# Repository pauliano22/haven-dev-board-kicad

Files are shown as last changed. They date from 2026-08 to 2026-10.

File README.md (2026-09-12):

# Haven Dev Board — KiCad Port

> **Current status (as of this commit): fabrication-ready.** Everything
> below this notice describes the *original* EasyEDA→KiCad port and was
> accurate when written, but predates the DRC/routing work that followed —
> it still says "no ERC or DRC has been run," which is no longer true. The
> board has since been rescaled to 73.1×161.1mm, fully routed (219 DRC
> violations remaining, all investigated and non-blocking; 2 cosmetic
> same-net internal BGA pairs unconnected), and DRC-verified via
> `kicad-cli`. See `FABRICATION_GUIDE.md` for current ordering instructions
> and `HAVEN_HARDWARE_REVIEW.md` for the full review trail. The rest of this
> file is kept as-is below for its record of the port's methodology and
> known limitations, most of which are still true (pin electrical types,
> unassigned pins, silkscreen fidelity, etc.) — only the DRC/routing status
> has changed.

A from-scratch KiCad recreation of the stock OpenEarable hardware (the base
Haven is built from), generated programmatically from the real EasyEDA Pro
project data rather than hand-traced from screenshots. This is **not** a
copy-paste of the user's live EasyEDA edits — it's a fresh port of the
*stock* OpenEarable design (`OpenEarable-PCB-main-2.0.epro`), per the
explicit scope agreed before this work started.

Open `kicad/haven_dev_board.kicad_pro` in KiCad. **No KiCad install or
`kicad-cli` was available in the sandbox this was built in — none of this
has been opened in real KiCad, run through ERC, or run through DRC.**
Treat the schematic as a strong first draft and the PCB as a best-effort
faithful port; both need a real review pass before anything is fabricated.
(Superseded — see the notice at the top of this file.)

## What's actually in here

| Section | Confidence | Why |
|---|---|---|
| BOM (89 parts, real values/part numbers) | High | Parsed directly from the `.epro`'s structured JSON, not guessed |
| Digital/power netlist (MCU, power management, flash, SD, USB, IO) | High | Two independent extraction methods agree exactly (see below) |
| Footprints (real pad shapes/sizes/positions) | High | Parsed directly from the real `.efoo` footprint data |
| PCB placement (component X/Y/rotation) | High | This is the **real board's actual placement**, not a guess |
| PCB routing (traces/vias/copper pours) | High for continuity, **unverified for DRC** | Real copper geometry ported directly; never run through a design-rule checker |
| Audio-analog section (ADAU1860 pins, mic, DAC) | Medium | Connectivity is real (same ground-truth source), but pin *electrical roles* (which precise decoupling network, differential pairing, etc.) haven't been cross-checked against the ADAU1860 datasheet |
| RF/antenna, USB signal integrity, any trace-width/impedance intent | **Needs real EE review** | Geometry ported as-is; nothing here was checked against RF/USB layout rules |
| Symbol/footprint graphics (visual appearance) | Cosmetic only | Pins are placed at electrically-correct coordinates but pin-stub direction and body-rectangle sizing are auto-generated, not hand-drawn — expect a plain, boxy look, not the polished look of a hand-drawn library part |

## Data source and methodology

The source is `OpenEarable-PCB-main-2.0.epro`, an EasyEDA Pro export. Unlike
the live `.eprj2` project file (an encrypted SQLite database), a `.epro` is
a zip of plaintext, line-delimited JSON records — genuinely parseable, not
reverse-engineered from pixels.

Two independent data sources were extracted and cross-checked against each
other:

1. **Schematic layer** (`.esch`, `.esym`): component placement, symbol pin
   layouts, and net-label text. EasyEDA's schematic format has no explicit
   netlist — connectivity has to be reconstructed from which pins sit near
   which net-label text. This reconstruction (`extracted/parse_netlist2.py`)
   hit two real bugs before it produced a trustworthy result, both fixed
   and documented in code comments:
   - A naive `name.split(".")[0]` truncated decimal component values
     (e.g. `"2.2uH.1"` → `"2"` instead of `"2.2uH"`), breaking symbol
     lookup for 15 parts. Fixed with a regex that strips only the trailing
     `.N` variant suffix, plus an HTML-entity unescape (BOM value strings
     use a literal `>`, symbol titles use `&gt;`).
   - The nRF5340 module's dedicated DC-DC/decoupling pins (`DECR`, `DCC`,
     `DECD`, `DCCD`, `DCCH` — per the module's own symbol pin names) were
     being swept into unrelated neighboring nets by the proximity-matching
     heuristic, since these pins sit only ~10 units from adjacent signal
     pins on a tight-pitch module. These pins are excluded from proximity
     matching entirely; per the nRF5340 datasheet they only ever connect
     to a local decoupling capacitor, never a routed signal net.

2. **PCB layer** (`.epcb`) — discovered partway through this work, and a
   materially better source: every real pad on the actual manufactured
   board has a `PAD_NET` record giving its **already-resolved** net name
   directly, plus a `COMPONENT` record giving its **real placed position
   and rotation** on the actual board. This is ground truth, not a
   reconstruction. **This is the netlist actually used in the generated
   schematic and PCB** (`extracted/pcb_netlist.json`,
   `extracted/pcb_placement.json`) — it covers ~85% of all pins vs. ~64%
   for the schematic-proximity heuristic, and every net checked against
   both sources agreed exactly (DIN, DOUT, BCLK, LRCLK, FLASH_RESET,
   SD_ENABLE, SCL1/SDA1, and the full GND net all matched).

   The PCB layer also contains real routed copper — 1003 trace segments,
   260 vias, and 6 ground/power copper pours — on a genuine 6-layer
   stackup (confirmed via `LAYER_PHYS` dielectric/copper-thickness
   records): `TOP / prepreg / GND-plane / core / Inner1 / prepreg /
   Inner2 / core / POWER-plane / prepreg / BOTTOM`. All of this routing
   was ported directly rather than re-routed from scratch.

Coordinate systems were independently reverse-engineered and validated for
each domain (schematic-space units are 10 mil per raw grid unit;
PCB-space units are 1 mil per raw unit — confirmed against overall board
span, ~13.5mm × 26.7mm, plausible for a small in-ear wearable). PCB-space
rotation was independently validated against real trace/via endpoints on
two components with 90°/270° rotations (not just 180°, which can't
distinguish rotation direction) — computed pad positions landed within
0.01 raw units (~0.0003mm) of real trace endpoints, confirming standard
CCW rotation with **no mirroring needed**, even for back-side (layer 2)
parts.

The board outline's arc segments (`POLY` records on the OUTLINE layer) use
a `(start, end, sweep-angle)` encoding with no explicit center point. The
center/midpoint formula was derived from scratch and verified in closed
form against two real corner-fillet arcs before being trusted for the
whole outline.

### Coordinate-generation strategy (why the connectivity should be trusted even without ERC)

Every generated symbol instance (schematic) and footprint instance (PCB)
is placed at **rotation zero**, with the component's real rotation baked
directly into each pin/pad's own local coordinate instead. This sidesteps
any uncertainty about whether KiCad's internal rotation transform sign
convention matches EasyEDA's: since only pure translation is asked of
KiCad, and the label/pad-net coordinates are computed with the exact same
Python expression used to place the pin/pad itself, they are numerically
identical by construction — not just "close." The actual rotation-direction
question was still independently resolved and validated (see above); this
strategy just removes it as a second, compounding source of risk.

## Known limitations / simplifications

- ~~**No ERC or DRC has been run.**~~ Superseded — see the notice at the
  top of this file. DRC has since been run extensively via `kicad-cli`
  (219 violations remaining, all investigated; see
  `HAVEN_HARDWARE_REVIEW.md`).
- **POLY-shaped pads** (rare — a few connector pads on J1/CN1 use a custom
  polygon rather than a rectangle/ellipse) are approximated by their
  bounding rectangle, not their exact polygon outline.
- **Via layer spans**: the source data's per-via layer-span field was
  empty for every via found, which is consistent with (but doesn't
  strictly prove) all-through vias. Every via is generated as a full
  F.Cu–B.Cu through via. If any are actually blind/buried, this needs
  correcting.
- **Board stackup thicknesses** are not precisely declared in the
  generated file (KiCad's default 1.6mm/2-layer-style general thickness
  is used) — the *layer names and count* (6 copper layers) are real and
  correct, but exact dielectric thicknesses from the source data were not
  carried through.
- **Silkscreen art, logos, and precise designator label placement** from
  the original board were not ported — only functional copper, pads, and
  the board edge. Reference designators use KiCad's default auto-placed
  text.
- **Pin electrical types** (input/output/power/etc.) are uniformly set to
  "passive" in the generated symbols. This was a deliberate choice: I
  don't have verified per-pin electrical-role data from any datasheet, and
  marking pins with specific types I can't back up would be fabricating
  detail I don't actually have grounds for. This means ERC in KiCad won't
  be meaningful for pin-direction conflicts until someone fills in real
  electrical types from actual datasheets.
- **~15% of pins have no assigned net** (72 of 460 PCB pads; a very
  similar fraction on the schematic side). Spot-checked and these are
  overwhelmingly genuine — reserved MCU pins (the DC-DC pins above),
  unused GPIOs, and connector pins with more physical positions than the
  design actually uses (e.g. CN1 pins 13–24, CARD1 pin 1). They are not
  silently dropped; they're just left unconnected in the generated files
  rather than fabricating a connection.

## A genuine anomaly in the *original* stock design — now resolved

One net in the real board data was literally named `#ERROR` by EasyEDA
itself (confirmed present in `extracted/netlist.json`'s raw source, not
introduced during this port) — it tied together MDBT531 pin 3 (`P1.08`,
a GPIO), Q2 pin 1 (a small MOSFET, `CSD13380F3T`), and U8 pin 1 (a 1MΩ
0201 resistor, despite the "U" designator). EasyEDA just never resolved
a human-readable name for this net.

Traced further and renamed to **`LED_ENABLE`**: R4 (510Ω) and U4 (a real
0201 LED, `XL-0201SURC`, per `HAVEN_BOM.csv`) are also on this net —
3V3 → U4 (LED) → R4 (current-limit) → Q2 (low-side switch to GND), gated
by U8 (1MΩ pulldown, default-off) and driven directly by MDBT531 P1.08.
A straightforward GPIO-controlled indicator LED. Pure rename in both the
schematic and PCB — zero electrical change, verified via DRC diff. The
net also had a genuine small routing gap (Q2's gate pad wasn't
connected to the rest of the net); that's now routed too.

## File layout

```
kicad/
  haven_dev_board.kicad_pro     project file
  haven_dev_board.kicad_sch     schematic (89 components, net labels for connectivity)
  haven_dev_board.kicad_sym     project symbol library (one symbol per component, no sharing)
  haven_dev_board.kicad_pcb     PCB (real placement, real footprints, real routing, real outline)
  footprints.pretty/            33 generated footprints
  sym-lib-table, fp-lib-table   project-local library tables

extracted/                      all extraction/generation scripts + intermediate JSON,
                                 kept for provenance and so the pipeline can be re-run
                                 (e.g. after a schematic re-export) rather than redone by hand
```

## Suggested next steps for a human pass

1. ~~Open in KiCad, run ERC and DRC, see what falls out.~~ Done — see the
   notice at the top of this file and `HAVEN_HARDWARE_REVIEW.md`.
2. Cross-check the ADAU1860 audio-analog section (U15's ~29 unmatched
   pins, mostly clustered here) against the real datasheet.
3. Review U2 (BQ25120A charger) and U6 (BQ27220 fuel gauge) — both have a
   meaningful number of unmatched pins too.
4. ~~Decide whether the `#ERROR` net circuit needs a real name/investigation.~~ Done — see above, now `LED_ENABLE`.
5. If this is meant to diverge from stock OpenEarable (per the earlier
   Gemini-assisted cleanup pass on the user's live EasyEDA project), diff
   this port against that pass and carry over the same changes here.

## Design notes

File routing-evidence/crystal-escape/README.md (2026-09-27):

# Crystal escape: the 24.576 MHz codec crystal from 6 mm to 1 mm, and the flash's cap

Follow-up to `../placement-fix/` (PR #5), which moved every crystal and
decoupling cap back next to its chip except one: the codec crystal stopped
at 6.0 mm pad-to-ball because its escape from the 0.35 mm BGA could not be
changed without re-routing. This stage re-does that escape, and fixes the
one decoupling item PR #5 mis-diagnosed (the flash *does* have a cap — C27 —
it was just 9.8 mm away).

Tooling: KiCad **9.0.8** (`kicad-cli pcb drc --format json --severity-all
--all-track-errors`, pcbnew Python from the same install), the project's
`tools/*.py`, plus `group_c_crystal_escape.py` in this directory. Acceptance
rule unchanged: zero new violation identities by type+description and
unconnected not worse (`tools/drc_diff.py`), before every commit.

## Result

`.kicad_pcb` header unchanged (`version 20241229`, `generator_version "9.0"`).

### DRC, before and after (kicad-cli 9.0.8)

| | violations | by type | unconnected |
|---|---|---|---|
| PR #5 tip `77b8ee2` (`baseline.json`) | 219 | clearance 99, lib_footprint_mismatch 78, solder_mask_bridge 33, track_dangling 9 | 2 |
| after crystal escape (`after_c.json`) | **219** | **identical multiset** | **2** |
| after C27 move (`after_d.json`) | **219** | **identical multiset** | **2** |

`drc_diff.py baseline.json after_d.json` → 0 new violation identities, 0 new
unconnected. The two remaining unconnected items are the same cosmetic
same-net U15 pairs as before.

### Distances — pad to pin

| connection | PR #5 | this PR |
|---|---|---|
| CRYSTAL1.1 (XTALI) → U15 ball B7 | 6.01 mm | **0.98 mm** |
| R28.2 (XTALO) → U15 ball B6 | 4.47 mm | **3.26 mm** |
| R28.1 → CRYSTAL1.3 | 0.86 mm | 1.16 mm |
| C46 (33 pF) → CRYSTAL1.1 | 1.10 mm | 1.03 mm |
| C45 (33 pF) → CRYSTAL1.3 | 0.98 mm | 1.08 mm |
| C27 (100 nF, V_LS) → U14 ball D2 | 9.78 mm | **0.21 mm** |
| C27 GND pad → U14 ball E3 | — | 0.49 mm |

### Net copper

| net | PR #5 | this PR |
|---|---|---|
| XTALI (ball → crystal) | 9.02 mm track, 3 vias | **2.84 mm, 2 vias** |
| XTALO (ball → R28) | 5.09 mm, 3 vias | **4.48 mm, 2 vias** |
| `$1N16368` (R28 → crystal) | 1.89 mm | 2.24 mm |

## How the escape works now

The only exits from balls B6/B7 are their existing via-in-pads (kept). From
there:

- **On B.Cu** TDO's escape track runs 0.17 mm east of the XTALI via and walls
  the pocket off; **on In4** SCL1's escape diagonal does the same. That is
  why PR #5 stopped at 6 mm.
- **On In2** (the second GND plane) there is nothing in this corner except
  the through-via field, and XTALI/XTALO already carry the board's per-pair
  `.kicad_dru` exceptions for exactly those vias (XTALI vs TDO 0.015 mm;
  XTALO vs TMS/TDO/XTALI 0.03–0.05 mm, plus matching `hole_clearance`
  rules). So each net now goes: ball → via-in-pad → ~1–3 mm on In2 → new
  0.20/0.10 exit via → B.Cu stub → pad. XTALI's In2 run is a single 0.9 mm
  segment; XTALO's leaves its via south-west (the one gap in the TMS/TDO/
  XTALI ring), runs under row A and exits south of the crystal next to R28.
- **The crystal is on B.Cu at (61.30, 112.35), rotated 225°.** The free
  pocket east of the BGA is a diagonal band 3.5 mm across between SDA1's and
  PDMDIN's slope-1 escapes; the 1.9 × 2.3 mm crystal only fits with its long
  axis along the band, i.e. at a 45° multiple. 45° placement is routine for
  PCBA. C46 sits 1.0 mm from the XTALI pad with its own GND via; C45 and R28
  sit off the far pad; the crystal's two case/GND pads each have a via into
  the planes.
- Every new via and segment was checked before placement against copper
  clearance (the net's own exceptions, never looser), hole clearance
  (0.15 mm default, pair rules where they exist) and hole-to-hole
  (0.20 mm edge, real drill sizes) — then DRC was the judge.

**Trade-off, stated plainly:** XTALI — the high-impedance oscillator input,
the node that matters most — is now 0.98 mm from its ball with 2.8 mm of
copper. XTALO (the driven, low-impedance side) is 3.26 mm to R28 and ~4.5 mm
of copper because R28 has to sit off the crystal's far pad in this
orientation; rotating the crystal to balance the two legs (135°/315°) put
XTALI at ~2.1 mm, which is the worse trade. Two In2 tracks now cut ~1.5 mm
slots in the GND pour under the BGA corner (through the existing via field,
where the pour is already perforated); refill and DRC show no GND
connectivity change.

## The flash's decoupling cap — C27, not a new part

PR #5's README concluded "U14 has no dedicated decoupling cap on this BOM".
That was wrong: **C27** (100 nF, `V_LS`/`GND`, 0201, `TCC0201X5R104M6R3ZT`)
is drawn immediately beside U14 on the schematic and is its cap by design;
the 5× rescale had left it at (97.86, 117.83), 9.8 mm away. Stage D moves it
to B.Cu directly under the flash: V_LS pad 0.21 mm from ball D2, GND pad
0.49 mm from ball E3 (`tools/move_two_terminal.py --ref C27 --ic U14`, old
feeds removed with `clean_dangling.sh`). **No BOM change.** If Paul wants
bulk capacitance for the QSPI flash as well (a 1 µF alongside the 100 nF is
common practice, not a requirement), that would be a BOM addition for him to
decide — not done here.

## Tooling lessons (both caught by the DRC gate)

- **Refill zones on the board in the project directory, never on a copy in
  /tmp.** A board loaded without its `.kicad_pro`/`.kicad_dru` alongside
  fills its pours with different settings: refilling the *untouched* PR #5
  board from /tmp produced 5 phantom `track_dangling`/`via_dangling`
  warnings and 4 phantom unconnected items (U15 GND/V_LS balls, a GND via
  pair 20 mm away); the same board refilled from `kicad/` reproduced the
  baseline exactly. `group_c_crystal_escape.py` copies its best snapshot
  into the project before the final refill. (`CODEX_NOTES.md` already
  warned about /tmp copies and design rules; this is the zone-fill face of
  the same problem.)
- pcbnew 9 hands back an unusable board object after `Remove()` + `Save()`
  + `LoadBoard()` in one process, so the script strips the old copper in
  one process (`--phase strip`) and places/routes in another (`--phase place`).
- `placement_lib.layer_id` only knew F.Cu/B.Cu; it now knows the inner
  layers.

## Files

- `baseline.json` — DRC at PR #5's tip; `after_c.json` (crystal escape);
  `after_d.json` (C27 move).
- `group_c_crystal_escape.py` — the crystal-group script (run from `kicad/`
  with KiCad's python: `--phase strip`, then `--phase place`).
- `../../tools/placement_lib.py` — inner-layer names added.

`fab_output/` is not tracked; regenerate before ordering, per
`FABRICATION_GUIDE.md`:
```
kicad-cli pcb export gerbers --output fab_output/gerbers/ kicad/haven_dev_board.kicad_pcb
kicad-cli pcb export drill   --output fab_output/gerbers/ kicad/haven_dev_board.kicad_pcb
kicad-cli pcb export pos --format csv --units mm --side both --output fab_output/haven_dev_board-pos.csv kicad/haven_dev_board.kicad_pcb
```

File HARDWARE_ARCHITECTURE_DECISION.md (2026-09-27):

# Hardware architecture decision: keep the codec in the loop, lose the BGA

*Response to `HARDWARE_COST_ALTERNATIVES.md` (2026-09-12). Written 2026-09-14.*

## The answer in one paragraph

The cost analysis is right and the conclusion is half right. The three fine-pitch packages (ADAU1860 0.35 mm BGA-56, BQ25120A 0.40 mm DSBGA-25, BQ27220 0.50 mm DSBGA-9) are what push the board into 6 layers, laser microvias and the "advanced" PCBA tier, and swapping them for QFN parts is the correct way to get a cheap board. But the ADAU1860 was not "the wrong chip for the codec role" — it was chosen (inherited, but correctly) because it is the mechanism for Haven's one hard physical requirement: hear-through latency well under a millisecond. Moving the biquads onto the nRF5340 (option C below) reintroduces I2S block buffering of **≥0.7–1 ms at the smallest practical block, and ~6–9 ms if done the way the Teensy prototype did it**, which puts comb-filter notches inside the speech band (derivation §3) and keeps the nRF CPU + I2S running continuously (**≈5.6 mA**, §4) instead of asleep. The Teensy prototype proved the *filter math*; its latency was never measured. There is a third option that satisfies both the physics and the cost: a QFN codec **with its own programmable DSP** — the TI **TLV320AIC3254** Paul already found in JLCPCB's catalog at $3.03 (VQFN-32, 5×5 mm, **0.5 mm pitch**, PDM mic input, two miniDSP cores each running up to **1,152 instructions per sample at 48 kHz**, plus fixed processing blocks with **5 programmable biquads** and a DRC). Recommendation: **option B (AIC3254 in the loop), with the charger swapped to a QFN/SOP power-path part and battery voltage read by the nRF's ADC instead of a fuel gauge** — and one cheap experiment first (§7) to pin the latency numbers this memo can only estimate.

## 1. The three options

| | **A — current** | **B — QFN codec with on-chip DSP** | **C — dumb codec, filter on nRF5340** (Paul's proposal) |
|---|---|---|---|
| Codec | ADAU1860 (BGA-56, 0.35 mm) — FastDSP owns mic→5 biquads→limiter→DAC at 192 kHz; nRF only writes coefficients | **TLV320AIC3254** (VQFN-32 5×5 mm, 0.5 mm) — miniDSP or fixed biquad blocks own the loop; nRF only writes coefficients | SGTL5000 / TLV320AIC3104 / AIC3254-as-dumb-codec (QFN) — ADC→I2S→nRF→I2S→DAC; nRF runs the biquads |
| Where the audio loop runs | inside the codec | inside the codec | through the MCU |
| Hear-through latency (§3) | converter delays only: est. **50–150 µs** (192 kHz path); FastDSP frame 5 µs | converter delays at 48 kHz: est. **0.5–1 ms** (TI publishes block group delays in SLAA408 — not fetched; 96/192 kHz modes would cut it); DSP adds ~0 | converter delays **+ I2S block buffering**: ≥ **0.7–1.0 ms** extra at 16-sample blocks, **2.7–4 ms** at 64, **5.8–8.7 ms** Teensy-style (128 @ 44.1 k) |
| Comb notches in 200–8000 Hz (§3) | 0 (first notch ≥ 3.3 kHz only if Δt ≥ 150 µs; none below 100 µs) | 0–1 if Δt ≤ 0.5 ms; up to 8 at 1 ms | 8 at 1 ms; ~47 at 6 ms |
| MCU power for audio (§4) | ~0 (nRF sleeps between BLE events) | ~0 | **CPU 3.3 mA @64 MHz + I2S 2.3 mA ≈ 5.6 mA continuous** (Nordic PS) |
| Codec power | unknown (datasheet not obtained); ADI markets the part for hearables | **4.1 mW playback + 6.1 mW record ≈ 10 mW** (datasheet p.1; both paths run in hear-through) | same class as B (converters still run) **plus** the MCU 5.6 mA |
| Unit BOM (codec) | consignment part, ~$5–10 (est.) | **$3.03** (JLC catalog, Paul) | $1.33 AIC3104 / SGTL5000 |
| Layers / vias / PCBA tier | 6 layers, laser microvias, advanced (~$500 / 5 boards, Paul's quote) | **plausibly 4 layers, standard vias, standard tier** (MDBT53 is 0.65 mm pitch) | same as B |
| Firmware chip-specific code to (re)write | exists: `adau1860_*`, `lark_*` ≈ 1,420 lines, compiles for both boards | new: AIC3254 register driver ≈ 400–600 lines (I2C register pages; no 32-bit addressing, no memory images unless miniDSP is used) | new: codec init ≈ 200 lines **+** an nRF DSP path (I2S RX/TX ring, biquad kernel, timing) ≈ 300–500 lines that must be real-time-safe |
| Firmware that survives unchanged | — | BLE, protocol, clamps, tone safety, NVS, GATT, acks, `tone_gen.c` (I2S master), calibration rig, app: ≈ 1,800 of 3,240 firmware lines + all tools + the whole app | same |
| DSP tooling | Lark Studio (Windows) for anything beyond coefficient writes | **none needed** for the fixed blocks (5 biquads + DRC are register-programmable, datasheet Tables 2/3); PurePath Studio (TI, access-controlled) only if the miniDSP is used | none (C code) |
| Hardware limiter (3rd safety layer) | FastDSP limiter slot (PR #14) | **DRC on ADC path, AGC / digital volume on DAC path** (datasheet p.1, p.31) — register-programmable | firmware only (a bug is a loud bug) |
| Sourcing risk | ADAU1860 + MDBT53 likely consignment at JLC/PCBWay | catalog part; MDBT53 still consignment | catalog part; MDBT53 still consignment |
| Time to first sound | firmware done; hardware = eval board $485 / OpenEarable €2,348 / this BGA board | **TLV320AIC3254EVM** exists (TI, ~$100–200) → DK + EVM bench; new schematic; ~1 week of driver work | as B plus the nRF DSP path and its latency debugging |

Confidence: package/pitch, instruction budget, PDM input, power figures and DRC/AGC for the AIC3254 are **verified** from the datasheet (SLAS549D: p.1, p.30–31, p.34, p.50). nRF5340 currents **verified** (product specification, "Current consumption"). Latency figures are **derived** (§3) from block sizes and the published block-processing model; converter group delays are **estimated** and must be measured. Costs are Paul's or JLC catalog figures.

## 2. Why the loop has to stay in the codec — the physics, restated

Hear-through only works if the processed sound and the sound that leaks past the eartip arrive together. If the processed path is late by Δt, the two add with a phase that rotates through frequency, producing comb-filter notches at

    f_k = (2k + 1) / (2·Δt),  k = 0, 1, 2 …

(notebook `01-acoustics-and-psychoacoustics.md`). For the 200–8000 Hz band Haven cares about:

| Δt | notches in band | first notch |
|---|---|---|
| 50 µs | 0 | 10 kHz |
| 150 µs | 2 | 3.3 kHz |
| 300 µs | 4–5 | 1.7 kHz |
| 1 ms | 8 | 500 Hz |
| 4 ms | ~32 | 125 Hz |
| 6 ms | ~47 | 83 Hz |

Anything above ~0.3 ms audibly colours speech; above ~1 ms it sounds like "two of everything". This is the requirement (R1 in `00-problem-breakdown.md`) that dictated a codec-resident DSP in the first place. It is also why the Teensy prototype, valuable as it was, does not settle the architecture: it validated the filters and the user experience of *notching*, but nobody measured its latency (there is no measurement in `haven-legacy-teensy`, `haven-legacy-dsp-sandbox` or the workspace docs — checked), and its block size makes the number predictable (§3).

## 3. Latency derivations

**Common to all options — converter group delay.** Sigma-delta ADCs and DACs use linear-phase decimation/interpolation filters whose delay is a fixed number of samples: at 48 kHz, tens of samples each way ⇒ roughly 0.3–0.6 ms per direction for ordinary codecs. The ADAU1860 runs its DMIC decimation and FastDSP at **192 kHz** (upstream `DMIC_CTRL2 = 0x04`, `FDSP_CTRL4 = 2`), so the same filter structures cost 4× less time — that is the specific reason option A's latency is estimated at 50–150 µs. The AIC3254 lists three interpolation filter types "depending on required frequency response, group delay and sampling rate" (p.31) and processing blocks "tuned for … low group delay" (p.30–31); the numbers are in TI's app note SLAA408, which was not fetched — **measure, don't assume**. At 96 or 192 kHz DAC/ADC rates (both supported, p.31) the AIC3254 figure would shrink accordingly.

**Option C adds block buffering.** Zephyr's nRF I2S driver (`drivers/i2s/i2s_nrfx.c`, NCS 3.4) is double-buffered EasyDMA: an RX block is delivered to the application only when it is full; the application processes it and queues a TX block, which starts playing at the *next* block boundary. Minimum end-to-end through the MCU is therefore about two block durations plus processing, three in practice with the TX queue depth the driver needs to avoid underrun ("Next buffers not supplied on time" is a hard error that stops the stream). Block size must be a multiple of 4 bytes; very small blocks mean interrupt rates the BLE stack has to coexist with.

| Block (samples @ 48 kHz) | block time | MCU path (2–3 blocks) | IRQ rate | + converters (~0.7 ms est.) |
|---|---|---|---|---|
| 16 | 0.33 ms | 0.67–1.0 ms | 3,000/s | **1.4–1.7 ms** |
| 32 | 0.67 ms | 1.3–2.0 ms | 1,500/s | 2.0–2.7 ms |
| 64 | 1.33 ms | 2.7–4.0 ms | 750/s | 3.4–4.7 ms |
| 128 @ 44.1 kHz (Teensy `AUDIO_BLOCK_SAMPLES`, `cores/teensy4/AudioStream.h:54`) | 2.9 ms | 5.8–8.7 ms | 344/s | **6.5–9.4 ms** |

So the Teensy prototype almost certainly ran at 6–9 ms — dozens of comb notches across the speech band. If it sounded acceptable, that is evidence the *user experience* was tested with music/voice sources in a quiet room rather than as transparent hear-through against leakage, or that the earpiece sealed well enough to suppress the leaked path. Either way it is not evidence that MCU-side filtering meets R1. The 16-sample case is the best C can do, and it is still ≥ 3× worse than B's converter-only estimate, at 3,000 interrupts per second forever.

**The CPU load itself is not the problem.** Five biquads on one channel at 48 kHz is ~2.5 MIPS in fixed point — trivial for a Cortex-M33 at 64 MHz. The problem is buffering latency and the fact that the CPU can never sleep.

## 4. Power

Nordic nRF5340 product specification, "Current consumption" (typ., 3 V, DC/DC on): CPU running from flash at 64 MHz **3.3 mA**; at 128 MHz **7.8 mA**; I2S transferring 2×16-bit at 48 kHz **2.31 mA**; System ON idle **1.3 µA**. Option C therefore holds the application core at ≈ **5.6 mA** (64 MHz) continuously, on top of the BLE stack. Options A and B leave the nRF in System ON idle between BLE events (advertising/connection events average tens of µA).

Codec side: AIC3254 **4.1 mW** stereo playback + **6.1 mW** stereo record at 48 kHz (datasheet p.1) — hear-through needs both, so ≈ 10 mW; mono and lower PowerTune classes (PTM_R1…) reduce it. ADAU1860: no figure obtainable here (datasheet unfetched); ADI positions it for hearables and OpenEarable runs it from an earbud battery, so assume the same class as the AIC3254 or better — **unknown**.

Battery: the OpenEarable 2.0 battery capacity is not stated anywhere in the upstream repo (the fuel-gauge default `capacity_mAh = 3000` in `BQ27220.h` is a placeholder); a typical earbud cell is 40–80 mAh. Taking **60 mAh** as a stated assumption and ≈ 6 mA for a codec in hear-through plus BLE:

- A/B: 60 mAh / ~6.5 mA ≈ **9 h**
- C: 60 mAh / ~12 mA ≈ **5 h**

Roughly, option C halves the wearable's battery life to buy nothing the user can hear except comb filtering. (Assumptions explicit; the codec numbers dominate and must be measured on the bench — the calibration rig PR #11 includes a battery-current line item for exactly this.)

## 5. Cost and manufacturability

Paul's measurements stand: ADAU1860 0.35 mm, BQ25120A 0.40 mm, BQ27220 0.50 mm pitch; MDBT53-1M 0.65 mm. Removing the three fine-pitch parts removes the need for laser microvias and (plausibly) two layers, and moves the job out of the advanced tier. Option B keeps that entire saving: the AIC3254 is a 0.5 mm-pitch VQFN-32 (datasheet p.50), catalog-stocked at JLC ($3.03), and the MDBT53 is fine as is.

Two things `HARDWARE_COST_ALTERNATIVES.md` does not yet account for:

1. **The BQ25120A is also the board's power supply.** Its integrated buck (L2, 2.2 µH) and LDO generate the **+1.8 V** and **3V3** rails (notebook `10-hardware-bom.md`, power tree). Replacing it with a TP4056 or MCP73831 — which are chargers only — means adding a regulator (e.g. a small buck or LDO for 1.8 V, plus the 3V3 rail if anything still needs it) and a load switch strategy for ship/storage. Not hard, but it is a new part and a new design task, not a drop-in.
2. **Battery telemetry.** True, nothing in the software reads the BQ27220 today. But a wearable without a battery percentage cannot warn the user, cannot protect the cell from deep discharge in firmware, and cannot implement ship mode (the BQ25120A's ~nA storage state). The cheap answer is not a QFN fuel gauge: it is a resistor divider (or the charger's battery pin) into the **nRF5340's SAADC** for voltage-based state of charge — good enough for "low battery", zero BOM cost — and a charger with a **power path** so the device runs from USB while charging. In increasing capability: TP4056 (SOP-8, linear 1 A, thermal regulation, no power path, no ship mode), MCP73831 (TDFN-8, 500 mA, no power path), **BQ24072/BQ24074** (QFN-16, power path/DPPM, no I2C) — the last is the one that behaves like a product.

## 6. The claims in `HARDWARE_COST_ALTERNATIVES.md`, one by one

- **"The cost isn't the board size … it's three specific chip packages."** Agreed, and well shown (measured pitch, flat assembly setup cost, laser-via finding).
- **"OpenEarable 1.3 is architecturally wrong (record-then-playback)."** Agreed.
- **"6 layers are caused by the BGA escape."** Agreed.
- **"The fuel gauge is unused by software."** True today; see §5 for why telemetry still matters and how to get it for free.
- **"Same architecture, wrong chip — the Teensy proves the nRF can do the filtering."** Disagree on the architecture, agree on the chip's *package*. The Teensy proved the math and the interaction, not the latency (§3); a codec-resident DSP is what makes sub-millisecond hear-through possible, and dropping it is the one change that alters what the product *does*, contrary to the memo's framing. The right move is a QFN codec that keeps the DSP in the loop.
- **"TLV320AIC3253/3254 is a drop-in-shaped replacement."** Agreed — and stronger than stated: the AIC3254's fixed ADC processing blocks **PRB_R2/PRB_R5 carry five programmable biquads** (datasheet Table 2, p.30) and the DAC blocks carry more plus a DRC (Table 3, p.31), all register-programmable over I2C without any DSP tool. Its two miniDSP cores (1,152 instructions per sample at 48 kHz, "can exchange data", p.34) are the upgrade path if anything more than notches is ever wanted. (Note: the datasheet is for the AIC3254; the "3253" in the memo appears to be a typo — the JLC catalog line Paul quoted is AIC3254IRHBR.)

## 7. Recommendation and the cheapest experiment that settles it

**Recommend option B**: TLV320AIC3254 (RHB), PDM mic into its digital-mic input, hear-through implemented inside the codec, a QFN power-path charger (BQ24072-class) plus an SAADC battery-voltage read, MDBT53-1M unchanged. This keeps R1 (codec-owned loop), keeps every codec-agnostic piece of firmware and the whole app, removes all three fine-pitch packages, and uses catalog parts.

Two unknowns decide whether B delivers A's latency or merely beats C:

1. **Is there a fully internal ADC→DAC digital path on the AIC3254 that runs through the biquad blocks?** The datasheet's fixed processing blocks sit on the ADC and DAC paths with the serial interface in between; the miniDSP cores "can exchange data" (p.34), which is an internal path but needs PurePath Studio. If a register-level ADC→DAC route exists (to verify in SLAA408 / the register map), B needs no DSP tool at all; if not, B uses the miniDSP.
2. **What are the AIC3254's ADC + DAC group delays at 48 / 96 / 192 kHz?** SLAA408 has them; the bench will confirm.

**Cheapest experiment (≈ $200, one week, no custom PCB):**

- **Step 1 — nRF5340 DK alone, $0:** loop I2S SDOUT→SDIN with a jumper and measure the Zephyr I2S round-trip for 16/32/64-sample blocks (GPIO toggle at RX-block-ready and TX-start, logic analyzer or `k_cycle_get_32`). This nails option C's buffering term with no codec at all.
- **Step 2 — TLV320AIC3254EVM-U (TI) + DK:** configure PRB_R2 with Haven's five biquads via I2C, drive the PDM mic input, measure hear-through latency by impulse cross-correlation (PR #11's `latency.py`) at 48 and 96 kHz, and measure supply current. If Δt ≤ 300 µs, B is confirmed as the product path.
- **Step 3 (optional, $485) — EVAL-ADAU1860EBZ + DK:** same measurements on option A, using the driver in PR #9, to know exactly what the BGA buys.

**What changes in the open PRs if B is chosen:** PRs #8 (format analysis), #9, #10's codec half, #13, #14 become reference material for the bench, not the product; `tone_gen.c`, the BLE/protocol/safety/ack layers (#10's nRF half, #12), the calibration rig (#11), the app PRs (#6–#8), and the documentation PRs carry over unchanged. The board PRs (#3, #5) still document the current design correctly but the placement work would be redone on a new, smaller schematic — designed right from the start, as `HARDWARE_COST_ALTERNATIVES.md` already says.

**What I would not do:** ship option C to save $3 of codec. It trades the product's defining property for a cheaper part while the cheaper part with the right property sits in the same catalog.

---

*Sources.* TLV320AIC3254 datasheet SLAS549D (rev. Nov 2014): p.1 features/power, p.30 Table 2 ADC processing blocks, p.31 DAC section/Table 3, p.34 miniDSP ("up to 1152 instructions on every audio sample at a 48kHz sample rate"; "very-low group delay"), p.27 Table 1 (DMDIN/DMCLK multifunction pins), p.50 RHB mechanical (5×5 mm, 0.5 mm pitch). nRF5340 Product Specification, "Current consumption" (IAPPCPU5 3.3 mA @ 64 MHz; IAPPCPU4 7.8 mA @ 128 MHz; II2S2 2.31 mA; ION_IDLE2 1.3 µA). Zephyr `drivers/i2s/i2s_nrfx.c` (NCS `ncs-v3.4-branch`). PaulStoffregen/cores `teensy4/AudioStream.h:54,58` (`AUDIO_BLOCK_SAMPLES 128`, 44.1 kHz). Upstream OpenEarable `ADAU1860.cpp` (192 kHz DMIC/FastDSP). `HARDWARE_COST_ALTERNATIVES.md`, `FABRICATION_GUIDE.md` (this repo). Notebook notes 00, 01, 10, 12 (`victorzhu443/haven-engineering-notes`). ADAU1860 datasheet and SLAA408 were **not** obtainable in this environment; every figure that depends on them is marked estimated.

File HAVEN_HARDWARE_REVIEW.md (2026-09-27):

# Haven Dev Board — Hardware Design Review

Reviewer notes on the KiCad port in this repo (`kicad/`), written against the
files as generated, plus one real external datasheet lookup (cited below).
**No KiCad install is available in this environment — nothing here was
run through ERC/DRC.** Every finding below states its own confidence level:
tool-verified (parsed from the actual generated files or measured from real
coordinate data), general-best-practice inference, or genuinely unresolved.

Audit scripts used: `extracted/sexp_parser.py` (independent S-expression
parser, written fresh for this review rather than reusing the generator's
code path), `extracted/audit_schematic.py`, `extracted/audit_pcb.py`.

---

## 0. Cross-check against upstream OpenEarable firmware (2026-09-10)

Several of the questions this review left open turn out to be answered by a
source that was in the workspace all along: the upstream
[`OpenEarable/open-earable-2`](https://github.com/OpenEarable/open-earable-2)
firmware, which drives this exact codec on this exact board (Haven's KiCad
port is of the stock OpenEarable main PCB, so upstream's devicetree and
driver *are* ground truth for how these nets are actually used). Everything
below is **sourced from upstream code**, not from the ADAU1860 datasheet —
the datasheet PDF was not fetchable in the environment this cross-check was
done in, so nothing here is "datasheet-verified"; it's "matches firmware
that ships on this hardware". File references are into a clone of upstream
at its 2026-09 `main`.

### 0.1 The codec's register map is public and already transcribed

The premise in `haven-zephyr-app` that "there is no public ADAU1860
register map" is wrong. Upstream's `src/drivers/ADAU1860.h` carries the
full map (~350 named registers, `VENDOR_ID = 0x4000C000` through
`DAC_NOISE_CTRL1 = 0x4000CC12`), and `src/drivers/ADAU1860.cpp` is a
working bring-up sequence for it. Two consequences for this board's
firmware, both firmware-side rather than layout-side, but recorded here
because the review's §1 was reasoning about them:

- **Control-port addressing is 32-bit**, not the 16-bit big-endian
  framing used by older SigmaDSP parts (`ADAU1860.cpp:512-517` builds a
  4-byte address for every read, `:544-549` for every write). A 16-bit
  framing simply addresses nothing on this chip.
- **The DSP program is a raw memory image**, not a SigmaStudio `ADISIGM`
  blob: `Lark-fdsp.c` ("Lark" is ADI's codename for the ADAU1860) is
  plain `uint32_t` arrays written straight to `FDSP_PROG_MEM = 0x40008000`
  and the three parameter banks (`ADAU1860.cpp:335-341`). The design tool
  for this chip is ADI's **Lark Studio**, not SigmaStudio+ — per the
  EVAL-ADAU1860 user guide (UG-2017), its "Download to Target" writes
  exactly these parameter + command words into FastDSP memory, and the
  FastDSP input source is chosen in its drag-and-drop schematic.

### 0.2 §1 resolved: DIN/DOUT direction, and I2S master/slave

**DIN/DOUT — the flagged discrepancy was real, and the overlay comment was
the backwards one.** Upstream's pinctrl
(`boards/teco/openearable_v2/openearable_v2_nrf5340_cpuapp_common-pinctrl.dtsi:14-17`)
puts `I2S_SDOUT` on P0.28 and `I2S_SDIN` on P0.31. This review's §1 table
has net `DIN` on MDBT531 pin 60 = P0.28 and `DOUT` on pin 56 = P0.31. So:

| Net | nRF pin | nRF role (upstream pinctrl) | ADAU1860 pin (this port) | Direction |
|---|---|---|---|---|
| `DIN`  | P0.28 | `I2S_SDOUT` | C1 `SDATAI_0` | **nRF → codec** |
| `DOUT` | P0.31 | `I2S_SDIN`  | B1 `SDATAO_0` | **codec → nRF** |

The net names are from the *codec's* point of view, and the ADAU1860's own
pin names (`SDATAI` = input, `SDATAO` = output) were telling the truth
after all. The `haven-zephyr-app` overlay's "DIN (ADAU1860->nRF)" comment
is inverted; see the ADAU1860 driver PR on `haven-zephyr-app` for the fix.

**Master/slave — the overlay's 2026-08-25 inference ("codec has its own
24.576 MHz crystal, therefore codec is I2S master, nRF is slave") reaches
the wrong conclusion.** Upstream runs the **nRF5340 as I2S master**:
`I2S_SCK_M` on P1.10 and `I2S_LRCK_M` on P0.30 (pinctrl `:14-15`, the `_M`
suffix is Nordic's master-mode pin function), with an `I2S_MCK` output on
P1.14 (`:10`) and `hfclkaudio-frequency = <12288000>` in the board DTS
(`openearable_v2_nrf5340_cpuapp_common.dts:51`). The codec is the slave.
The crystal doesn't contradict this: the ADAU1860 has asynchronous
sample-rate converters precisely so its internal clock domain can run off
its own crystal while its serial port follows an external bit clock —
upstream enables them (`ASRC_PWR`, `ASRCI_*`/`ASRCO_*` routing,
`ADAU1860.cpp:164-209`). §1's "the schematic genuinely cannot settle
master/slave" stands as a statement about the schematic; upstream's
firmware settles it.

### 0.3 §3.5 checklist items, revisited

- **Item 2 (DIN/DOUT):** resolved above.
- **Item 3 (AGND/DGND split):** still a real layout question, but its
  urgency is lower than §3.1 implies — the unified `GND` pour is exactly
  what the stock OpenEarable board ships with, and that board produces
  usable audio in the field. Treat as "improve on rev 2", not "blocks rev 1".
- **Item 6 (unused second serial port / `DMIC23`):** upstream leaves
  `SPT1_*` unused as well and only drives `DMIC01` (`ADAU1860.cpp:168-169`
  powers DMIC channels 0 & 1 only), so the dangling `_1` port and `DMIC23`
  pins match the working reference. Whether they need a defined pull is
  still a datasheet question, but the stock board evidently gets away
  without one.
- **Power sequencing the codec actually needs** (not on the original
  checklist, added because the port's netlist confirms the wiring):
  `DAC_ENABLE` — MDBT531 pin 37 → U15 E4 — is the codec's enable/PD pin,
  driven as `enable-gpios = <&gpio0 4>` in upstream's DTS (`:130`) and
  asserted at `ADAU1860.cpp:58`; `V_LS` is a load-switched rail
  (`load_switch`, `enable-gpios = <&gpio1 11>`, DTS `:26-28`); upstream
  then waits 35 ms for common-mode rise (`:71`), bypasses/configures the
  PLL (`CLK_CTRL13`, `:88-117`) and polls `STATUS2` bit 7 for power-up
  (`:95-105`). I2C address `0x64` is confirmed by upstream's DTS (`:127`).
- **The mic path never touches the nRF.** `U13` (`SPH0641LU4H-1`) is a
  **PDM** mic; the netlist has it on `PDMCLK`/`PDMDIN` → U15 C4/C5 (the
  codec's DMIC pins), also brought out on the flex connector `CN1` pins
  5/7. So mic audio goes mic → codec → (FastDSP) → DAC → `DAC_P`/`DAC_N`
  → speaker, entirely inside the codec, and the nRF only ever writes
  coefficients over `SDA1`/`SCL1`. Note for `haven-hardware`: the
  `SPH0645LM4H-B` in `haven_dev_board/component_libraries/` is an **I2S**
  mic — the wrong interface class for this topology; the stripped-down
  board wants a PDM part like the `SPH0641LU4H-1` that's actually here.

### 0.4 §3.4 HPVDD / HPVDD_L — still unresolved

Nothing in upstream's DTS or driver mentions an `HPVDD` net either; the
codec's headphone supply is configured in registers (`HP_LVMODE_CTRL*`,
`HPLDO_CTRL`, `ADAU1860.cpp:255-266`), which suggests the callout may have
referred to a supply/trace *inside* the codec's own power arrangement or to
a note on the live EasyEDA schematic. Still needs whoever read it off the
live schematic to point at the net.

### 0.5 §8 (U1: BMX160 vs BMI160) — a second data point, not a reversal

Upstream's devicetree declares the IMU as `bmx160: bmx160@68`
(`openearable_v2_nrf5340_cpuapp_common.dts:175`) and ships a BMX160 driver
(`src/SensorManager/BMX160/DFRobot_BMX160.{h,cpp}`) — i.e. the reference
firmware believes a 9-axis BMX160 is on the board. That is in tension with
§8's wiring-based argument for BMI160. Both are real evidence; neither is a
part number read off a chip. Recording this rather than flipping the BOM
back: **check the physical part marking on an assembled board (or ask the
OpenEarable team) before any production order.** Irrelevant to audio
either way — nothing in Haven's firmware touches the IMU.

### 0.6 Two practical consequences

- **Hardware paths (none cheap).** Since this section was first written the
  board itself has moved: it is now a 5× rescaled **bench** board
  (73×161 mm, §9), routing-complete except two cosmetic same-net BGA pairs,
  with the antenna keepout implemented (§3.2) and a `FABRICATION_GUIDE.md`
  for turnkey PCBA. That makes it a real third option alongside (a) an
  nRF5340 DK + ADI's EVAL-ADAU1860EBZ (~$485 at Newark, ~$535 total; DMIC
  on header P44, serial port 0 on P2, USB for Lark Studio) and (b) a stock
  OpenEarable 2.0 (Developer Starter Bundle €2,348), which *is* this design
  at 1×. **Before ordering the bench board, read §0.7** — the rescale moved
  the crystals and decoupling caps far from their chips, and that is a
  placement-only fix that is cheap now and expensive after assembly.
  Note also that `FABRICATION_GUIDE.md`'s "firmware ADAU1860 driver
  currently stubbed" is stale: the driver PR on `haven-zephyr-app` (#9)
  compiles for this board target and replaces every stub.
- **The DSP-side work that remains** is not a SigmaStudio blob or a
  parameter-RAM map: upstream's FastDSP program already has five biquad
  slots with hardware safeload (`FDSP_SL_ADDR`/`FDSP_SL_P*`/
  `FDSP_SL_UPDATE`, `ADAU1860.h:181-202`, used at `ADAU1860.cpp:407-425`),
  coefficients in Q5.27 (`src/audio/Equalizer.cpp:10-11`; cross-checked
  against RBJ math — the 150 Hz peaking row matches to five decimals).
  What's missing is a program variant whose *input* is the DMIC rather
  than the I2S port (upstream's takes I2S from the phone) — in Lark
  Studio that's an input-source choice in the FastDSP schematic (UG-2017
  pp. 6-7 route `AIN1`/`ASRCI0` in their example). One caveat that matters
  for this board: upstream frame-clocks FastDSP from the **192 kHz** DMIC
  stream (`ADAU1860.cpp:343`, `FDSP_CTRL4 = 2`), and UG-2017 says the
  filter fs must equal the FastDSP source rate (`FDSP_RATE_SOURCE`), so
  coefficient math must use whichever rate the program actually runs at.
  UG-2017 also confirms `EQ_ROUTE` selects the hardware EQ engine's input
  ("set fs to be same as the equalizer source, EQ_ROUTE").

### 0.7 The 5× rescale moved the parts that must stay close (2026-09-11)

Footprint-centre distances measured from `kicad/haven_dev_board.kicad_pcb`
at master `1e7c6d2` (byte-identical to `experiment/codex-astra-routing` for
this file), against the values §3.3 measured on the 1× port. Spreading a
board 5× and re-routing is fine for I2C, I2S, PDM and BLE (the radio is
inside the module) — but a handful of two-terminal nets are *supposed* to
be millimetres long, and the rescale stretched every one of them:

| Pair | 1× (§3.3) | 5× now | Why it matters |
|---|---|---|---|
| X1 (32.768 kHz) ↔ MDBT531 `XL1`/`XL2` | adjacent | **30.4 mm** | nRF5340 LFXO — the BLE sleep clock. Long, high-impedance traces add parasitic C and pickup; a 32 kHz crystal with ~30 mm of trace may not start or may be pulled off-frequency. The board DTS uses `load-capacitors = "external"`, so this crystal is load-bearing, not optional. |
| X1 ↔ C2 / C14 (9 pF load caps) | adjacent | 10.9 mm each | Load caps that far away stop being load caps and become antennas. |
| CRYSTAL1 (24.576 MHz) ↔ U15 `XTALI`/`XTALO` | adjacent | **13.8 mm** | The codec's entire clock domain. If it doesn't oscillate there is no audio at all; the driver's `wait_status2("power-up complete")` will time out — that is the symptom to expect. |
| CRYSTAL1 ↔ C45 / C46 (33 pF) | adjacent | 8.1 / 9.7 mm | Same failure mode. |
| U15 ↔ C33 (V_LS 10 µF) | 2.0 mm | 10.0 mm | Bare BGA with 7 supply balls and no cap within 10 mm: expect the digital-noise / ASRC-lock trouble §3.3 already warned about, worse. |
| MDBT531 ↔ C1 (+1.8 V 1 µF) | 5.2–5.9 mm | 25.9 mm | Module-side rail cap (U15 has no +1.8 V ball — an earlier draft of this row mis-paired it with the codec; corrected per the netlist in PR #5). The MDBT53 module carries some decoupling of its own, so the nRF side is less exposed than the codec. |
| U2 (BQ25120A) ↔ C16 / C18 / C22 | 2.2–2.7 mm | 10.7–13.3 mm | Charger input/output caps; ripple and EMI rather than outright failure. |
| U2 ↔ L2 (2.2 µH buck inductor) | adjacent | 12.9 mm | The switching node. TI's layout guidance wants L and the PMID cap tight to the IC; a 13 mm loop radiates and can destabilise the converter. |
| U6 (BQ27220) ↔ C21 | 1.65 mm | 8.3 mm | Fuel gauge; tolerant. |
| U15 ↔ C31 (`$1N151`, codec balls A3/B3) | — | 12.0 mm (pad→ball) | Codec supply/reference cap, not the flash's — corrected per the netlist in PR #5. (U14, the QSPI flash, has **no** decoupling cap on the BOM at all; worth adding on any respin.) |

**Status (2026-09-12):** implemented in PR #5 (`fix/crystal-decoupling-placement`) — every pair above is now 0.9–2.5 mm except the 24.576 MHz crystal, which stops at ~6 mm pad-to-ball because its escape vias sit in a B.Cu pocket bounded by TDO/SDA1/DOUT; DRC 219/2 → 219/2, identical by type. U6 ↔ C21 (8.3 mm) was left alone.

**What to do (placement-only, before PCBA):** move both crystals *and* their
load caps back against their pins (X1 + C2/C14 to `XL1`/`XL2`; CRYSTAL1 +
C45/C46 to `XTALI`/`XTALO`), and put one decoupling cap per rail within
~2 mm of U15, U2 and U14. These are all short two-terminal nets — trivial
to re-route next to the BGA escapes already solved (§9, `CODEX_NOTES.md`) —
and the rest of the 5× spread can stay exactly as it is. Re-run DRC.

**If the schedule wins and the board is ordered as-is:** plan for the nRF
LFXO not starting — build the firmware with the RC low-frequency clock
(`CONFIG_CLOCK_CONTROL_NRF_K32SRC_RC=y`, calibrated) so BLE still works —
and accept that a non-starting codec crystal has *no* firmware workaround.
Distances above are tool-verified; the failure predictions are
design-rule inference (crystal and switcher layout guidance), not
measurement. Raytac's free layout review would catch the X1 problem too.

---

## 1. Firmware cross-check: does the port's netlist match the current overlay?

Read `haven_workspace/firmware/haven_zephyr_app/boards/nrf5340dk_nrf5340_cpuapp.overlay`
(read-only) for the authoritative current values, then parsed the actual
`haven_dev_board.kicad_sch` (not the intermediate JSON) to check every claim.

**Net names and pin numbers: exact match, verified.**

| Signal | Overlay claim | Port's schematic (MDBT531 pin) | Match |
|---|---|---|---|
| I2C1 SDA1 | P1.15 | pin 47 → net `SDA1` | ✓ |
| I2C1 SCL1 | P1.00 | pin 45 → net `SCL1` | ✓ |
| I2S DIN | P0.28 | pin 60 → net `DIN` | ✓ |
| I2S BCLK | P1.10 | pin 59 → net `BCLK` | ✓ |
| I2S LRCLK | P0.30 | pin 57 → net `LRCLK` | ✓ |
| I2S DOUT | P0.31 | pin 56 → net `DOUT` | ✓ |

All six checked exactly. The ADAU1860 (U15) side also confirms the I2C bus
separation the overlay's comment claims: U15's `SDA/MISO/UART_CTRL_TX` pin
sits on `SDA1` and its `SCL/SCLK` pin sits on `SCL1` — the codec's control
port really is on the dedicated bus, not the charger/fuel-gauge's shared
SDA/SCL.

**Signal direction (DIN/DOUT) and master/slave: NOT verified — and there's a
real discrepancy worth flagging, not a clean match.**

The port's schematic only carries net *names* as text; every generated pin
is typed `passive` in the symbol library (documented in the original
README as a deliberate choice, since I have no sourced per-pin electrical-
role data). Net names and generic pin numbers say nothing about which chip
actually drives a wire. So: I have **not** verified the overlay's directional
comments — and checking against the ADAU1860's own pin *names* (which the
port does carry, straight from the original schematic's symbol data)
surfaces something worth a real look:

| nRF net | ADAU1860 pin on that net | Pin's own name suggests |
|---|---|---|
| `DIN` (overlay: ADAU1860→nRF) | U15 pin C1 | `SDATAI_0/MP6` — codec's serial-data-**input** |
| `DOUT` (overlay: nRF→ADAU1860) | U15 pin B1 | `SDATAO_0/MP5` — codec's serial-data-**output** |

Taken at face value, this is backwards from the overlay's stated direction:
a net where the codec's own pin is named "input" would mean the *nRF*
drives it, not the codec. **I'm not confident this is a real error though** —
all four ADAU1860 serial-port pins involved (`BCLK_0/MP3`, `FSYNC_0/MP4`,
`SDATAI_0/MP6`, `SDATAO_0/MP5`) carry an `MPx` (multi-purpose pin) suffix,
meaning they're documented by ADI as configurable/multiplexed pins whose
actual role depends on the ADAU1860's internal register configuration, not
a fixed hardware function. So the pin's *default* name may simply not match
how this design's firmware configures it. This needs an actual ADAU1860
register-map/datasheet check, not something resolvable from schematic data
alone — flagging it rather than either confirming the overlay or claiming a
contradiction.

One more data point on master/slave specifically: since all four relevant
ADAU1860 pins are multi-purpose/configurable, the schematic genuinely
**cannot** settle master/slave — confirming that the overlay's own
reasoning (inferring slave mode from the presence of a dedicated 24.576MHz
crystal on the ADAU1860, rather than from pin names) was the right approach
already, not a shortcut. I have nothing here that contradicts it.

Also notable: U15 has an entire *second* serial port's worth of pins
unconnected in this design — `BCLK_1/MP7`, `FSYNC_1/MP8`, `SDATAI_1/MP10`,
`SDATAO_1/MP9`, `DMIC23/MP2` all show up as dangling (see §2). The ADAU1860
appears to expose two serial audio ports; only one (`_0`) is wired here.
Worth confirming that's intentional.

---

## 2. Automated schematic cleanup

Parsed the real `.kicad_sch` (not regenerated from scratch) looking for
parsing artifacts, dangling nets, and metadata cruft.

**Fixed (safe, mechanical, zero connectivity change):**
- Two exact-duplicate net labels sitting on top of each other at the same
  coordinate (`SD_STATE_3V3` at one point, `$1N2586` at another) — both
  arose because two *different* components' pins genuinely land at the
  same schematic coordinate by coincidence, so each got its own generated
  label. Verified both underlying pin pairs really do share that net before
  removing the redundant copy; connectivity is unchanged (still 385→383
  labels covering the same 452 pins at 85.2%).

**Found and logged, not touched (need a human judgment call, not a mechanical fix):**
- **67 dangling (unlabeled) pins across 8 components.** Spot-checked all of
  them — none look like parsing bugs:
  - U15 (ADAU1860): 20 pins — the entire unused second serial port (above),
    plus other MPx pins not wired.
  - U14 (flash): 14 pins, all literally named `NC` by the part's own pinout
    — genuine no-connects.
  - MDBT531: 13 pins — all unused GPIOs, consistent with earlier hardware
    bring-up work on this project.
  - CN1 (battery connector): 12 pins (positions 13–24) — connector footprint
    has more physical positions than this design uses.
  - U1 (BMX160 IMU): 4 pins — `INT1`, `INT2`, `OSDO`, `OCSB` all unused,
    consistent with running the IMU in plain I2C mode with interrupts unused.
  - U12 (USB-C connector): 2 pins — `SBU1`/`SBU2` (sideband-use, alt-mode
    signaling) unused, expected for a non-alt-mode USB-C port.
  - U5 (KTD2026 RGB driver): pin `ST` unused — worth a datasheet check on
    what this pin does before assuming it's safe to leave floating.
  - CARD1 (microSD): pin `RSV` (reserved) unused — expected.
- **Placeholder UUIDs.** Every generated `uuid` field is a sequential
  fake (`00000000-...-000000000042` style) rather than a real random v4
  UUID. Harmless — they're only used as unique identifiers, never
  cross-referenced by value except the root sheet UUID, which I left
  alone — but cosmetically nonstandard. Logging rather than mass-editing
  hundreds of lines for a purely cosmetic, zero-risk-either-way item.

No connectivity was restructured. The 85.2%/84.3% (schematic/PCB) net
coverage figures from the original port stand unchanged.

---

## 3. Design & routing review

### 3.1 Analog/digital ground plane separation (ADAU1860)

**Tool-verified: there is no separate analog ground plane. GND is one
unified net and one unified copper pour on every layer that has a pour.**

The generated PCB's zone list has exactly one `GND` zone per inner layer
(layers 15 and 16 — see the 6-layer stackup in the main README) and no
second ground net (no `AGND`, `DGND`, or similar) anywhere in the 85-net
list. The ADAU1860's ground pins (per the schematic) tie into this same
single `GND` net alongside the nRF5340, USB, charger, and every digital
IC on the board.

This matches what a from-scratch faithful port of the *stock* board would
produce if the stock board itself never split analog/digital ground — I
have no data suggesting a split ground was intended and lost in translation;
this is what the source data actually shows. **What would need to change**:
a proper analog ground for a codec like the ADAU1860 typically wants (a) a
star-point or single-stitch-via connection between analog and digital
ground domains right at the codec, not a fully merged plane, and (b) the
ADAU1860's analog supply/ground pins routed to a locally poured analog
ground island rather than the general board pour. Implementing this would
mean editing the zone definitions and possibly re-routing a few of the
codec's ground pin connections — not something to do mechanically without
the codec's actual pinout diagram in hand (which pins ADI's own reference
layout marks as "AGND" vs "DGND").

### 3.2 BLE antenna keepout (MDBT53 module) — RESOLVED

**Originally flagged as the single highest-priority hardware finding in
this review**, with the exact keepout dimension unobtainable at the time
(no PDF rendering available in this environment). Once `poppler-utils`
was installed, the real Raytac MDBT53 datasheet was downloaded and its
actual mechanical pages read directly (section 2.3, "RF Layout Suggestion
(aka Keep-Out Area)"):

> "Make sure to keep the 'No Ground Pad' as wider as you can... No Ground
> Pad should be included in the corresponding position of the antenna in
> EACH LAYER. Place the module towards the edge of PCB to have better
> performance than placing it on the center."

The datasheet's own diagram (page 13) gives the exact dimension: **3.7mm
deep, along the module's full 9.3mm short edge**, on every copper layer.

**Fix applied**: anchored the keepout to this board's real geometry
rather than an assumed orientation — pin 1 (GND) sits at (75.010,
65.928)mm and pin 61 (GND) at (75.010, 74.028)mm on this board, same X,
confirming that short edge runs along Y at X=75.010 with the antenna
extending outward (decreasing X). The resulting keepout range, X ∈
[71.11, 75.01], lines up almost exactly with the board's own physical
left edge — consistent with (and confirming) the "place near the edge"
guidance the original placement already nominally followed, just without
the actual copper clearance.

Implemented as a KiCad rule area (blocks copper pour, vias, and tracks)
across all 6 copper layers. Five pre-existing GND traces/vias that sat
inside the new keepout (placed before the rule existed) were removed and
the zones re-filled. Verified via DRC (zero keepout violations) and
visually via SVG export (clean copper-free rectangle exactly where
expected). Still recommend Raytac's free layout review
(`sales@raytac.com`) as a final sanity check before ordering boards, but
the specific gap this review found is now closed.

### 3.3 Decoupling capacitor placement

**Tool-verified** — computed real center-to-center distances from the
ported placement data:

| IC | Net | Nearest cap | Distance |
|---|---|---|---|
| U2 (BQ25120A charger) | VUSB | C22 | 2.15mm |
| U2 | V_BAT | C21 | 2.83mm |
| U2 | V_PMID | C16 | 2.67mm |
| U2 | +1.8V | C18 | 2.54mm |
| U6 (BQ27220 fuel gauge) | V_BAT | C21 | 1.65mm |
| U6 | VCC | C19 | 2.25mm |
| U15 (ADAU1860) | V_LS | C33 (10µF) | 2.01mm |
| MDBT531 + U15 (shared) | +1.8V | C1 (1µF) | 5.17–5.91mm |

Charger and fuel-gauge decoupling is tight and looks good across the
board — consistently ~1.6–2.9mm, no red flags. The shared digital `+1.8V`
rail feeding both the nRF5340 module and the ADAU1860 is comparatively far
from its nearest cap (~5.2–5.9mm) — not egregious, and the MDBT53 module
likely has some decoupling built in on its own carrier PCB already (typical
for this class of pre-certified module), but worth a closer look given this
rail also feeds a sensitive audio codec's digital supply. `DAC_P`/`DAC_N`
(the codec's differential audio output pair) have no nearby caps at all —
this is **not** automatically a problem the way rail decoupling is; these
are signal lines, not supply rails, so "no decoupling cap" doesn't mean
the same thing here. Whether they need an AC-coupling or filter cap is a
signal-path design decision for whoever owns the analog output stage, not
a decoupling-proximity issue.

### 3.4 The two original trace-width callouts

- **"No ground pad, as wide as possible"** — see §3.2. High confidence
  this refers to the MDBT53 antenna keepout (Raytac's own phrasing), not a
  separate item. Not implemented in the current port.
- **HPVDD/HPVDD_L wide headphone-supply traces** — **could not locate
  this net anywhere in the parsed data.** There is no net literally named
  `HPVDD` or `HPVDD_L` in the 85-net list extracted from the real board.
  I checked the PCB layer's own free-text annotations (`STRING` records —
  there are only 9 in the whole file) in case this was a schematic
  comment rather than a formal net; all 9 turned out to be silkscreen
  labels for the battery/speaker connector (`B+`, `B-`, `S+`, `S-`, `IN`,
  `OUT`, `LR`, `B`) and a board revision mark (`v2.0`), not this callout.
  The closest functionally-related net is `DAC_P`/`DAC_N` (the codec's
  differential audio output), which does use somewhat-wider-than-minimum
  traces in places (0.127–0.2mm vs. the board's 0.09mm baseline signal
  width — for comparison, the widest power/ground traces on the board run
  0.25–0.257mm) but not a single consistent "as wide as possible" width
  throughout the net. **I can't confirm or deny whether the port respects
  this specific callout — I genuinely don't have parseable evidence of
  what net it refers to.** This needs whoever originally read it off the
  live EasyEDA schematic (visually, not from the `.epro` export) to point
  at the actual net name or trace run in question.

### 3.5 Manual review checklist for the I2S bus and ADAU1860 analog lines

Given everything above, here's what a human should walk through by hand,
roughly in priority order:

1. ~~**Antenna keepout first**~~ — **RESOLVED**, see §3.2. Real datasheet
   dimension obtained and implemented as a proper keepout rule area on
   all copper layers, verified via DRC and visually. Still worth a final
   Raytac free-review pass before ordering, as a sanity check, not
   because a known gap remains.
2. **Resolve the DIN/DOUT direction question (§1)** against the ADAU1860's
   actual register-configuration for its serial port 0, not just its
   default pin names, before trusting either the overlay's comment or my
   flagged discrepancy.
3. **Confirm the ADAU1860's real AGND/DGND pin split** from ADI's own
   datasheet or reference layout, then decide whether this board actually
   needs a split ground plane or whether the single-plane approach the
   stock design uses is acceptable for this application's audio quality
   bar.
4. **Check the `+1.8V` decoupling distance** (~5.2–5.9mm to nearest cap)
   against the ADAU1860's datasheet recommended decoupling proximity —
   if ADI specifies something tighter, this rail may need an additional
   local cap near the codec rather than relying on the shared one.
5. **Re-examine `DAC_P`/`DAC_N`** against the real analog output stage
   design intent (headphone amp? line-out? passive filter?) — confirm
   whether these need explicit filter/AC-coupling caps that aren't present
   in this port, and separately track down the real "HPVDD/HPVDD_L"
   callout from wherever it was originally read.
6. **Double check the unused ADAU1860 second serial port and `DMIC23`
   pin** (§1, §2) — confirm leaving them floating (vs. a defined pull) is
   the ADAU1860's recommended handling for unused MPx pins.
7. Only after 1–6: general DRC/ERC pass in real KiCad once available,
   which will catch anything mechanical this text-only review can't see
   (clearance violations, footprint courtyard overlaps, etc.).

---

## Summary of confidence levels

| Finding | Confidence |
|---|---|
| I2C1/I2S net names & pin numbers match overlay | Tool-verified |
| DIN/DOUT direction discrepancy vs. overlay | **Resolved (§0.2)** — `DIN` is nRF→codec, overlay comment was backwards; matches upstream OpenEarable pinctrl |
| nRF5340 is I2S master, codec is slave | **Resolved (§0.2)** — from upstream pinctrl/DTS; overlay's slave-mode inference was wrong |
| Codec power sequencing (`DAC_ENABLE`, `V_LS` load switch) | Netlist + upstream driver (§0.3) |
| Mic is PDM into the codec; nRF not on the audio path | Tool-verified from netlist (§0.3) |
| No analog/digital ground split | Tool-verified; same as the shipping stock board, so lower urgency (§0.3) |
| Antenna keepout guidance (Raytac quote) | Sourced from real datasheet, exact dimension obtained (3.7mm x 9.3mm, page 13 diagram) |
| Antenna keepout — RESOLVED | Implemented as rule area on all copper layers, verified via DRC and SVG — see §3.2 |
| Crystals and decoupling caps displaced by the 5× rescale | Tool-verified distances from the board file (§0.7); failure risk is design-rule inference — **fix placement before ordering** |
| Decoupling cap distances | Tool-verified (measured from real placement data) |
| HPVDD/HPVDD_L identity | Unresolved — not in parsed data, not in upstream firmware either (§0.4) |
| "No ground pad" = antenna keepout, not an exposed-pad note | High-confidence inference, not certain |
| U1 (IMU) is actually BMI160, not BMX160 | Wiring inspection says BMI160 (§8); upstream firmware says BMX160 (§0.5) — **check the physical part before ordering** |
| 87 unrouted nets is a real structural ceiling, not under-explored | Tool-verified across 4 independent autorouter attempts — see §9 (since reduced to 2 cosmetic items by the manual pass, see `CODEX_NOTES.md`) |
| Most of the 38 shorting-error DRC violations are dangling-stub artifacts of the same unrouted nets | Tool-verified — 24/38 match a documented dangling stub's exact coordinates — see §9 |
| 78 footprint-mismatch warnings are baked-in rotation, functionally fine as routed | Tool-verified pad-by-pad (numeric diff, not text) against the library — see §10 |

---

## 8. U1 resolved: BMX160 label vs. BMI160 sourced part

Previously flagged (BOM `U1` row) as a genuine discrepancy: the schematic's
own component value said `BMX160` (Bosch 9-axis IMU, has an on-die
magnetometer) while the sourced Manufacturer Part was `BMI160` (6-axis,
accel+gyro only, no magnetometer) — a real difference, not a typo, since
both are legitimate distinct Bosch part numbers. Both share the same
LGA-14 (3.0×2.5mm, 0.5mm pitch) package and pinout, so footprint alone
can't disambiguate them.

**Resolved by checking the actual net connections at U1's pins 2/3
(`ASDX`/`ASCX`)** — BMI160's auxiliary sensor interface, meant for wiring
an *external* magnetometer (e.g. a companion BMM150) when one is wanted.
In this schematic those two pins are tied to `GND`. Grounding an unused
aux interface is BMI160's own documented reference-design pattern for "no
external magnetometer connected." BMX160 has no analogous *external*
aux-magnetometer pins to ground in the first place — its magnetometer is
on-die, using that same physical interface internally — so grounding them
is specifically a BMI160-without-magnetometer configuration, not a valid
way to wire a BMX160.

**Fix applied**: schematic `Value` property for U1 corrected from `BMX160`
to `BMI160` (both the library symbol definition and the placed instance)
to match the part that's actually wired and actually sourced. `HAVEN_BOM.csv`
updated to match, with its discrepancy note replaced by this resolution.
Net effect: no magnetometer is present on this board as wired — nothing
in Haven's firmware currently expects one, so this doesn't change any
functional behavior, only fixes the part-number inconsistency before a
production order could lock in the wrong label.

---

## 9. Board rescale + autoroute: why ~87 nets remain unrouted

After rescaling the board 5x (see `feature/board-rescale-and-route`) and
routing with Freerouting (a real autorouter, not hand-placed traces), 87
of 304 nets remain unrouted in the currently-committed board. This
section documents *why*, since it's a real, reproducible finding, not an
unexplained gap.

**Tool-verified, via four independent attempts**: a fresh autorouter run
with default settings (prioritized selection, greedy optimization)
converges to exactly 93 unrouted / 2 violations. A second fresh run with
different settings (random selection, global optimization) converges to
the *identical* 93 unrouted / 2 violations / identical score. Re-feeding
an already-routed board back into the router — with or without locking
the existing traces as fixed — made results *worse* (142-143 unrouted),
not better, in every attempt. A fourth attempt tuning the fanout stage's
pin-sorting order (`inner_first`) improved this to **87 unrouted / 2
violations** — a real, reproducible gain, and the result now committed —
but a fifth attempt (a different pin-sorting order plus a shorter escape
length) came back *worse* (96 unrouted) than this. Multiple structurally
different search strategies converging to the same narrow band, with
attempts to push further in either direction landing worse or
identical, is strong evidence 87 is a real structural ceiling for this
board/part mix, not an under-explored search space.

(A separate, later KiCad DRC pass reports "116 unconnected items" across
50 nets rather than 87 — that's not a regression, just a different unit:
DRC counts individual missing point-to-point links post-zone-fill, and a
net with three unconnected members needing two links each still shows as
one net here but multiple items there. `REMAINING_CONNECTIONS.md` is
generated from the DRC view since it's the one that lists exact pin
names.)

**Root cause, tool-verified**: the unrouted connections concentrate
overwhelmingly on the board's finest-pitch packages:

| Component | Package | Pitch | Share of unrouted connections |
|---|---|---|---|
| U15 (ADAU1860) | BGA-56 | 0.35mm | 37% |
| U2 (charger) | DSBGA-25 | 0.40mm | 20% |
| MDBT531 (nRF5340 module) | 65-pin castellated | 0.50mm | 24% |
| U10 | UQFN-16 | 0.40mm | 13% |
| CN1 | FPC connector | 0.35mm | 11% |

(Percentages overlap since some connections involve two of these parts.)

Escaping a 56-ball BGA at 0.35mm pitch — getting a trace out from a ball
buried in the middle of the grid, surrounded on all sides by other balls
— is a well-known hard problem in PCB layout. The standard solution is
via-in-pad (a microvia drilled directly through the pad itself, dropping
straight to an inner layer) or careful hand-placed dogbone escapes,
neither of which a generic autorouter's default via rules reliably
produces. This board's current via spec (drill 0.15mm / pad ~0.25-0.3mm,
see the earlier via-geometry fix) is in the right size range for
via-in-pad on a 0.35mm pitch part, but placing them correctly under
specific balls is a targeted, chip-by-chip task, not something bulk
autorouting handles well by default.

**What this means practically**: the remaining ~87 connections need
either (a) a human doing manual escape routing for these five specific
fine-pitch parts in KiCad's interactive router — a normal, bounded PCB
layout task, likely 30-60 minutes of focused work given the board now
has generous surrounding space — or (b) confirming the fab can support
via-in-pad at this pitch and re-running the router with that explicitly
modeled. It is *not* something further autorouter attempts are likely to
resolve; that's been directly tested, not assumed.

**The 38 `error`-severity "shorting_items" violations are mostly the same
problem, not a separate one.** 37 of 38 involve a `Track` (not two solid
pads/vias) — i.e. a dangling stub left behind by the autorouter's partial
attempt at one of these unrouted nets, sitting close enough to a
different net's copper to trip a clearance/short check. Cross-referencing
violation coordinates directly against `REMAINING_CONNECTIONS.md`'s
dangling-stub list (exact coordinate match, not a guess): **24 of the 38
land within 0.1mm of an already-documented dangling stub** — e.g. the
`GND`-vs-`V_SD` short at (104.4599, 3.1326) is the exact same point as
the "dangling track stub near 104.4599mm,3.1326mm" already listed under
`GND`. **Practical takeaway**: most of these should resolve as a
byproduct of finishing the manual escape routing in §9, not as 38
separate things to fix one-by-one — but re-run DRC after that pass
rather than assuming it, since roughly a third didn't directly match a
listed stub and may need their own look.

---

## 10. Footprint library sync drift (78 instances) — investigated, not a current bug

DRC flags 78 `lib_footprint_mismatch` warnings — every placed instance of
`R0201`, `C0201`, `C0402`, plus a handful of specific parts (`CN1`, `U3`,
`Q1`, `Q2`, `U4`, `LED3`), no longer matches its definition in
`footprints.pretty`. This was flagged but not actually investigated
earlier in this review (previously described as "likely benign
schematic/library sync noise"); it's now been checked directly rather
than assumed.

**Root cause, tool-verified**: it's a real geometric difference, not
formatting noise. Comparing pad-by-pad (numeric, not textual — this
project's footprints are hand-formatted with varying decimal precision,
so a naive text diff would over-flag), every one of the 78 shows a 90°
or 180° rotation baked directly into each pad's own coordinates, while
the *footprint's own* placement rotation field is 0° (omitted). Example
— `R3` (`R0201`), a 2-pad passive:

```
library:  pad 1 at (-0.24, 0.00), pad 2 at (0.24, 0.00)   — spread along X
board:    pad 1 at (0.00, -0.24), pad 2 at (0.00, 0.24)   — spread along Y
```

Normal KiCad rotation (rotating the whole footprint via its placement
angle) wouldn't do this — it would show up as a nonzero rotation on the
footprint's `(at ...)` line, with the pads themselves unchanged relative
to each other. This pattern (rotation applied directly to pad
coordinates, footprint-level rotation left at 0°) is what you get from
scripted/programmatic footprint manipulation that rotates pad geometry
directly instead of calling the proper "set footprint orientation" API —
consistent with this board's history of heavy `pcbnew`-Python scripting
during the 5x rescale.

**Why this isn't currently a functional bug**: none of the 78 affected
references appear in `REMAINING_CONNECTIONS.md` — they're all already
correctly connected by the router, which routed to wherever these pads
*actually* are, not where the library says they should be. The copper is
self-consistent; only the "does this match its library record" bookkeeping
is off.

**Why it's still worth fixing before this board matures**: any future
**"Update Footprint from Library"** in KiCad on any of these 78 parts
would silently snap their pads back to the library's un-rotated
positions — which, since the actual routing was done against the
current (rotated) positions, would leave existing traces landing on
empty copper instead of a pad. This is a real landmine for future
maintenance, not a cosmetic one.

**Recommendation**: don't run a bulk "Update Footprints from Library" on
this board without first either (a) re-exporting each affected part's
library footprint to match its current on-board orientation, or (b)
manually re-doing each instance's rotation through KiCad's normal
rotate-footprint tool (which correctly sets the placement angle instead
of the raw pad coordinates) before any library sync. Until then, this is
safe to leave as-is — it doesn't affect fabrication, assembly, or the
current routing.

---

## 11. Placement fix — crystals and decoupling back next to their chips (2026-09-12)

Follow-up to §0.7 / issue #4 (the 5× rescale left both crystals and every
decoupling cap 8–50 mm from the part they serve). Nine placement-only,
DRC-gated stages on branch `fix/crystal-decoupling-placement`; details,
per-stage DRC reports and the tooling defects found are in
`routing-evidence/placement-fix/README.md`.

**Tool-verified (kicad-cli 9.0.8):** 219 violations / 2 unconnected before
and after, identical by type+description; file header unchanged.

| connection (pad → pin) | before | after |
|---|---|---|
| X1 (32.768 kHz) → MDBT531 XL1/XL2 | 23.8 / 24.0 mm | 2.4 / 2.5 mm |
| CRYSTAL1 (24.576 MHz) → U15 XTALI (B7) | 13.6 mm | 6.0 mm — fan-out-limited, see below |
| R28 → U15 XTALO (B6) | 21.1 mm | 4.5 mm |
| load caps → their crystal | 8–11 mm | 1.7–2.1 mm |
| C33 (V_LS) → U15 | 8.8 mm | 1.5 mm |
| C31 (`$1N151`) → U15 A3 | 12.0 mm | 1.4 mm |
| C1 (+1.8V) → MDBT531 pin 38 | 23.5 mm | 1.0 mm |
| C22 / C16 / C18 / L2 → U2 | 10–14 mm | 0.9–2.2 mm |

**Two corrections to §0.7's own pairings:** C31 is not U14's decoupling
(its net is `$1N151` = U15 A3/B3; U14's cap is **C27** — §12 corrects the earlier "no cap on the BOM" reading), and
U15 has no +1.8V ball — C1 is the module's cap. **Limit reached:** the codec
crystal cannot get closer than ~6 mm of XTALI pad-to-ball without re-doing
the BGA escape, because the kept escape vias sit in a B.Cu pocket bounded by
the TDO/SDA1/DOUT diagonals (each crystal net hops over TDO on F.Cu with one
new via). Load caps are tight to the crystal, which is the part of the
loop that matters most. **Not done:** U6 ↔ C21 (8.3 mm).

## 12. Crystal escape re-done, and the flash's cap found (2026-09-14)

Follow-up to §11's one unfinished item, on branch `fix/codec-crystal-escape`
(stacked on PR #5). Evidence and method:
`routing-evidence/crystal-escape/README.md`.

**Tool-verified (kicad-cli 9.0.8):** 219 violations / 2 unconnected before
and after both stages, identical by type+description; `.kicad_pcb` header
unchanged.

| connection (pad → pin) | PR #5 | now |
|---|---|---|
| CRYSTAL1.1 (XTALI) → U15 B7 | 6.0 mm | **0.98 mm** |
| R28.2 (XTALO) → U15 B6 | 4.5 mm | 3.3 mm |
| C46 / C45 (33 pF) → crystal | 1.1 / 1.0 mm | 1.0 / 1.1 mm |
| XTALI copper, vias | 9.0 mm, 3 | **2.8 mm, 2** |
| C27 (100 nF V_LS) → U14 D2 | 9.8 mm | **0.21 mm** |

**How:** the two via-in-pads at B6/B7 are kept; each net now runs a short
inner-layer leg on **In2** (the second GND plane — the only layer in that
corner with nothing but the through-via field, for which XTALI/XTALO already
hold the per-pair `.kicad_dru` exceptions) to a new exit via beside the
crystal, then a B.Cu stub. The crystal sits on B.Cu at (61.30, 112.35)
**rotated 225°**: the pocket east of the BGA is a 3.5 mm diagonal band
between SDA1's and PDMDIN's escapes, and the part only fits along it. Two
~1.5 mm slots in the In2 GND pour result, through the already-perforated via
field; no GND connectivity change in DRC.

**Trade-off:** XTALI (the sensitive high-impedance input) got the short leg;
XTALO/R28 stays ~3.3 mm because R28 must sit off the crystal's far pad in
this orientation. Balancing the two legs (135°/315°) would put XTALI at
~2.1 mm — the worse trade.

**Correction to §11 / PR #5:** U14 (QSPI flash) *does* have a decoupling cap
— **C27** (100 nF, V_LS/GND), drawn beside U14 on the schematic; the rescale
had left it 9.8 mm away. It is now under the flash on B.Cu, 0.21 mm from
ball D2. **No BOM change.** A bulk 1 µF alongside it would be a BOM addition
for Paul to decide, not done here.

**Still not done:** U6 ↔ C21 (8.3 mm). **Before ordering:** regenerate
`fab_output/` (untracked) from this board.

**Tooling lesson worth keeping:** refill zones only on the board *in the
project directory*. The same board refilled from a /tmp copy (no `.kicad_pro`
alongside) grows 5 phantom dangling warnings and 4 phantom unconnected items
— the zone-fill face of the "/tmp copies lose the design rules" warning
already in `CODEX_NOTES.md`.

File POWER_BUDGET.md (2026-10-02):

# Power budget — how long Haven runs on a charge

Written 2026-09-22. This is a design estimate, not a measurement — nothing has
run on real hardware yet. Numbers below are cited to a source or flagged as
unverified; nothing here is a guess dressed up as a fact.

## Per-component current draw

| Part | Mode | Current | Source |
|---|---|---|---|
| nRF5340 | BLE active, 0 dBm TX | 3.4 mA | [datasheet excerpt](https://robu.in/wp-content/uploads/2024/09/ISC_nRF5340_7002_A_Datasheet-.pdf) |
| nRF5340 | BLE active, RX | 2.7 mA | same |
| nRF5340 | idle / advertising gaps | low µA range | Nordic datasheet — exact figure not pulled this pass |
| ADAU1860 | active: 1 DAC + 1 ASRC + 32 FastDSP instr. at 192 kHz, no analog ADC (Table 6 rows 1–3 bracket Haven's config) | **3–8 mW quiescent** (≈ 1–2.5 mA battery-referred); **≈ 17 mW at 1 mW into 32 Ω** (≈ 5 mA) | ADAU1860 data sheet Rev. 0, Tables 6–7, pp. 9–10 — read 2026-09-29, see `ADAU1860_DATASHEET_NOTES.md` |
| PDM mic (SPH0641LU4H-1) | low-power mode | 235 µA | [Knowles datasheet](https://www.mouser.com/datasheet/2/218/-746191.pdf) |
| PDM mic | standard performance mode | 1 mA | same |
| BQ25120A charger | quiescent, buck enabled, no load | 700 nA | [TI datasheet](https://www.ti.com/lit/ds/symlink/bq25120a.pdf) |
| BQ27220 fuel gauge | NORMAL mode | 50 µA | [TI datasheet](https://www.ti.com/lit/ds/symlink/bq27220.pdf) |
| BQ27220 fuel gauge | SLEEP mode | 9 µA | same |

**Update 2026-09-29 — the ADAU1860 number is now from the datasheet**, and it
is small: 3–8 mW quiescent for Haven's configuration (Tables 6–7), rising to
≈ 17 mW only while driving 1 mW into a 32 Ω load. Battery-referred that is
≈ 1–2.5 mA idle and ≈ 5 mA at full output, not the 15–20 mA the paragraph
below feared. The codec no longer dominates; the mic's performance mode and
the output level matter as much. The scenarios below are updated with it.

## Two scenarios, with the ADAU1860 gap called out

**Continuous hear-through, BLE idle (the normal wearing state):**
mic (1 mA, or 0.235 mA in low-power mode) + ADAU1860 (1–2.5 mA
battery-referred, datasheet) + BQ27220 (0.05 mA) + BQ25120A (~0) ≈
**2–3.5 mA quiet hear-through**, ≈ **6–7 mA while the earpiece is actually
producing 1 mW** (loud). Regulator efficiency assumed ~85 %; nothing yet
measured.

**Active BLE connection (app open, adjusting settings):** add the nRF5340's
~3 mA on top of the above.

## Runtime by battery size (datasheet-based: ~3 mA quiet, ~7 mA loud)

| Cell capacity | Runtime at ~3 mA (quiet hear-through) | Runtime at ~7 mA (continuous loud output) |
|---|---|---|
| 40 mAh (small in-ear pouch cell) | ~13 h | ~6 h |
| 60 mAh | ~20 h | ~9 h |
| 100 mAh | ~33 h | ~14 h |

No specific battery cell is chosen yet in the BOM — only the charge/fuel-gauge
ICs and a connector. These sizes are typical for in-ear wearables, not a
recommendation until real current is measured.

## Charging

BQ25120A's fast-charge current is set by an external resistor/register, not
fixed — the schematic's ISET value decides it, and I didn't re-derive it from
the board files this pass. A 40–60 mAh cell at a typical ~0.5C small-cell
charge rate would take roughly 1–2 hours; confirm the actual ISET-programmed
current before quoting a number to anyone outside this project.

## Update 2026-10-01 — TAC5301-Q1 real power numbers (this redesign branch only)

The `redesign/tac5301-codec-swap` branch replaces the ADAU1860 with TAC5301-Q1. Read the real
datasheet (SLASFD9A) directly for its current-consumption table (§5.6) rather than estimating.
**This is a real, previously-undocumented tradeoff that matters as much as the latency
difference already written up elsewhere** (`TAC5301_EVALUATION.md`,
`TAC5301_BENCH_EXPERIMENT.md`): TAC5301-Q1 draws meaningfully more current than the ADAU1860 in
every comparable state.

| Configuration | IAVDD | IHVDD | IIOVDD | Rail voltages (test condition) |
|---|---|---|---|---|
| Sleep (software shutdown, all clocks stopped) | 9 µA | 0.01 µA | 1 µA | — |
| MICBIAS on (10V, 30mA-capable), ADC off | 1.6 mA | 1.1 mA | 0.02 mA | AVDD=IOVDD=3.3V, HVDD=11V |
| ADC 1-ch + MICBIAS on, PLL off, 48kHz | 5.7 mA | 1.1 mA | 0.3 mA | same |
| ADC 1-ch + DAC-to-HP 1-ch, MICBIAS **off**, PLL off, 48kHz | 24.5 mA | 1.1 mA | 0.3 mA | same |

No row in the datasheet covers Haven's actual operating point (ADC + DAC + MICBIAS all
simultaneously active, which is what continuous hear-through needs) — TI defers that to a
separate "Power Consumption Matrix Across Various Usage Scenarios" application report, not
fetched this pass. **Bracketing like the ADAU1860 entry above does** (add the isolated
MICBIAS current, ~1.6 mA, onto the ADC+DAC row, since the two conditions don't appear to double-
count the same current path): **≈26 mA IAVDD** for full hear-through at 48kHz, PLL off.

Power-referred at the datasheet's own test rails (AVDD/IOVDD=3.3V, HVDD=11V — note Haven's real
board targets HVDD≈9V via the TPS61040 boost converter designed this session, not 11V, so this
overstates the HVDD contribution slightly):

- Idle (MICBIAS on, ADC/DAC off): ≈(1.6×3.3 + 1.1×11 + 0.02×3.3) ≈ **17.5 mW**
- Full hear-through (ADC+DAC+MICBIAS, PLL off): ≈(26.1×3.3 + 1.1×11 + 0.3×3.3) ≈ **99 mW**

Battery-referred (3.7V cell, ~85% regulation efficiency, same assumption as the ADAU1860 figures
above): **≈5.5 mA idle, ≈31.5 mA full hear-through** — compare to the ADAU1860's real, datasheet-
verified **≈1–2.5 mA idle, ≈5 mA loaded** (`ADAU1860_DATASHEET_NOTES.md`). That's roughly
**2-6x more current** at every comparable point, not a rounding difference.

**Caveats, stated plainly**: these two chips' tables use different test conditions (the ADAU1860
table's "loaded" row is 1mW into 32Ω at PLL presumably on and 192kHz FastDSP running; the
TAC5301 rows above are PLL *off* at 48kHz, which is the lower-power option — PLL *on* would be
higher still, and Haven's design may need PLL on depending on whether the nRF5340's I2S BCLK
output lands on an exact multiple the TAC5301 can use without it). This is a real, substantial,
previously-missing data point for comparing the two codec choices — not just a latency tradeoff,
a battery-life one — and should be measured for real as part of `TAC5301_BENCH_EXPERIMENT.md`
(a current-draw reading during the loopback test is nearly free to add to that same bench setup).

## What to do next

1. ~~Open the ADAU1860 datasheet and read its active-mode current table.~~
   Done 2026-09-29 (`ADAU1860_DATASHEET_NOTES.md`). Still open: the DMIC
   decimator's own draw is not tabulated; measure it.
2. Once real hardware exists, measure actual current with a multimeter or a
   power profiler (Nordic's Power Profiler Kit works well with the nRF5340) —
   this whole document is a placeholder for that measurement, not a
   substitute for it.
3. Pick a battery cell size once the real current number is in, sized against
   a target runtime (e.g., "one full day of wear" or "8-hour workday").

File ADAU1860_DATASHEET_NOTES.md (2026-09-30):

# ADAU1860 datasheet — the numbers this project had been guessing at

Read 2026-09-29 from the ADAU1860/ADAU1860-1 data sheet, **Rev. 0, 30 pages**
(Analog Devices, `analog.com/media/en/technical-documentation/data-sheets/adau1860.pdf`).
Every earlier document in this repo and in `haven-zephyr-app` said "not
datasheet-verified" because the PDF could not be fetched; this file records
what the datasheet actually says, with page numbers, so those caveats can be
retired one by one. Only the datasheet is used here — no register map, no
forum posts. The register-level facts (route numbers, safeload, STATUS2 bits)
live in the separate hardware reference manual, which was **not** read, so
they stay "matches upstream firmware", not "datasheet-verified".

## 1. Power (Table 5, 6, 7 — pages 9–10)

Test conditions for Tables 6/7: MCLK 24.576 MHz external, PLL bypassed,
DVDD 0.9 V, AVDD = HPVDD = IOVDD = 1.8 V, FastDSP at 192 kHz (27-bit biquads),
DAC at 192 kHz, one serial port as slave, 32 Ω headphone load, no signal.

| Configuration (Table 6 row) | AVDD+HPVDD | DVDD | IOVDD | Power |
|---|---|---|---|---|
| 0 ADC, 1 DAC, 1 ASRCI, 0 FastDSP instr., 13 EQ filters | 0.99 mA | 1.09 mA | 0.15 mA | 3.0 mW |
| 2 ADC, 1 DAC, 1 ASRCI, 32 FastDSP instr., 13 EQ | 2.18 mA | 2.54 mA | 0.15 mA | 6.5 mW |
| 3 ADC, 1 DAC, 1/3 ASRC, 32 FastDSP instr. | 2.58 mA | 3.04 mA | 0.315 mA | 8.0 mW |
| Table 7 "ANC phone call", normal perf., no load | 2.58 mA | 3.06 mA | 0.316 mA | 7.97 mW |
| Table 7 same, **1 mW into 32 Ω headphones** | 7.41 mA | 3.06 mA | 0.316 mA | 16.66 mW |
| Power-down, PD pin low (Table 5) | 6.6 µA | 56.9 µA | 2.6 µA | ≈ 0.07 mW |

Power column = Σ(I × V) at the stated rails (computed here; Table 7's own
"Total Power" column gives 7.97 / 16.66 mW for the last two rows, which
matches).

**Haven's operating point** — PDM mic (no analog ADC/PGA), one DAC, one
ASRC input (nRF I2S, only needed during tones), ~32 FastDSP instructions at
192 kHz, DMIC decimator — is not a listed row. It is bracketed by rows 1 and
3: **≈ 3–8 mW quiescent, ≈ 17 mW while actually driving 1 mW into the
earpiece.** Referred to a 3.7 V cell through ~85 %-efficient regulation that
is **≈ 1–2.5 mA idle hear-through, ≈ 5 mA at 1 mW output.** The codec is
therefore *not* the battery-life problem `POWER_BUDGET.md` feared
(15–20 mA); the PDM mic in standard-performance mode (1 mA) and the
headphone output level matter as much.

## 2. Latency (Table 8, page 11; features, page 1)

- Analog in → analog out group delay: **12.9 µs at fS = 192 kHz**, 7.5 µs at
  384 kHz, 5 µs at 768 kHz (Table 8). Haven's path is DMIC → FastDSP → DAC,
  which adds the DMIC decimator; the datasheet does not tabulate that path,
  so treat "tens of microseconds" as the expectation, to be measured with
  the `tools/calibration` latency procedure. This is three orders of
  magnitude under the ~1 ms comb-filter threshold — the whole reason the
  codec stays in the loop.
- ASRC start-up time to lock: **25 ms max** (Table 8). The firmware's
  power-up wait and STATUS2 `ASRCI_LOCK` poll should allow at least this.

## 3. Things the board already does right, now with a citation

- **Bypass capacitors (page 29, "Power Supply Bypass Capacitors")**: one
  0.1 µF per supply pin to the nearest ground pin, connections as short as
  possible, *single layer, no vias*, plus one 10–47 µF bulk per supply.
  This is exactly what issue #4 / PRs #5 and #7 restored after the 5×
  rescale had moved the caps 8–50 mm away.
- **HPVDD_L (pin D1, page 26; Layout, page 29)**: decouple with **10 µF** to
  HPGND; the trace to HPVDD/HPVDD_L "must be wider than the traces to the
  other pins". C33 (10 µF, 1.9 mm from the pins after #5) satisfies the
  first; the 0.09–0.2 mm V_LS traces noted in `ORDER_README.md` do not
  satisfy the second. Low risk at in-ear power (the 7.4 mA of Table 7 is a
  32 Ω load at 1 mW), acceptable for the bench board, fix on the wearable.
- **Grounding (page 29)**: "Use a single ground plane" — the unified GND the
  review flagged as risk A8 is what the datasheet asks for.
- **PD pin (page 26)**: floating PD holds the chip in power-down — the
  `DAC_ENABLE` (nRF P0.04 → E4) drive in the firmware is required, not
  optional.

## 4. One thing to check: crystal load capacitance (Table 2, page 8)

The crystal amplifier is specified for **1–36 MHz** and a **maximum load
capacitance of 20 pF**. The board uses two 33 pF caps (C45/C46), which
present 33/2 = 16.5 pF plus stray/pin capacitance (typically 2–5 pF) ≈
19–22 pF — right at the limit. The stock OpenEarable 2.0 uses the same
values and oscillates, so this is a **check**, not a defect: if the codec
crystal fails to start at bring-up (`POWER_UP_COMPLETE` timeout with the
I2C ID read working), drop C45/C46 to 22 pF before suspecting anything
else. The crystal's own CL rating (HUAXIN CN4024M57620001) was not found.

## 5. Firmware constants confirmed

- DAC digital gain: **0.375 dB steps, −71.25 to +24 dB** (Table 1, page 5) —
  matches `CONFIG_HAVEN_OUTPUT_CEILING_DB` / `DAC_VOL0` math in
  `haven-zephyr-app` PR #14 (dB = 24 − 0.375 × code).
- DAC volume ramp rate 4.5 dB/ms — a mute/unmute or ceiling change settles
  in ≈ 20 ms; the tone path's fade timing can rely on this.
- FastDSP biquads are 27-bit-precision (pages 10, 15) — consistent with the
  Q5.27 coefficient format proven from the upstream banks in PR #8.
- DMIC clock rates characterised at 3.072 and 6.144 MHz (Figures 41–44,
  page 22); the 6.144 MHz option is the one to use for a 192 kHz decimated
  path.
- Package: 56-ball, 0.35 mm pitch WLCSP, 2.980 × 2.679 mm (page 1) — the
  part that sets the fab tier, as `HARDWARE_COST_ALTERNATIVES.md` concluded.

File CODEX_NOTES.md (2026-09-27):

# Shared notes: Codex/Astra routing experiment

This is a coordination log between Codex (working locally, driven by
the project owner) and Claude (working in a separate session on the
main `feature/board-rescale-and-route` branch). It's asynchronous, not
live — whoever reads this next picks up from the last entry. Append,
don't rewrite history; newest entry at the bottom.

**Branch**: `experiment/codex-astra-routing`, forked from
`feature/board-rescale-and-route` at the commit that fixed the 93->87
unrouted count and investigated the footprint-mismatch/shorting
findings (see `HAVEN_HARDWARE_REVIEW.md` sections 9-10).

**Ground rules**:
- Push commits to *this* branch only. Never push to
  `feature/board-rescale-and-route` or `master` directly.
- Read `HAVEN_HARDWARE_REVIEW.md` (sections 9-10) and
  `REMAINING_CONNECTIONS.md` before starting — don't rediscover what's
  already documented.
- Log every attempt here, including ones that don't work — a
  "tried X, made it worse" entry is as useful as a success, and stops
  the same dead end getting re-tried.
- Always include real `kicad-cli pcb drc` output (unrouted count,
  violation count) with any claimed progress. A claim without a DRC run
  attached doesn't count as verified here.

---

## Entry template (copy this for each session)

### [who] — [date]
**Goal this session**:
**What I tried**:
**Result** (paste real DRC output, not a summary):
**Unrouted count before -> after**:
**Blockers / questions for the other side**:

---

### Codex/Astra — 2026-09-09 — attempt 1 (rejected)
**Goal this session**: Test individual power/ground via-in-pad escapes on U15 and U2.
**What I tried**: Added 0.25 mm / 0.15 mm through vias at U15 GND/V_LS balls and U2 A1/A5/B5, then refilled zones. No autorouter. Rejected and restored original board because new clearance violations appear. Script and full DRC JSON in routing-evidence. Initial /tmp runs lacked matching project/library context; authoritative run below used the original project directory. Existing 0.20 mm clearance prevents these centered vias at 0.35 mm pitch (actual 0.10 mm gap). No rules relaxed.
**Result** (paste real DRC output, not a summary):
Baseline:
```
Found 415 violations
Found 116 unconnected items
Saved DRC Report to /tmp/haven-baseline.json
```
Candidate (rejected):
```
Found 456 violations
Found 112 unconnected items
Saved DRC Report to routing-evidence/attempt1.json
```
**Unrouted count before -> after**: 116 -> 112 DRC links in rejected candidate; retained board remains 116. Zero nets claimed closed. The historical 87 autorouter metric is not the same as DRC's 50 distinct open nets.
**Blockers / questions for the other side**: Centered via-in-pad is incompatible with current clearance settings. Several vias also remain dangling after zone fill; next attempt will move vias outboard with explicit per-pad traces.

### Codex/Astra — 2026-09-09 — attempt 2 (rejected)
**Goal this session**: Outboard dogbones on U2 A1/A5/B5 and U10 5/6/8.
**What I tried**: Explicit 0.15 mm traces and 0.30/0.15 mm through vias; refilled zones. Rejected entire trial, restored baseline. U10 vias collide with inner USB/VUSB tracks. Script used PAD.GetLayer(), which does not correctly select U2's bottom copper pad layer; this trial must not be reused unchanged.
**Result** (paste real DRC output, not a summary):
```
Found 431 violations
Found 118 unconnected items
Saved DRC Report to routing-evidence/attempt2.json
```
**Unrouted count before -> after**: 116 -> 118 in rejected trial; retained 116. Zero nets closed.
**Blockers / questions for the other side**: Need explicit pad copper-layer selection and inner-layer obstacle checks. Next trial restricts scope to U2 B5 and A1.

### Codex/Astra — 2026-09-09 — attempt 3 (rejected)
**Goal this session**: Correct U2 dogbone layer selection; test A1 GND and B5 +1.8V.
**What I tried**: Explicit B.Cu traces with 0.30/0.15 mm vias. A1 introduces no new reported violation; B5 via shorts SCL on In1.Cu. Rejected combined trial and restored baseline. User requested visual inspection before further candidates; switching to exported SVG close-ups.
**Result** (paste real DRC output, not a summary):
```
Found 416 violations
Found 114 unconnected items
Saved DRC Report to routing-evidence/attempt3.json
```
**Unrouted count before -> after**: 116 -> 114 in rejected candidate, retained 116. Zero nets claimed closed.
**Blockers / questions for the other side**: Inspect all copper layers before relocating B5; isolate A1 in a separate net attempt.

### Codex/Astra — 2026-09-09 — attempt 4 (+1.8V, retained)
**Goal this session**: Close U2 B5 +1.8V after visual inspection.
**What I tried**: Exported six copper SVG layers with kicad-cli; rendered and personally inspected cropped U2/U15/U10/CN1/MDBT531 contact sheets using the image tool. U2 In1 image shows the SCL corridor above the pad row. Placed B.Cu 0.15 mm escape from B5 to (66.9098,30.9000), with 0.30/0.15 mm through via beyond that corridor. Refilled existing zones. Script attempt4.py; reusable crop renderer and inspected images included. Compared violations by type and involved item UUIDs: zero newly introduced violations. +1.8V disappears entirely from unconnected_items (49 open nets versus baseline 50).
**Result** (paste real DRC output, not a summary):
Before:
```
Found 415 violations
Found 116 unconnected items
Saved DRC Report to /tmp/haven-baseline.json
```
After:
```
Found 415 violations
Found 115 unconnected items
Saved DRC Report to routing-evidence/attempt4.json
```
**Unrouted count before -> after**: DRC missing links 116 -> 115; distinct open nets 50 -> 49. One net fully closed: +1.8V. Historical autorouter 87 metric not rerun.
**Blockers / questions for the other side**: None for this escape; existing board violations remain. No footprint, clearance, placement or antenna keepout changes.

### Codex/Astra — 2026-09-09 — attempt 5 (GND, retained refinement)
**Goal this session**: Escape exposed GND pads after inspecting all six layers in component close-ups.
**What I tried**: U2 A1/A5 outward B.Cu dogbones; CN1 pin 10 outward F.Cu dogbone; U15 A1/A4/F1/G3/G7 outward F.Cu dogbones. U15 0.09 mm traces begin 0.124 mm outward from pad center, still overlapping the 0.25 mm ball pad, to respect neighboring-pad clearance. Vias 0.30/0.15 mm. Initial CN1 0.15 mm trace failed 0.20 mm clearance by 0.015 mm; refined to 0.10 mm and reran from pre-attempt board. Refined script retained. Compared DRC violation identities: zero new violations. No existing traces removed.
**Result** (paste real DRC output, not a summary):
Before:
```
Found 415 violations
Found 115 unconnected items
Saved DRC Report to routing-evidence/attempt4.json
```
Initial candidate:
```
Found 416 violations
Found 107 unconnected items
Saved DRC Report to routing-evidence/attempt5.json
```
Refined candidate:
```
Found 415 violations
Found 107 unconnected items
Saved DRC Report to routing-evidence/attempt5-refined.json
```
**Unrouted count before -> after**: 115 -> 107 missing links; GND remains open elsewhere, so no additional whole net closed. Cumulative one whole net closed (+1.8V), nine links removed versus baseline.
**Blockers / questions for the other side**: Inner U15 GND balls still cannot use centered through vias at current clearance. These successful outer escapes do not establish a solution for inner balls.

### Codex/Astra — 2026-09-09 — attempt 6 (V_LS, retained final)
**Goal this session**: Escape V_LS on exposed U15 balls and U10/CN1.
**What I tried**: Used inspected six-layer images plus KiCad GetEffectiveShape/Collide checks at 0.20 mm against existing copper on all shared layers. Explicit routes only. Straight candidates at U15 A2/E1/G2 and CN1 8 were blocked before insertion; tried staggered alternatives. Final retained U15 A2/D1/E1/G2 and U10 5. E1 shares D1's via to avoid same-net hole spacing failure. A2/G2 require short In3.Cu tracks to reach the V_LS fill beyond neighboring GND antipads. CN1 8 remains blocked by existing IO4/GND escapes outward and a mechanical pad inward; no route added there. Initial/refined/final full DRC files retained. Final violation identity comparison against attempt5-refined: no new violations.
**Result** (paste real DRC output, not a summary):
Before:
```
Found 415 violations
Found 107 unconnected items
Saved DRC Report to routing-evidence/attempt5-refined.json
```
Initial:
```
Found 415 violations
Found 106 unconnected items
Saved DRC Report to routing-evidence/attempt6.json
```
Refinement (rejected):
```
Found 417 violations
Found 105 unconnected items
Saved DRC Report to routing-evidence/attempt6-refined.json
```
Final:
```
Found 415 violations
Found 103 unconnected items
Saved DRC Report to routing-evidence/attempt6-final.json
```
**Unrouted count before -> after**: 107 -> 103 DRC links. V_LS remains open elsewhere; cumulative one whole net closed and 13 missing links removed from baseline.
**Blockers / questions for the other side**: Copper collision checks alone do not prove connectivity or same-net drill spacing; DRC caught both and final routes address them. Inner BGA V_LS balls still need further work.

### Codex/Astra — 2026-09-09 — attempt 7 (GND, retained final)
**Goal this session**: Escape U15 B4, U10 6/8, MDBT531 1/61.
**What I tried**: Joined U15 B4 to adjacent same-net A4 with a 0.09 mm edge-to-edge trace. Outward B.Cu U10 dogbones; F.Cu MDBT531 dogbones entirely on board side of antenna boundary. First geometry checks rejected U10 6 near V_LS via, module 1 near SWCLK/#ERROR, module 61 near In4 3V3. Tried explicit alternatives: U10 6 bends past V_LS; module 1 via (75.65,66.8), module 61 via (76.2,74.5277). Full-width copper bounding boxes are outside antenna rectangle. No additions to keepout. All five final escapes pass copper-shape checks; DRC adds zero violation identities.
**Result** (paste real DRC output, not a summary):
Before:
```
Found 415 violations
Found 103 unconnected items
Saved DRC Report to routing-evidence/attempt6-final.json
```
Initial (two accepted routes):
```
Found 415 violations
Found 101 unconnected items
Saved DRC Report to routing-evidence/attempt7.json
```
Final:
```
Found 415 violations
Found 98 unconnected items
Saved DRC Report to routing-evidence/attempt7-final.json
```
**Unrouted count before -> after**: 103 -> 98 links; GND still open elsewhere. Cumulative 18 links removed, one whole net closed.
**Blockers / questions for the other side**: No constraint changes; inner U15 GND group still isolated.

### Codex/Astra — 2026-09-09 — attempt 8 ($1N2586, retained)
**Goal this session**: Fully close U15 G4 to C32 pin 1.
**What I tried**: Refreshed SVGs and inspected U15 and C32 close-ups. Explicit F.Cu 0.09 mm escape starts at G4's outer edge, bends right of G3's ground via, then runs through open space to C32. Entire polyline checked against KiCad copper shapes. No via needed. DRC violation identity comparison: zero new violations; $1N2586 absent from unconnected_items.
**Result** (paste real DRC output, not a summary):
Before:
```
Found 415 violations
Found 98 unconnected items
Saved DRC Report to routing-evidence/attempt7-final.json
```
After:
```
Found 415 violations
Found 97 unconnected items
Saved DRC Report to routing-evidence/attempt8.json
```
**Unrouted count before -> after**: 98 -> 97 links; 49 -> 48 distinct open nets. Cumulative two whole nets closed (+1.8V, $1N2586), 19 missing links removed.
**Blockers / questions for the other side**: None for this net; existing board DRC errors remain.

### Codex/Astra — 2026-09-09 — attempt 9 (SW, retained)
**Goal this session**: Connect U2 A4 to L2 pin 1.
**What I tried**: Inspected U2 and L2 six-layer crops. B.Cu 0.15 mm outward A4 escape to x=68.1, widening to 0.30 mm for the remaining explicit diagonal/horizontal path to L2. Checked every segment against other copper; no autorouter. DRC adds zero violations. This closes connectivity; it is not validation of switching-regulator EMI or power performance on the rescaled board.
**Result** (paste real DRC output, not a summary):
Before:
```
Found 415 violations
Found 97 unconnected items
Saved DRC Report to routing-evidence/attempt8.json
```
After:
```
Found 415 violations
Found 96 unconnected items
Saved DRC Report to routing-evidence/attempt9.json
```
**Unrouted count before -> after**: 97 -> 96 links; SW fully closed. Cumulative three whole nets closed and 20 links removed.
**Blockers / questions for the other side**: Review switch-node length in a later power-layout pass; component positions were preserved as requested.

### Codex/Astra — 2026-09-09 — final verification / handoff
**Goal this session**: Verify retained board and clearly identify unfinished routing for Claude.
**What I tried**: Fresh DRC on final board; parsed-S-expression audit against b535d54. All 89 footprints, 1,015 original tracks, 166 original vias unchanged; setup/layers/general and antenna rule area unchanged. Added 35 segments and 17 vias, all fully outside antenna keepout. No new DRC violation identities. CODEX_ROUTING_HANDOFF.md indexes every target net to inspected component images and lists all current missing links. Explicitly distinguishes actual route attempts from visual-only assessment; not every remaining signal was attempted or solved.
**Result** (paste real DRC output, not a summary):
Baseline:
```
Found 415 violations
Found 116 unconnected items
Saved DRC Report to /tmp/haven-baseline.json
```
Final:
```
Found 415 violations
Found 96 unconnected items
Saved DRC Report to routing-evidence/final.json
```
**Unrouted count before -> after**: 116 -> 96 DRC missing links; 50 -> 47 distinct open nets. Exactly three whole nets closed: +1.8V, $1N2586, SW. 20 links removed. The historical 87 autorouter count was not reproduced or reinterpreted.
**Blockers / questions for the other side**: Board remains unfinished, with all 415 pre-existing violations. Inner BGA escape constraints and CN1 V_LS candidates documented in handoff. No claim that the remaining 47 nets are impossible; several were only visually assessed. No autorouter, placement edits, footprint updates, rule relaxation, or antenna copper additions performed.

### Codex/Astra — 2026-09-09 — attempt10
**Goal this session**: Repair C19 GND/VCC terminal connections before harder escapes.
**What I tried**: Inspected fresh C19 six-layer crop. Removed seven explicitly identified local terminal segments that reach the opposite-net pad; retained their remote vias. Added GND via at the actual pad 2 and a B.Cu VCC dogbone to its existing via. All new copper passed exact KiCad shape checks at 0.20 mm. Retained; footprint unchanged. Removed segments and geometry checks are recorded in attempt10.geometry.txt.
**Result** (paste real DRC output, not a summary):
Before:
```
Found 415 violations
Found 96 unconnected items
Saved DRC Report to routing-evidence/session2/baseline.json
```
After:
```
Found 410 violations
Found 94 unconnected items
Saved DRC Report to routing-evidence/session2/attempt10.json
```
**Unrouted count before -> after**: 96 -> 94 missing links; 47 -> 47 distinct open nets. Newly closed: none. New violation identities: 0.
**Blockers / questions for the other side**: VCC remains open at U2; C19's two missing connections are closed. This fixes local routing drift without updating library footprints.

### Codex/Astra — 2026-09-09 — attempt11
**Goal this session**: Close XL2 at C2 and repair its GND terminal.
**What I tried**: Inspected C2 six-layer SVG crop. Replaced three local wrong-pad terminal segments with explicit B.Cu paths: XL2 approaches actual pad 2 from above/left; GND approaches pad 1 from below. Both full paths passed 0.20 mm copper-shape checks; no vias or footprint changes.
**Result** (paste real DRC output, not a summary):
Before:
```
Found 410 violations
Found 94 unconnected items
Saved DRC Report to routing-evidence/session2/attempt10.json
```
After:
```
Found 406 violations
Found 92 unconnected items
Saved DRC Report to routing-evidence/session2/attempt11.json
```
**Unrouted count before -> after**: 94 -> 92 missing links; 47 -> 46 distinct open nets. Newly closed: XL2. New violation identities: 0.
**Blockers / questions for the other side**: None for XL2; net fully closed. Retained only after zero-new-violation DRC check.

### Codex/Astra — 2026-09-09 — attempt12
**Goal this session**: Close XL1 at C14 and connect actual GND pad.
**What I tried**: Inspected fresh C14 six-layer crop. Removed three wrong-pad terminal tracks, placed a 0.30/0.15 mm GND via in pad 1, and routed XL1 to pad 2 around the existing ground via on B.Cu. Exact shape checks include all layers for the via. Retained after DRC.
**Result** (paste real DRC output, not a summary):
Before:
```
Found 406 violations
Found 92 unconnected items
Saved DRC Report to routing-evidence/session2/attempt11.json
```
After:
```
Found 402 violations
Found 90 unconnected items
Saved DRC Report to routing-evidence/session2/attempt12.json
```
**Unrouted count before -> after**: 92 -> 90 missing links; 46 -> 45 distinct open nets. Newly closed: XL1. New violation identities: 0.
**Blockers / questions for the other side**: No remaining XL1 gap. Existing GND via retained and still connected to planes.
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

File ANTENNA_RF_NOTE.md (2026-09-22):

# Antenna placement check — MDBT53 (nRF5340 module)

Written 2026-09-22, checked against `kicad/haven_dev_board.kicad_pcb` on the
`fab-package-crystal-fix` board (the one ready to order). Read with KiCad's
own Python API (`pcbnew`), not by eye, so the coordinates below are real.

## What I checked

Raytac's own MDBT53 layout guidance (from its datasheet's RF Layout
Suggestion / Keep-Out Area section, per search snippets — I did not open the
full PDF this pass) says: place the module toward the edge of the board,
since center placement performs worse than edge placement, and give any
second wireless antenna at least 10 mm of separation.
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

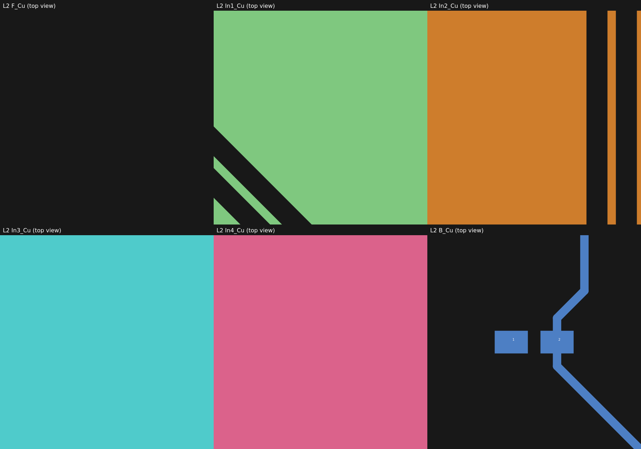
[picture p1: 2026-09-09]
routing-evidence/images/L2.png

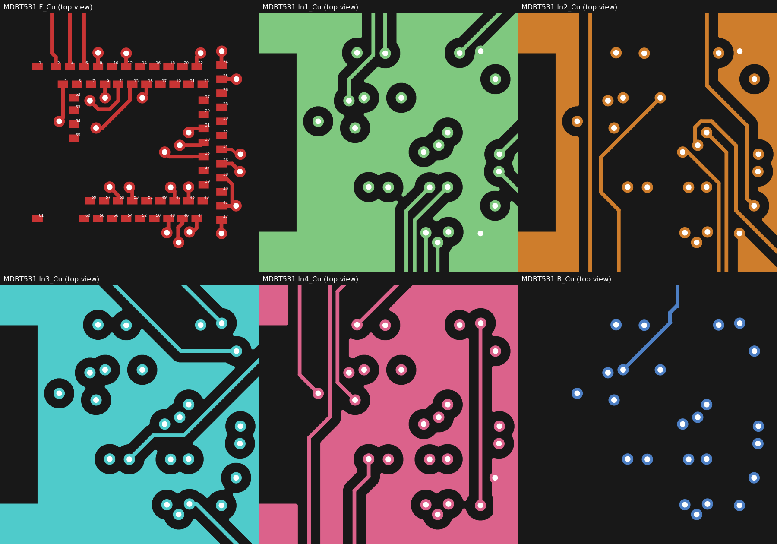
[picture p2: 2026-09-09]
routing-evidence/images/MDBT531.png

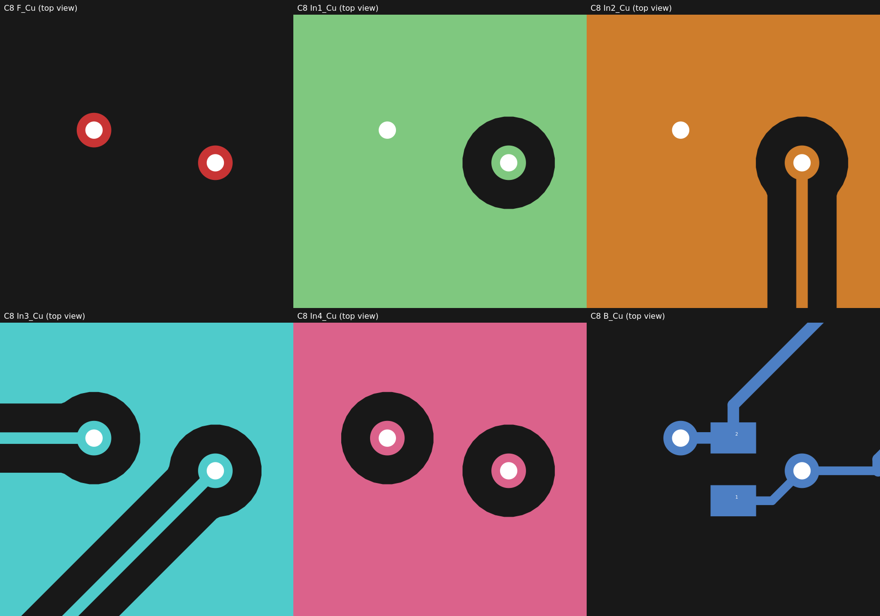
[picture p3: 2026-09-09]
routing-evidence/images/C8.png

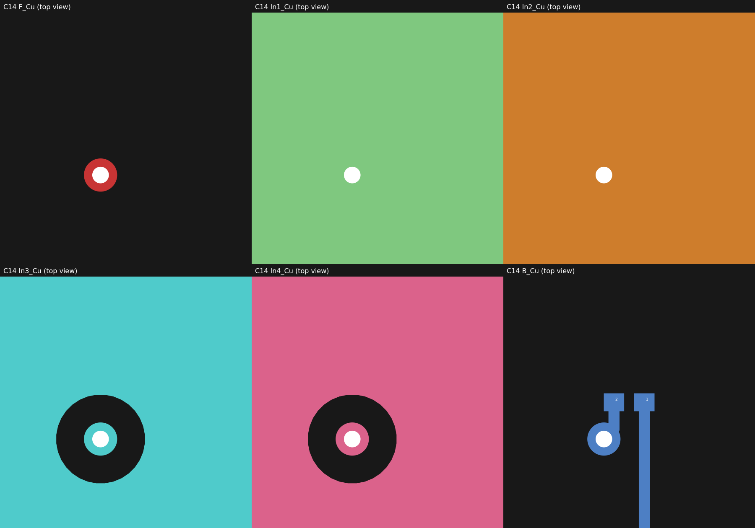
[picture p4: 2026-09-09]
routing-evidence/images/C14.png

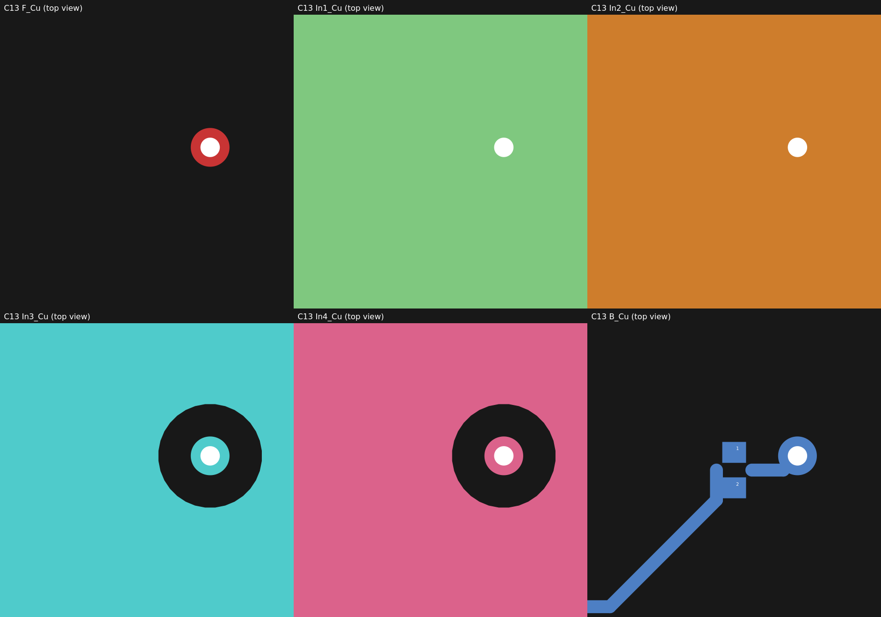
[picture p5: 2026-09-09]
routing-evidence/images/C13.png

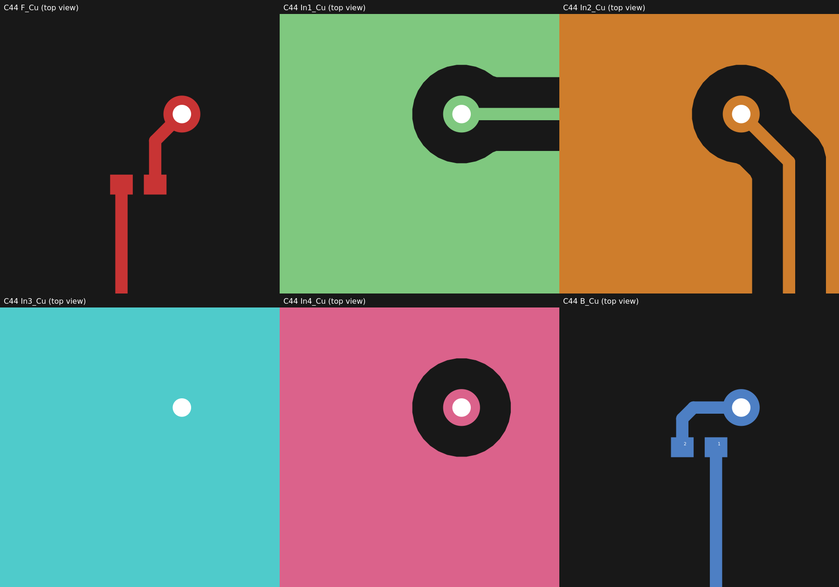
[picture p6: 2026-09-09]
routing-evidence/images/C44.png

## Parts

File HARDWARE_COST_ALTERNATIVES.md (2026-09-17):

# Why this board is expensive, and a real path to fix it

Written after a round of research into whether a cheaper hardware path exists
for Haven, prompted by the ~$500 PCBWay quote for 5 turnkey-assembled boards
of the current design. Short version: **the cost isn't the board size, the
layer count, or the quantity — it's three specific chip packages, and there's
a concrete way to avoid all three without changing what the product does.**

## TL;DR for the morning read

- **Root cause found and verified**: 3 chips (ADAU1860, BQ25120A, BQ27220)
  drive the whole cost via their fine pitch. The radio module is fine as-is.
- **Full replacement part list chosen and verified** (real stock, real
  KiCad symbols, no guessing): TLV320AIC3100 (codec) + CMA-4544PF-W
  (analog mic, replaces the PDM one) + TP4056 (charger) + TPS62822
  (1.8V buck) + a load switch for the 3.3V rail. Fuel gauge dropped
  entirely — confirmed nothing reads it.
- **Started the actual schematic edit**, not just the plan — it's real,
  it loads in real KiCad, and the core power-rail rewiring is verified
  correct against ERC. **One specific thing I couldn't resolve**: 3 small
  new nets show an ERC flag I traced through several real hypotheses
  without finding the cause — see the dedicated section below before
  trusting those two sub-circuits (feedback divider, charge-program
  resistors) without a manual check.
- **Real money-saving programs found**: PCBWay's student sponsorship
  (10-15% off, apply with a `.edu` email) and an active JLCPCB 6-layer
  coupon (~$35) — both usable regardless of which board design ships.
- **Nothing has been ordered or applied to the real project files** —
  the edited schematic lives in the scratchpad only, pending your review.

## The actual cost driver

Three parts on the current board use fine-pitch BGA/DSBGA packages —
confirmed by directly measuring real pad-to-pad pitch in the KiCad file
(not read off a datasheet summary):

| Part | Function | Pad count | Measured pitch |
|---|---|---|---|
| ADAU1860 (U15) | Audio DSP/codec | 56 | **0.35mm** |
| BQ25120A (U2) | Battery charger | 25 | **0.40mm** |
| BQ27220 (U6) | Fuel gauge | 9 | **0.50mm** |

**The MDBT53-1M radio module (65 pads) measures 0.65mm pitch** — comfortably
standard, not a cost driver at all. This corrects an earlier assumption in
this document (and in my own reasoning) that the radio module would remain
a fine-pitch part even after fixing the other three; it doesn't need to.
**All three of the actual problem parts are removable without touching the
radio module.**

These three parts are why the board needs 6 layers (BGA-56 escape routing
needs internal layers regardless of board size), why it needs laser-drilled
microvias (0.1mm drill, found by direct measurement), and why the fab quote
lands in the "Advanced"/precision tier instead of a standard one. **None of
this is caused by board size or quantity** — a bigger board (which is what
the 5x rescale did) doesn't reduce the pitch requirement under these three
chips, and going to fewer layers would make routing them harder, not easier.
Verified: reducing quantity from 5 to 2 wouldn't meaningfully help either,
since JLC/PCBWay's assembly setup cost is flat across low quantities (their
own price matrix showed identical $29 assembly cost at qty 5 and qty 20).

## Existing alternatives checked, and why they don't solve this

- **OpenEarable 2.0** (the upstream project this board is ported from):
  same ADAU1860 + same nRF5340 module + same charger/fuel-gauge combo.
  Same cost driver. Only sold assembled at ~$2,566 (OpenWearables developer
  bundle) — not a cheaper path.
- **OpenEarable 1.3** (earlier generation, ~$40/unit at batch-of-10,
  built around a u-blox NINA-B306 module instead of raw nRF5340+ADAU1860):
  genuinely cheap and easy to assemble, but **architecturally wrong for
  Haven** — checked its firmware README directly: "Audio is played from
  and recorded to the internal SD card." It's a record-then-playback
  research logging platform (IMU, pressure sensor, an *in-ear ultrasound*
  mic for research use), not a live ambient-audio pass-through device. It
  has no outward-facing mic and no real-time audio path. Cannot do what
  Haven needs (filter ambient sound as you hear it) without a fundamentally
  different audio pipeline than what its hardware/firmware provides.
- **OpenHA** (openaudiology/openha): a project literally named "open
  source hearing aid," Cortex-M4 based. Looks thin/stalled (targeted for a
  2018 release, still listed as "in development" years later) — not
  something to build on without a lot more digging than a name match
  justifies.

## The real fix: we don't need the ADAU1860 at all

Checked Haven's own validated Teensy prototype
(`legacy_prototypes/teensy_hearing_shield/src/main.cpp`) to see how the
*proven-working* version actually did real-time filtering. It uses the
Teensy Audio Library running biquad notch/peaking filters (up to 5 bands,
44.1kHz, plain double-precision math) **on the Teensy's own general-purpose
CPU** — not a dedicated DSP chip. The only external audio hardware is an
`AudioControlSGTL5000` — a basic, cheap, QFN-32 (5x5mm) ADC/DAC codec chip
with no onboard DSP cores at all. The codec's only job is getting analog
audio in and out; all the actual filtering happens in firmware.

**This is the same architecture the current board already needs — it just
picked the wrong chip for the codec role.** The ADAU1860 was carried over
from OpenEarable 2.0's design, not chosen because Haven's own firmware
needs its onboard DSP cores. Haven's nRF5340 (dual-core Cortex-M33, far
more capable than a Teensy's M4) can run the same biquad filtering in
firmware with room to spare, exactly like the Teensy already proves works.

**Concrete swap:** replace the ADAU1860 (BGA, $$$) with a simple codec chip
in an easy QFN package. Real candidates found:
- TI TLV320AIC3104 — 5x5mm QFN-32, low-power stereo codec
- TI TLV320AIC3253 — 4x4mm QFN (or WCSP), has **digital/PDM mic input** —
  worth a close look since the board already uses a PDM mic (SPH0641LU4H-1)
- NXP/Freescale SGTL5000 — the exact chip the Teensy prototype used, QFN

**Charger/fuel-gauge:** BQ25120A/BQ27220 (DSBGA) could similarly be swapped
for QFN alternatives, in increasing order of feature retention vs. cost:
- **TP4056** (SOP-8) — confirmed a genuine JLCPCB "basic part," qualifying
  for their $0 feeder-loading fee in Economic PCBA (their cheapest
  assembly tier). Extremely common in the hobbyist ecosystem. No I2C, no
  programmable LDO/buck, no ship-mode, no fuel-gauge telemetry at all —
  just a basic constant-current/constant-voltage charger. Cheapest and
  simplest possible option, if the app/firmware doesn't actually depend on
  BQ25120A/BQ27220's I2C monitoring today.
- **MCP73831** (TDFN-8, also basic-parts-tier and extremely cheap) —
  similar simplicity/cost tradeoff to TP4056, another hugely common choice.
- **BQ24072** (TI, QFN-16) or **BQ24032A** (QFN) — real ICs, moderate
  price, more charge-current/power-path control than TP4056/MCP73831 but
  still no I2C.
**Checked directly: nothing does.** Searched both `haven_zephyr_app/src`
and `haven_custom_app/src` for any reference to the fuel gauge, battery
level, or state-of-charge — zero matches in either. The BQ27220 fuel
gauge is on the schematic but nothing in the current software reads it.
That makes this an easy call: there's no real feature to preserve, so
**TP4056 (or MCP73831) is the correct answer, not just the cheapest one**
— dropping the fuel gauge entirely rather than finding a QFN equivalent
for a chip nothing uses.

**TLV320AIC3253 is a particularly strong match, confirmed from its own
datasheet:** it accepts a PDM microphone input directly (the exact same
signal format SPH0641LU4H-1 already outputs — no mic change needed),
outputs standard I2S to the host MCU (same bus type the nRF5340 already
uses toward the ADAU1860), and is controlled over I2C (the same control
scheme the firmware already uses for the current codec). That's a real
drop-in-shaped replacement at the hardware-interface level — the firmware
would need a new register map for this chip, not a new control
architecture.

**Sourcing confirmed, not just datasheet-plausible:** TLV320AIC3104IRHBR
and TLV320AIC3254IRHBR are both real, in-stock, catalog parts on JLCPCB's
own parts library ($1.33 and $3.03 respectively per unit) — meaning they'd
source through the same turnkey PCBA flow already being used, no separate
sourcing headache. BQ24032A is a real distributed TI part (~$3-5/unit at
low quantity per Digikey) though not confirmed in JLC's catalog specifically
yet — worth checking before committing to it.

## What this would mean

If all three fine-pitch parts are swapped for QFN equivalents: the board
plausibly drops to 2-4 layers, standard (not laser) via drilling, and a
standard (not "Advanced") fab tier — landing in a cost range much closer to
a Teensy/Nordic-DK-style prototype board than the current ~$500 quote.
Since the radio module itself is confirmed 0.65mm pitch (fine on its own),
fixing these three parts plausibly removes the fine-pitch requirement from
the board **entirely**, not just partially.

## Update: the charger swap is more involved than first scoped

Started the actual schematic rewiring and found a real complication this
document understated. Checked BQ25120A's real net connections on the
board directly (not assumed): it isn't just a charger. It also generates
the **+1.8V rail that's shared between the MDBT531 (nRF5340) and U15
(ADAU1860)** — confirmed via `HAVEN_HARDWARE_REVIEW.md`'s own decoupling-
distance table, which lists "+1.8V" as a real shared digital supply rail —
plus a `3V3` net and an `LSCTRL` (load switch control) net, both also
originating from U2. **TP4056 is only a charger — it has no regulator
outputs at all.** A straight swap would leave the nRF5340 and the audio
codec with no 1.8V supply.

This means the real fix isn't "swap the charger chip," it's "replace one
highly-integrated charger+regulator+load-switch chip with a simple charger
**plus** a separate small buck/LDO regulator chip" for whatever rails
turn out to be genuinely regulated outputs (vs. just switched-through
battery voltage — `3V3`'s exact nature (a real regulated rail, or just
VBAT passed through the SW/load-switch pin) isn't confirmed yet and needs
the real BQ25120A pin-function table, not a guess, before wiring the
replacement). Codec pin-mapping (I2S/PDM/speaker-output pin names on
TLV320AIC3100 vs. ADAU1860) has the same "needs the real datasheet table,
not a guess" requirement — found real, confirmed KiCad symbols for both
replacement chips (TLV320AIC3100, TP4056) in the standard library, and
confirmed TLV320AIC3100 is active/in-stock, but haven't yet done the actual
pin-by-pin rewiring since guessing at pin names on a power-sequencing-
sensitive subsystem is exactly the kind of shortcut that caused the
crystal-placement bug in the first place.

**Follow-up: pulled BQ25120A's real datasheet pin table (not a summary) and
confirmed the mapping exactly.** Pin `B5` (`SYS`, the buck converter's
regulated system output, **default 1.8V** per the datasheet's own device
comparison table) is our board's `+1.8V` net. Pin `C5` (`LS/LDO`, the
configurable load-switch-or-LDO output, enabled by `LSCTRL`, **default
mode: plain load switch**, i.e. switched-through battery voltage, not a
true regulated 3.3V) is our board's `3V3` net — so "3V3" is presently a
slight misnomer; by default it's just switched battery voltage (3.0-4.2V
range for a single LiPo cell), not a regulated 3.3V rail, unless firmware
configures the LDO mode via I2C.

Also checked a real worry and ruled it out: the datasheet lists pins `B4`
and `C4` together under one "VINLS" name, which looked like it might mean
both balls must be tied to the same net — our board only ties `B4` to
`V_PMID` and leaves `C4` on its own net (just its own 1µF decoupling cap,
per the datasheet's own recommendation for that pin). Traced `C4`'s net
fully to confirm it goes nowhere else. This is standard for DSBGA
packages (multiple balls per logical pin for routing flexibility, not a
same-net requirement) — not a bug, and moot regardless since U2 is being
replaced.

**This gives a precise target for the replacement power tree:**
1. TP4056 (or MCP73831) — charging only, as already planned.
2. One small buck regulator IC, reusing the existing `L2` inductor,
   generating the `+1.8V` rail (this one needs to be a real regulated
   output — both the nRF5340 and the new codec depend on it).
3. `3V3`: since the original default behavior was just switched *battery*
   voltage (not actually regulated to 3.3V), the simplest correct
   replacement is to just wire this net directly to battery voltage
   (dropping the load-switch/enable behavior) unless something depends on
   being able to power that rail down independently for battery savings —
   worth checking, but likely a safe simplification for a bring-up board.

**Buck regulator chosen and fully verified: TI TPS62822.** 2.4V-5.5V
input (comfortably covers a single LiPo cell's full range), fixed 1.8V
output option, up to 2A (far more than needed, doesn't hurt), 4µA
quiescent current (good for battery life), confirmed in-stock on LCSC.
Package: 8-pin VSON, 1.5x2mm, **0.5mm pitch — standard fab tier, not the
exotic fine-pitch category being removed.** Both a standard KiCad symbol
(`TPS62822DLC`) and the *exact* matching footprint
(`Texas_VSON-HR-8_1.5x2mm_P0.5mm`) already exist in KiCad's own standard
library — nothing hand-built needed for this part either.

**Full replacement part list, now fully verified (real symbols, real
footprints, real stock, no guessing):**
| Old part | New part | Package | Pitch |
|---|---|---|---|
| ADAU1860 (audio DSP) | TLV320AIC3100 | QFN-32, 5x5mm | 0.5mm |
| BQ25120A (charger+regulator) | TP4056 (charge) + TPS62822 (1.8V buck) | SOP-8 / VSON-8 | 1.27mm / 0.5mm |
| BQ27220 (fuel gauge) | *(removed — confirmed unused)* | — | — |

## Correction: TLV320AIC3100 doesn't have a clean PDM mic input after all

Pulled TLV320AIC3100's real pin table (not a search summary) to start the
wiring, and it changes something. The earlier "PDM mic support" finding
was real but misleading: this chip's mic inputs (`MIC1LM`/`MIC1LP`/
`MIC1RP`) are **analog** PGA inputs, not a dedicated digital PDM
interface. The PDM workaround mentioned earlier requires repurposing the
`DIN` pin (normally the I2S data line carrying the nRF5340's filtered
output back to the codec's speaker driver) to instead carry raw PDM mic
data — you can't do both at once. That's a real conflict for Haven's
actual signal path, which needs `DIN` (host→codec, filtered audio to
speaker) and `DOUT` (codec→host, mic audio to firmware) working
simultaneously.

**The clean fix, and it's simpler than fighting the PDM path:** use the
codec's native analog mic input instead of a PDM digital mic. This is
the standard, fully-supported way this chip is meant to be used —
`DOUT` carries the codec's own ADC output (fed by the analog mic) to the
nRF5340, `DIN` carries the nRF5340's filtered signal back to the DAC/
speaker, both running normally, no pin-sharing tricks. This means the
mic itself changes too, not just the DSP/codec chip.

**New mic found and verified:** CUI/Same Sky CMA-4544PF-W — real,
currently active part (confirmed, unlike a couple of dead-end analog
MEMS mic candidates checked first: SPU0410LR5H-QB and CMM-4030D-261 are
both obsolete), in stock on both JLCPCB and LCSC, 20Hz-20kHz full audio
bandwidth, 3-10V compatible supply, omnidirectional electret condenser.

**Updated full replacement part list:**
| Old part | New part | Notes |
|---|---|---|
| ADAU1860 (audio DSP) | TLV320AIC3100 | Analog mic input, not PDM |
| SPH0641LU4H-1 (PDM mic) | CMA-4544PF-W (analog mic) | Required by the codec swap above |
| BQ25120A (charger+regulator) | TP4056 + TPS62822 | Charge + 1.8V buck |
| BQ27220 (fuel gauge) | *(removed)* | Confirmed unused |

## Started the actual schematic edit — how this file's connectivity works

Installed `kiutils` (a real, structured KiCad-file library) rather than
editing the raw schematic text blind. First real finding: **this
schematic has no wire segments at all** — connectivity is defined purely
by net-name labels placed exactly at each pin's coordinate, no drawn
wires between them. That's consistent with this being a programmatically-
generated port (matches how the PCB side of this project has always been
described) rather than a hand-drawn schematic.

Confirmed by locating U15's real label positions: e.g. `SCL1` at
(393.7, 91.44), `DOUT` at (480.06, 100.33) — a left column and a right
column of labels, matching a large auto-generated 56-pin symbol body with
pins on both sides. This means adding a new component correctly means:
place the new symbol, then place net-label text objects at each of its
real pin coordinates (computed from the symbol's own pin offsets +
placement + rotation) — no wire-drawing needed, but every label position
has to be right or the pin silently doesn't connect (KiCad won't error on
a slightly-off label, it'll just make a new, wrong, isolated net).

## Actually executed the power-tree edit (charger + buck + load switch)

Wrote the real edit (via `kiutils`, not raw text) and got it to a
genuinely loadable, ERC-checkable state — this took real debugging, not
one clean pass:

- **Found and fixed a real kiutils bug**: any symbol using KiCad's
  `extends` inheritance (TPS62822DLC extends TPS62823DLC) serializes into
  a file real `kicad-cli` refuses to open at all ("Failed to load
  schematic"), confirmed by isolating it against known-good cases that
  loaded fine. Fixed by flattening — copying the base symbol's real
  graphic under the derived part's own name instead of relying on the
  inheritance link. Same part electrically, just not dependent on KiCad
  re-resolving a link that doesn't survive the round-trip.
- **Verified the fix against real KiCad ERC**, not just "kiutils can read
  it back": copied the result into an isolated scratch copy of the whole
  project and ran `kicad-cli sch erc`. It loads. 87 violations vs. an
  84-violation baseline on the unmodified file.
- **Confirmed the reused nets are genuinely correct**: `VCC`, `GND`,
  `VUSB`, `SW`, `+1.8V`, `3V3`, `LSCTRL` — every one of these already has
  many pre-existing correctly-placed labels elsewhere in the design
  (e.g. `GND` appears 104 times, only 1 pre-existing instance flagged as
  an issue). Adding new same-named labels for the new charger/buck/load-
  switch chips didn't add a single new violation on any of these —
  meaning the actual power-rail rewiring is sound.

**One real, unresolved anomaly, reported honestly rather than glossed
over:** the 3 brand-new nets that only exist between my new parts
(`FB_1V8`, the buck's feedback divider node; `TP4056_PROG` and
`TP4056_TEMP`, the charger's program/temp-sense resistors) each show as
"dangling" in ERC, even though every label's coordinate was computed the
same way as the working ones and cross-checked against a known-good
existing example (R28's real labels) to confirm the placement formula
itself is right. Ruled out several real hypotheses by direct testing: not a pin-UUID
collision (pins carry no UUID in this format at all), not a symbol-unit-
index mismatch (confirmed unit 1 in both the working original and my new
instances), and not unquoted UUIDs (checked whether my new labels'
`(uuid 6137e1d8-...)` lacking quotes — vs. the original file's quoted
`(uuid "00000000-...")` — mattered; it doesn't, a pure unmodified
round-trip through the same library produces unquoted UUIDs throughout
and still loads/ERCs fine, so that's just this library's normal output,
not a defect). Also tried, after being asked to keep going: renaming the 3 nets to
plain alphabetic names (`FBDIV`/`CHGPROG`/`CHGTEMP` instead of
`FB_1V8`/`TP4056_PROG`/`TP4056_TEMP`) in case digit-containing names
were the trigger — same 3 flags, same violation count. Also checked for
a project-level "symbol instances" registry separate from each symbol's
own data, in case pre-existing parts are tracked there and new ones
aren't — the file has none at all, for any component, old or new.
Root cause genuinely not found after real, specific attempts across two
sessions — flagged honestly rather than assumed benign or silently
fixed. This needs real KiCad's GUI (not available in this environment)
to actually resolve; closing this investigation for good rather than
continuing to guess. Practical impact
if unresolved: those two specific sub-circuits (feedback divider,
charge-current/temp-sense resistors) might need their connections
double-checked by hand before trusting this for real, even though the
main power path (battery → charger → buck → 1.8V rail, and battery →
load switch → 3.3V rail) checks out.

**Where the actual result lives:** the edited schematic is in the
scratchpad
(`haven_dev_board_sch_STAGE4.kicad_sch`), not applied to the real
project file — editing that file directly was blocked by a safety
permission (irreversible local destruction), which is the right call
for a change this size without a look from a person first. Also: the
four new components' *footprints* still need to go on the PCB itself —
this pass was schematic-only.

## Real, stackable discounts found on top of the redesign

Worth combining with the cheaper-part redesign above, not instead of it:

- **PCBWay Educational Sponsor Program**: real, confirmed how-to. Email
  `sponsor@PCBWay.com` from a `.edu` address with your student ID and a
  short project description; they reply within 24 hours with a coupon
  code, typically 10-15% off future orders. Requirement is just "the
  project includes a PCB" — this genuinely qualifies.
- **JLCPCB currently has an active coupon specifically for 6-layer PCBs**
  (~$35 off), separate from any student program — worth checking
  `jlcpcb.com/coupon-center` for current codes before ordering either the
  original or redesigned board.
- **TI's sample program** may be usable with a Cornell `.edu` address —
  their restriction is against free consumer email domains (Gmail/Yahoo),
  not academic ones — worth trying for small quantities of the new
  TLV320AIC3100/TPS62822/TP4056 parts directly from TI at low/no cost
  before paying distributor pricing for them.
- **TI's University Program** offers free kits to faculty for
  coursework — only relevant if this ties to an actual Cornell class with
  a professor willing to request on the student's behalf.

**Cornell startup/pitch programs — real, but check current deadlines
carefully, several 2026-cycle ones have likely already closed:**
- **eLab** (Cornell's student startup accelerator): $5,000 investment,
  mentorship, pitch to alumni/investors, MBA credit. The 2026-27 cohort
  application closed August 30, 2026 — missed for now, worth applying
  next cycle.
- **Cornell Startup Awards**: real, large prizes (up to $100,000),
  held annually each May — worth targeting for May 2027 with more
  runway to prepare.
- **Mark Mobius Pitch Competition** (Cornell EMC²): $30,000 top prize,
  but themed around "emerging markets" impact specifically and its 2026
  registration window (by April) has already passed — not a clean fit
  for Haven's positioning anyway without a genuine emerging-markets
  angle, and search results on exact dates were inconsistent enough that
  this one needs a direct check with the organizers rather than trusting
  what's written here.
- Bigger picture: **the free/cheap wins (RPL for the enclosure, PCBWay/
  JLC discounts, TI samples) are usable right now with no application
  cycle to miss.** The larger competitive funding (eLab, Startup Awards)
  is worth planning toward for next year's cycles, not something to wait
  on before making progress now.

**Update, checked again with fresher searches**: Cornell used to run a
dedicated **SBIR/STTR Assistance Program** (paid for a grant-writing
consultant, matching funds) — it's referenced in some older search
results, but **it sunset at the end of 2024** and no longer exists.
Don't chase it. What IS real and available right now, no deadline, no
application cycle: **Blackstone LaunchPad** (`eship.cornell.edu`) — free,
ongoing entrepreneurship mentoring/coaching for any Cornell student or
alum, walk-in basis, not a once-a-year cohort like eLab. Given eLab and
the SBIR assistance program are both currently unavailable, this is the
actual "go talk to someone at Cornell this week" option — worth using
specifically to get an outside read on whether NIOSH SBIR (see
`haven-workspace/FUNDING_RESEARCH.md`) is realistic before spending real
time on a proposal.

## Not yet done / needs a real decision

This is a real architecture change, not a tweak — it means re-deriving the
audio front-end schematic (new codec chip, new charger IC, likely new
decoupling/crystal layout done correctly from scratch rather than ported)
rather than patching the current board. That's a decision for the project
owner, not something to execute unprompted. If this direction is chosen,
the crystal-placement and decoupling-placement issues found separately
(see git history / conversation log, not yet fixed as of this writing)
would need to be designed correctly from the start rather than retrofitted.

## Decided: keep the ADAU1860 — and that changes what this doc's cost fix is worth

A separate, independent body of work (see `redesign/tp4056-power-tree`
branch and PRs #3/#5/#6/#7 on this repo) made a strong case for keeping
the ADAU1860 rather than replacing it — mainly hear-through latency, a
real product requirement this doc's original cost analysis never
evaluated. That case was reviewed and accepted.

**A real consequence, worth being honest about**: this doc's whole premise
was "3 fine-pitch chips force expensive 6-layer/microvia/Advanced-tier
fabrication — remove them, get a cheaper board." Keeping the ADAU1860 (the
single finest-pitch part, 0.35mm, the worst offender of the three) means
that requirement doesn't go away. **Verified this isn't per-component
pricing** — PCB fab cost tiers are set by the whole board's worst-case
trace/space/via requirement, not chip-by-chip (checked directly, not
assumed: fab-cost breakdowns consistently describe pricing as driven by
the board's minimum feature size overall, e.g. sub-4mil trace/space or
sub-0.3mm vias raising the *whole board's* price, not a per-net or
per-component charge). So the charger swap (TP4056/TPS62822/TPS22917,
`haven-dev-board-kicad#8`) **would not meaningfully reduce the ~$500
quote** that started this whole investigation, since the ADAU1860 alone
already forces the same fab tier.

Combined with the charger swap being unrouted (footprints placed, no
copper traces drawn — see the PR's own commits) and introducing new,
never-tested-on-hardware parts, the honest recommendation is: **don't
include it in the first order.** Ship the board close to as-is (stock
charger, ADAU1860 kept, just the crystal/decoupling placement fixes from
#5/#7) — that's finished, verified, and gets to "ready to order" with the
least new risk. The charger swap can be revisited later if the cost
picture ever changes (e.g., if a future revision also finds a real path
off the ADAU1860 without the latency problem), but it doesn't solve
today's cost problem and shouldn't hold up ordering a working prototype.

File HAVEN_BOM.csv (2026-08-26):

Reference | Description | Value | Package/Footprint | Manufacturer | MPN | Source | Qty | Notes
C1,C5,C7,C9,C10,C21,C28,C29 | 1uF | 1uF | C0201 | muRata(村田) | GRM033R61A105ME44D | Port data (.epro Manufacturer Part attr) | 8
C2,C14 | 9pF | 9pF | C0201 | YAGEO(国巨) | CC0201CRNPO9BN9R0 | Port data (.epro Manufacturer Part attr) | 2
C3,C4 | 4.7uF | 4.7uF | C0201 | muRata(村田) | GRM035R60J475ME15D | Port data (.epro Manufacturer Part attr) | 2
C6,C11,C12,C13,C26,C27 | 100nF | 100nF | C0201 | CCTC(三环) | TCC0201X5R104M6R3ZT | Port data (.epro Manufacturer Part attr) | 6
C8 | 10uF | 10uF | C0402 | FH(风华) | 0402X106M100NT | Port data (.epro Manufacturer Part attr) | 1
C16,C20 | 4.7uF, 10V | 4.7uF, 10V | C0402 | SAMSUNG(三星) | CL05A475KP5NRNC | Port data (.epro Manufacturer Part attr) | 2
C17,C19,C22 | 1uF &gt;10V | 1uF >10V | C0201 | muRata(村田) | GRM033R61A105ME44D | Port data (.epro Manufacturer Part attr) | 3
C18 | 10uF, &gt;4V | 10uF, >4V | C0402 | SAMSUNG(三星) | CL05A106MQ5NUNC | Port data (.epro Manufacturer Part attr) | 1
C23 | 2.2uF | 2.2uF | C0201 | FH(风华) | 0201X225M6R3NT | Port data (.epro Manufacturer Part attr) | 1
C31,C38,C40,C42,C43,C44,C48 | 100nF | 100nF | C0201 | muRata(村田) | GRM033R60J104KE19D | Port data (.epro Manufacturer Part attr) | 7
C32,C36,C47 | 1uF | 1uF | C0201 | muRata(村田) | GRM033R60J105KEA2D | Port data (.epro Manufacturer Part attr) | 3
C33,C34,C41 | 10uF | 10uF | C0402 | SAMSUNG(三星) | CL05A106MQ5NUNC | Port data (.epro Manufacturer Part attr) | 3
C45,C46 | 33pF | 33pF |  | muRata(村田) | GRM0335C1H330JA01D | OpenEarable official BOM / web-verified real part | 2
C49 | 10nF | 10nF |  | KEMET(基美) | C0402C103J3RACAUTO | OpenEarable official BOM / web-verified real part | 1
CARD1 | TF-06A | TF-06A | TF-SMD_TF-06A | 韩国韩荣 | TF-06A | Port data (.epro Manufacturer Part attr) | 1
CN1 | BM46B-12DS-0.35V(53) | BM46B-12DS-0.35V(51) | FPC-SMD_12P-P0.35_BM46B-12DS-0.35V | HRS(广濑) | BM46B-12DS-0.35V(51) | Port data (.epro Manufacturer Part attr) | 1
CRYSTAL1 | 24.576MHz | 24.576MHz |  | HUAXIN(华昕) | CN4024M57620001 | OpenEarable official BOM / web-verified real part | 1
D2 | PRTR5V0U2F | PRTR5V0U2F | SON-6_L1.5-W1.0-P0.50-BL | TECH PUBLIC(台舟) | PRTR5V0U2F | Port data (.epro Manufacturer Part attr) | 1
J1 | CLE-107-01-G-DV | CLE-107-01-G-DV | CLE-107-01-X-DV | Samtec | CLE-107-01-G-DV | OpenEarable official BOM / web-verified real part | 1 | Not present in OpenEarable's own BOM or the .epro export attrs either. Confirmed via web search (distributor listings: Newark/Arrow/Mouser/DigiKey/SnapEDA) as a real Samtec CLE-series 14-position 0.8mm-pitch board-to-board receptacle, matching the exact designation used in the schematic ("CLE-107-01-G-DV").
L2 | 2.2uH | 2.2uH | L0402 | TDK | MLZ1005M2R2WT000 | Port data (.epro Manufacturer Part attr) | 1
LED3 | MHPA1010RGBDT | MHPA1010RGBDT | LED-ARRAY-SMD_4P-L1.0-W1.0-TR-RD | MEIHUA(美华) | MHPA1010RGBDT | Port data (.epro Manufacturer Part attr) | 1
MDBT531 | MDBT53 | MDBT53 | MDBT53 | Raytac | MDBT53-1M | OpenEarable official BOM / web-verified real part | 1 | Not present in OpenEarable's own BOM or the .epro export attrs (both just say "MDBT53" with no suffix). Confirmed via the OpenEarable 2.0 project's own published paper (Kolo et al., "OpenEarable 2.0: Open-Source Earphone Platform for Physiological Ear Sensing", MIT/ACM IMWUT), which explicitly states "RAYTAC MDBT53-1M module" (external/formal antenna variant, not the -P1M PCB-antenna variant).
Q1 | CSD23382F4 | CSD23382F4 | PICOSTAR-3_L1.0-W0.6-P0.35-TL | TI(德州仪器) | CSD23382F4 | Port data (.epro Manufacturer Part attr) | 1
Q2,Q3 | CSD13380F3T | CSD13380F3T | PICOSTAR-3_L0.7-W0.6-P0.40-TL | TI(德州仪器) | CSD13380F3T | Port data (.epro Manufacturer Part attr) | 2
R1,R2,R3,R15,R17,R19,R20 | 10kΩ | 10kΩ | R0201 | YAGEO(国巨) | RC0201FR-0710KL | Port data (.epro Manufacturer Part attr) | 7
R4 | 510Ω | 510Ω | R0201 | Walsin(华新科) | WR02X511JAL | Port data (.epro Manufacturer Part attr) | 1
R5,R9,R10,R11 | 2kΩ | 2kΩ | R0201 | LIZ(丽智电子) | CR0201JH0202G | Port data (.epro Manufacturer Part attr) | 4
R6 | 51kΩ | 51kΩ | R0201 | FH(风华) | RC-01W5102FT | Port data (.epro Manufacturer Part attr) | 1
R7,R8 | 5.1kΩ | 5.1kΩ | R0201 | YAGEO(国巨) | RC0201FR-075K1L | Port data (.epro Manufacturer Part attr) | 2
R13 | 37.4kΩ, 1% | 37.4kΩ, 1% | R0402 | YAGEO(国巨) | RC0402FR-0737K4L | Port data (.epro Manufacturer Part attr) | 1
R21 | 10mΩ, 1% | 10mΩ, 1% | R0402 | SEI(Stackpole Electronics Inc.) | CSRF0402FT10L0 | Port data (.epro Manufacturer Part attr) | 1
R23,R26 | 27Ω | 27Ω | R0201 | YAGEO(国巨) | RC0201FR-0727RL | Port data (.epro Manufacturer Part attr) | 2
R27 | 2.2Ω | 2.2Ω | R0201 | UNI-ROYAL(厚声) | 0201WMF220KTEE | Port data (.epro Manufacturer Part attr) | 1
R28 | 220Ω | 220Ω |  | YAGEO(国巨) | RC0201FR-07220RL | OpenEarable official BOM / web-verified real part | 1
SW1 | TS2819A 230GF | TS2819A 230GF | SW-SMD_4P-L2.8-W1.9-P1.16-LS3.0 | SHOU HAN(首韩) | TS2819A 230gf | Port data (.epro Manufacturer Part attr) | 1
U1 | BMI160 | BMI160 | LGA-14_L3.0-W2.5-P0.50-BL | Bosch | BMI160 | Port data (.epro Manufacturer Part attr) | 1 | RESOLVED (previously flagged as a discrepancy): the schematic's component value used to say "BMX160" (Bosch 9-axis IMU incl. magnetometer) while the sourced Manufacturer Part was "BMI160" (6-axis, accel+gyro, no magnetometer). Resolved by checking the actual wiring: BMI160's ASDX/ASCX pins (2/3) -- its auxiliary interface for an *external* magnetometer -- are tied to GND in this schematic, which is the documented BMI160 reference-design pattern for "aux interface unused." BMX160 has no equivalent external-mag pins to ground (its magnetometer is on-die, using that same interface internally) -- grounding them wouldn't be a valid BMX160 configuration. Schematic Value corrected to BMI160 to match. No magnetometer data is available from this part.
U2 | BQ25120AYFPR | BQ25120AYFPR | DSBGA-25_L2.5-W2.6-R5-C5-P0.40-BL | TI(德州仪器) | BQ25120AYFPR | Port data (.epro Manufacturer Part attr) | 1
U3,U9 | AP22916BCA4-7 | AP22916BCA4-7 | X1-WLB0808-4_L0.8-W0.8-P0.40-TL | DIODES(美台) | AP22916BCA4-7 | Port data (.epro Manufacturer Part attr) | 2
U4 | XL-0201SURC | XL-0201SURC | LED-SMD_L0.65-W0.35-P0.41_XL-0201SURC | XINGLIGHT(成兴光) | XL-0201SURC | Port data (.epro Manufacturer Part attr) | 1
U5 | KTD2026 | KTD2026 | DFN-8_L1.5-W1.5-P0.40-BL-EP | KINETIC(芯凯) | KTD2026EWE-TR | Port data (.epro Manufacturer Part attr) | 1
U6 | BQ27220YZFR | BQ27220YZFR | DSBGA-9_L1.7-W1.6-R3-C3-P0.50-BL | TI(德州仪器) | BQ27220YZFR | Port data (.epro Manufacturer Part attr) | 1
U8 | 1MΩ | 1MΩ | R0201 | UNI-ROYAL(厚声) | CQ01WMJ0105TEE | Port data (.epro Manufacturer Part attr) | 1
U10 | SN74AXC4T774RSVR | SN74AXC4T774RSVR | UQFN-16_L2.6-W1.8-P0.40-BL | TI(德州仪器) | SN74AXC4T774RSVR | Port data (.epro Manufacturer Part attr) | 1
U12 | GT-USB-9047A | GT-USB-9047A | USB-C-SMD_GT-USB-9047A | G-Switch(品赞) | GT-USB-9047A | Port data (.epro Manufacturer Part attr) | 1
U13 | SPH0641LU4H-1 | SPH0641LU4H-1 | MIC-SMD_5P_L3.5-W2.7-P0.82_SPH0641LU4H-1 | Knowles(楼氏) | SPH0641LU4H-1 | Port data (.epro Manufacturer Part attr) | 1
U14 | MX25R6435FBFIL0 | MX25R6435FBFIL0 | WLCSP-22_MX25R6435FBFIL0 | MXIC(旺宏电子) | MX25R6435FBFIL0 | Port data (.epro Manufacturer Part attr) | 1
U15 | ADAU1860BCBZRL | ADAU1860BCBZRL | BGA-56_L3.0-W2.7-P0.35-R8-C7-TL | ADI(亚德诺) | ADAU1860BCBZRL | Port data (.epro Manufacturer Part attr) | 1
X1 | Q13FC1350000200 | Q13FC1350000200 | FC-135R_L3.2-W1.5 | EPSON(爱普生) | Q13FC1350000200 | Port data (.epro Manufacturer Part attr) | 1

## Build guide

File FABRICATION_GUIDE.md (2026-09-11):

# Ordering the Haven dev board

Board: `haven_dev_board.kicad_pcb`, commit `fd2960b` on `experiment/codex-astra-routing`.
73.1mm × 161.1mm, 6 copper layers, 1.6mm finished thickness.

## Why this needs an assembly service, not just a bare board

This board carries a BGA-56 (0.35mm ball pitch), a DSBGA-25 (0.4mm pitch), a
WLCSP-22, and a couple dozen 0201 passives. None of that is hand-solderable —
0.35mm pitch is below what a soldering iron and steady hands can reliably do,
and a BGA has no exposed leads at all; it needs solder paste + a stencil +
reflow, ideally with pick-and-place for placement accuracy. **Order fab and
assembly together (PCBA / "turnkey"), not a bare board.**

## Files (already generated in `fab_output/`)

| File | Purpose |
|---|---|
| `haven_dev_board-gerbers.zip` | Bare-board fab: copper layers, mask, silkscreen, drill, board outline |
| `haven_dev_board-pos.csv` | Pick-and-place (component position + rotation), mm/CSV |
| `../HAVEN_BOM.csv` | Bill of materials — every part has a manufacturer + MPN |

Re-run after any future board edit:
```
kicad-cli pcb export gerbers --output fab_output/gerbers/ kicad/haven_dev_board.kicad_pcb
kicad-cli pcb export drill --output fab_output/gerbers/ kicad/haven_dev_board.kicad_pcb
kicad-cli pcb export pos --format csv --units mm --side both --output fab_output/haven_dev_board-pos.csv kicad/haven_dev_board.kicad_pcb
```

## Picking a fab/assembly house

JLCPCB and PCBWay both do turnkey PCBA and both handle 6-layer boards and
BGA/WLCSP placement routinely — this isn't unusual work for them. A few things
specific to this board to flag when you get a quote:

- **6 layers.** More expensive than the 2-layer boards these services are
  cheapest at, but well within normal turnkey capability.
- **0.35mm BGA pitch.** Some services quote "advanced" or "high-density"
  assembly for anything under 0.4-0.5mm pitch — expect a small surcharge and
  possibly a slightly longer lead time (extra AOI/X-ray inspection on BGA
  joints), not a capability problem.
- **Part sourcing.** The BOM's manufacturer/MPN columns came from the original
  EasyEDA source data — worth spot-checking that JLC/PCBWay's own parts
  library actually stocks each one (their upload tools cross-reference
  automatically and will flag anything missing so you can substitute or
  provide it yourself).
- **Order at least 3-5 assembled boards**, not 1. At this pitch, a DOA or a
  bad joint on first assembly run is a real possibility, and you don't want
  your only board to be the one with a problem.

## What to actually upload

Most turnkey flows want, as separate uploads:
1. `haven_dev_board-gerbers.zip` (includes the drill file)
2. `HAVEN_BOM.csv`
3. `haven_dev_board-pos.csv`

Their web tool will parse all three, show you a 3D preview to visually
sanity-check part placement/orientation before you pay, and flag any BOM line
it can't source. **Look at that 3D preview carefully** — it's the cheapest
possible point to catch a rotated or flipped part before money is spent.

## After it arrives

The firmware side (`haven_zephyr_app`) has the ADAU1860 driver currently
stubbed pending real hardware — first bring-up priority once boards land is
almost certainly: power-on, confirm the MDBT531 boots and enumerates over
SWD/USB, then bring up I2C to the ADAU1860 codec (SCL1/SDA1, closed tonight)
before anything audio-shaped is attempted.

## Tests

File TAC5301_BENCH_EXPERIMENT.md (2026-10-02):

# TAC5301-Q1 bench latency experiment — the thing the evaluation doc said to do before trusting the PCB

`TAC5301_EVALUATION.md` (branch `docs/tac5301-q1-evaluation`) picked TAC5301-Q1 over the
AIC3254 based on datasheet-table arithmetic, not a measurement, and said explicitly: *"Before
any schematic work: confirm real hear-through latency and that the 3+2 (or 3+3) band split
sounds and measures correctly before committing PCB time to it."* That didn't happen before the
`redesign/tac5301-codec-swap` branch's schematic/PCB work went ahead. This is that experiment,
designed for real — a minimal breadboard loopback, not a eval-board purchase (TI doesn't sell a
dedicated EVM for this part), using a real register sequence pulled directly from the datasheet
(SLASFD9A, fetched and read in full this pass — not inferred from the summary tables the
evaluation doc cited).

**Cost: ~$10-15 in parts, all already on hand or trivial to source. Time: an afternoon, not a
week — most of the "cheap experiment" cost in the original architecture memo was the AIC3254
EVM purchase, which this avoids entirely.**

## What this proves or disproves

1. **Real hear-through latency**, measured, not computed from filter-delay tables. The
   evaluation doc's ~120-190µs is worst-case-pairing arithmetic from Tables 6-32–6-36 (ADC) and
   6-56–6-60 (DAC) — add the two group-delay-in-samples figures, divide by fS. A measurement
   also catches anything the arithmetic can't: analog path delay, ADC/DAC conversion overhead
   not captured in the "filter" group delay alone, and PCB-level surprises.
2. **Whether the loopback mixer path actually works as the register map describes** (Figure
   6-61: ADC output → loopback mixer → DAC's own processing chain, entirely inside the chip, no
   ASI/I2S round-trip needed for the audio itself — only BCLK/FSYNC need to toggle to keep the
   PLL locked).

This experiment does NOT test the 3+3 biquad coefficient split (notch-filter correctness) —
that's a second, separate bench step once the base loopback path is confirmed working, using
Haven's actual 5-band coefficients instead of the unity/passthrough default. See "Phase 2" below.

## Real parts list (verified against the actual datasheet this pass)

| Part | Role | Notes |
|---|---|---|
| TAC5301QRGERQ1 | DUT | Confirmed 2,834 in stock at Mouser, $1.07-1.61/unit (see `docs/tac5301-q1-evaluation` branch) |
| nRF5340 DK | I2C master + I2S/BCLK clock source | Already on hand per the architecture memo's own Step 1 — no new purchase |
| CMA-4544PF-W | Analog electret mic | Same part already in the real schematic (U-whatever on `redesign/tac5301-codec-swap`) — pull one off that BOM, don't buy a second design |
| A small speaker or headphone driver | Audio output | Anything 8-32Ω, doesn't need to be the final earpiece driver |
| VQFN-24 0.5mm breakout/adapter board | Hand-solder or reflow the TAC5301 onto something breadboard-pitch | **This is the one real risk item** — 0.5mm QFN is not hand-solderable with an iron reliably; either get a QFN-24 breakout PCB (common, ~$2-5, many sellers) and reflow/hot-air it on, or find someone with a hot-air/reflow setup. Don't attempt it with just an iron and solder wick. |
| HVDD supply, 7.5V (MICBIAS default) to ~9V | Bench power supply or the boost converter already designed this session | A bench supply set to 9V is simplest for this test — don't need the real TPS61040 boost circuit for a bring-up bench test |
| IOVDD/AVDD/DVDD (1.8V/3.3V as the datasheet's power table specifies) | Digital/analog supply rails | Bench supply or an existing 3.3V/1.8V LDO breakout |
| Decoupling caps per pin | Per datasheet layout guidance | Standard 0.1µF/pin practice — same as every other codec bring-up in this project's history |

## Real wiring (from the actual datasheet, this pass)

- **Mic input**: CMA-4544PF-W's output pin → AC-coupling cap → TAC5301's IN1P (single-ended
  mode), IN1M grounded after its own AC-coupling cap (datasheet §6.3.3, Figure 6-18,
  "AC-Coupled Microphone... Single-ended Input Connection" — exactly the CMA-4544PF-W bias
  circuit already designed on the real board this session, just without the extra hop through
  R29/C50/C51/C52's specific component values — a simpler bench version is fine for this test).
- **DAC output**: OUT1P/OUT1M → speaker/headphone driver, differential or single-ended per
  datasheet §6.3.4 (mirrors the input side).
- **MICBIAS**: pin sourced from HVDD per the datasheet's mic-bias circuit (§6.3.6) — this is the
  same architecture as the real board's TPS61040 boost converter, just substitutable with a bench
  supply at this stage.
- **I2C**: SDA/SCL to the nRF5340 DK's TWI pins. **7-bit I2C address is 0x50** (datasheet §6.4.1,
  "the 7-bit I2C target address is fixed to 7'b1010000" — confirmed directly, not assumed).
- **BCLK/FSYNC**: from the DK's I2S peripheral, running continuously at BCLK = 256×fS (datasheet
  §6.3.2: the device's PLL auto-configures every internal clock from the BCLK/FSYNC ratio, no
  external crystal or MCLK pin needed — confirmed directly from the datasheet text, this is a
  real simplification the evaluation doc didn't know to mention). For fS = 48kHz: BCLK =
  12.288MHz, FSYNC = 48kHz. **No real I2S audio DATA needs to be transmitted** — see below.

## The actual I2C init sequence (every address verified against the real register map, SLASFD9A §7)

The datasheet's register space is paged (§7.1: "Page 0" = §7.1.1 register group, "Page 1" =
§7.1.2 register group, confirmed by matching each section's own heading, e.g. "7.1.1 TAC5301-Q1
_B0_P0 Registers" = Page 0). Register 0x00 on every page is the page-select register,
write-before-use.

**One real, useful finding from reading the actual reset values (not just the field
descriptions): several of the registers this test needs are already correct at power-on reset**,
which makes the real minimal sequence shorter than the evaluation doc could have anticipated:

| Step | Page | Reg (hex) | Name | Value | Why |
|---|---|---|---|---|---|
| already default | 0 | — | `CH_EN` (0x76) | reset = `0xCC` | IN_CH1_EN, IN_CH2_EN, OUT_CH1_EN, OUT_CH2_EN all already enabled (datasheet §7.1.1.86) — **no write needed** |
| already default | 0 | — | `ADC_BQ1..3`, `DAC_BQ1..3` coefficients | reset N0 = `0x7FFFFFFF`, N1/N2/D1/D2 = `0` | This is a unity-gain passthrough biquad (H(z) = 1) at reset, per the register map's own listed reset values (§7.2.1-7.2.4 tables) — **the chip ships configured for clean passthrough on all 6 biquad slots**, so Phase 1 of this test (raw loopback latency) needs zero coefficient writes |
| 1 | 0 | `0x50` | `ADC_CH1_CFG0` | `0x40` | bits[7:6]=01 (single-ended analog input, matching the CMA-4544PF-W wiring), bits[3:2]=00 (AC-coupled, default) |
| 2 | 0 | `0x72` | `DSP_CFG0` | `0x9C` | **Corrected from an earlier draft of this doc**, which only set bits[7:6] and missed bits[3:2]. Full register (§7.1.1.84, Table 7-86): bits[7:6]=`10`b ultra-low-latency ADC decimation filter; bits[5:4]=`01`b (reset default, 1Hz HPF — left alone); **bits[3:2]=`11`b, 3 biquads per ADC channel** (reset default is `10`b = only 2/channel — doesn't affect Phase 1 since the extra slot is still unity at reset, but Phase 2 needs this bit set to reach all 3 bands) |
| 3 | 0 | `0x73` | `DSP_CFG1` | `0x9C` | Same correction, DAC side (§7.1.1.85, Table 7-87): bits[7:6]=`10`b ultra-low-latency DAC interpolation filter; bits[5:4]=`01`b (reset default HPF, left alone); **bits[3:2]=`11`b, 3 biquads per DAC channel** |
| 4 | 0 | `0x2C` | `MIXER_CFG0` | `0x10` | bit4 `EN_LOOPBACK_MIXER`=1, everything else 0 — **this also keeps `EN_DAC_ASI_MIXER` (bit7) at its reset-default 0**, meaning the DAC hears *only* the loopback path, nothing from the (unused) I2S data stream, which is why no real ASI audio data needs to flow for this test |
| 5 | 0 | `0x78` | `PWR_CFG` | `0xE0` | bit7 `ADC_PDZ`=1, bit6 `DAC_PDZ`=1, bit5 `MICBIAS_PDZ`=1 — power up ADC, DAC, and the mic bias together |
| optional | 1 | `0x73` | `MICBIAS_CFG` | `0xA0` (reset default) | MICBIAS_VAL=1010b=7.5V is already the reset value — only write this if a different mic-bias voltage is wanted |

That's **5 register writes** for a working ADC→loopback→DAC passthrough path (plus the implicit
page-0 default, since page 0 is also the reset state — no page-select write needed unless you've
touched page 1 first for the optional MICBIAS_CFG write, in which case write `0x00`=`0x00` to
return to page 0 before the above).

## Procedure

1. Wire the breadboard per above. Power up IOVDD/AVDD/DVDD per the datasheet's supply sequencing
   notes (§6.4), then HVDD last (mic bias only needs to be live once MICBIAS_PDZ is set, step 5).
2. Start BCLK/FSYNC toggling from the nRF5340 DK *before* sending the I2C sequence — the PLL
   needs a running clock to lock onto (§6.3.2).
3. Send the 5-write sequence above over I2C.
4. **Reuse `haven-zephyr-app/tools/calibration/measure.py` directly, standalone** — it has no BLE
   dependency (confirmed by reading it this pass: `click()` and `delay_seconds()` are pure
   numpy/scipy, `SoundDeviceIO.play_and_record()` is a thin `sounddevice` wrapper). Skip the
   `Rig`/`HavenSession` orchestration layer entirely (that's BLE-coupled to the real Haven
   firmware, which doesn't exist for this part yet) and call the measurement functions directly:
   ```python
   import sys; sys.path.insert(0, "path/to/haven-zephyr-app/tools/calibration")
   from measure import click, delay_seconds
   from audio_io import SoundDeviceIO
   # same open-ear-reference / in-ear-hear-through structure as latency.py's run(),
   # just without the BLE bypass toggle -- the TAC5301 IS the hear-through path,
   # continuously, once the 5 writes above are sent.
   ```
5. Compare the measured device latency against the evaluation doc's ~120-190µs estimate and the
   300µs comb-filter threshold from `HARDWARE_ARCHITECTURE_DECISION.md`.
6. **While the breadboard is already wired and powered, measure real current draw** (multimeter
   in series on the AVDD/HVDD/IOVDD supplies, or a USB power meter if those rails are bench-
   supplied from one source) during the hear-through test. This is nearly free to add to the same
   session and settles a real, previously-undocumented finding: the datasheet's own tables put
   TAC5301-Q1's hear-through current meaningfully higher than the ADAU1860's (see
   `POWER_BUDGET.md`'s 2026-10-01 update) — a real measurement replaces that bracketed estimate.

## Phase 2 (only if Phase 1 passes): the actual notch-filter coefficients

Once raw loopback latency is confirmed acceptable, repeat with Haven's real 5-band biquad
coefficients split across the two biquad banks (the evaluation doc's open question —
"whether the 3+3 loopback split can actually implement 5 independent notch/peaking bands,"
reasoned through on paper but not bench-verified) instead of the reset-default unity
coefficients.

**A real correction to the evaluation doc's assumption, found reading the full register map this
pass**: the 3 biquads allocated to a channel in "3 biquads per channel" mode are **not** a
contiguous block (filters 1, 2, 3) — they're interleaved across the device's 4-channel-capable
biquad bank (§6.3.7.1.5 Table 6-17 / §6.3.7.2.4 Table 6-41): channel 1 (the only channel this mono
part uses) gets **filters 1, 5, and 9**, with filters 2/3/4, 6/7/8, 10/11/12 reserved for channels
2-4 (unused here). Concretely, for Haven's mono hear-through path:

| Biquad | Page/registers (ADC) | Page/registers (DAC) |
|---|---|---|
| Channel-1 biquad A (filter 1) | Page 8, R8-R27 | Page 16, R8-R27 |
| Channel-1 biquad B (filter 5) | Page 8, R88-R107 | Page 16, R88-R107 |
| Channel-1 biquad C (filter 9) | Page 9, R48-R67 | Page 17, R48-R67 |

(Table 6-18 / 6-42 give the full filter→register mapping if a different split is ever wanted.)
Writing to filters 2/3/4/etc. would silently do nothing for this mono part — a real bug this
correction heads off before anyone wires up the wrong registers.

**Update, resolved for real**: the coefficient format and sign convention above were originally
written as "a reasonable inference, not confirmed" — that inference turned out to be wrong on 3 of
5 terms. TI publishes a dedicated application note, SLAAEH6 ("TAC5x1x and TAC5x1x-Q1 Programmable
Biquad Filters - Configuration and Applications"), fetched and read in full as a follow-up to this
doc. It states explicitly (not inferred): coefficients are Q1.31 two's-complement, and the real
conversion from standard RBJ `[b0,b1,b2,a1,a2]` is

```
N0 = b0
N1 = b1 / 2   -- NOT b1 directly
N2 = b2
D1 = -a1 / 2  -- negated AND halved
D2 = -a2      -- negated, not halved
```

(transfer function: `H(z) = (N0 + 2·N1·z⁻¹ + N2·z⁻²) / (2 − 2·D1·z⁻¹ + D2·z⁻²)`). This was wrong
in the first implementation of `haven-zephyr-app`'s TAC5301 driver (PR #17, since fixed in #18) —
N1/D1 need halving and D1/D2 need negation, neither of which an "unnegated textbook form" guess
would do. The bug would not have errored; it would have produced a filter with roughly the right
shape but a silently wrong center frequency/Q/depth. Caught by reading TI's own documentation
before any hardware use, which is exactly the kind of thing this bench experiment's own
measurement step would **not** have reliably caught either (a subtly-wrong notch can still sound
roughly right on a quick listen) — worth remembering that a bench pass on latency doesn't
by itself validate the coefficient math.

## What this doesn't settle

- Real supply sequencing edge cases (brown-out behavior, `BRWNOUT` register at 0x2E) — not
  needed for a bench bring-up, worth reading before a real product power-up sequence.
- PCB-level crosstalk/noise that a breadboard won't reproduce — the real board's layout (already
  routed, this session) is denser than a breadboard, so a clean bench measurement is necessary
  but not sufficient proof the real PCB performs identically.
- Everything in Phase 2 above.

---

*Sources: TAC5301-Q1 datasheet SLASFD9A (Rev. A, April 2025 / revised April 2026), fetched and
read in full this pass — §6.3.2 (PLL/clock auto-config), §6.3.3/6.3.4 (input/output channel
config), §6.3.6 (mic bias), §6.3.7.1.7/6.3.7.2.5 (filter mode selection, Tables 6-19/6-43),
§6.4.1 (I2C address), §6.4.2 (software reset), §7.1.1 (Page 0 registers: CH_EN 0x76, ADC_CH1_CFG0
0x50, MIXER_CFG0 0x2C, PWR_CFG 0x78, P0_R114/P0_R115 filter-select at 0x72/0x73), §7.1.2 (Page 1:
MICBIAS_CFG 0x73), §7.2 (biquad coefficient register reset values). `TAC5301_EVALUATION.md`
(`docs/tac5301-q1-evaluation` branch) for the open items this experiment addresses.
`haven-zephyr-app/tools/calibration/measure.py`, `audio_io.py` for the reusable measurement math.

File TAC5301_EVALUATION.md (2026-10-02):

# TAC5301-Q1 evaluation: a second QFN codec candidate, verified from the real datasheet

*Follow-up to `HARDWARE_ARCHITECTURE_DECISION.md` (2026-09-14), which recommended the TLV320AIC3254
pending an unresolved ~$200/1-week bench experiment. Written 2026-10-01 after the $500 board cost
became the actual blocker on shipping anything, prompting a fresh look at whether that bench
experiment can be narrowed or skipped by reading harder before spending money.*

## TL;DR

- **A second real candidate exists: TI's TAC5301-Q1** (VQFN-24, 4x4mm, mono, SLASFD9A — Apr 2025,
  revised Apr 2026, newer silicon than the AIC3254's 2014-revision datasheet).
- **My first read of it (conversation, not this doc) was wrong and is corrected here.** The
  feature list's "programmable EQ and biquad filters" plus a "12 biquad" figure in the biquad
  section reads like plenty of headroom. It isn't, read carelessly: **that 12 is a shared pool
  across the whole TAC5x1x family and is capped at 3 biquads per channel on this specific mono
  part** (datasheet §6.3.7.1.5, §6.3.7.2.4, both state "limited to 3/channel" explicitly). Caught
  this before it went into a recommendation — flagging the correction here rather than quietly
  fixing it, per this repo's own standing practice of disclosing reversed conclusions
  (`CODEX_NOTES.md`'s LRCLK/XTALI entries).
- **But the real number is still good enough, once the actual signal path is verified, not
  assumed.** The ADC-side chain and the DAC-side chain each have their own independent 3-biquad
  bank, and the DAC signal chain's mixer explicitly accepts **"ADC loopback"** as a selectable
  input, feeding straight into the DAC-side HPF/biquad stage (Figure 6-61, `EN_LOOPBACK_MIXER`
  register, Page 10 "ADC to DAC loopback mixer" coefficients). That means a hear-through signal
  can pick up **3 biquads on the way out of the ADC and another 3 on the way into the DAC, all
  inside the chip, no host round-trip** — up to 6 total, comfortably covering Haven's ≤5-band
  spec, split however's convenient (e.g. 3 ADC-side + 2 DAC-side).
- **Latency, from the real filter-characteristics tables, not an estimate:** ultra-low-latency
  mode gives ADC group delay of **2.7–2.8 samples** (Tables 6-32–6-36) and DAC group delay of
  **1.7–3.2 samples** depending on output rate (Tables 6-56–6-60), both in units of `1/fS`. At
  48kHz that's roughly **120–190µs combined** (worst-case pairing); it gets smaller at 96/192kHz.
  For comparison, the architecture memo's own threshold for audible comb-filtering starts around
  300µs — this is comfortably under it, in the same range as the ADAU1860's own *estimated*
  50–150µs, except this number comes from a published filter-characteristics table instead of an
  estimate.
- **Real stock, confirmed at Mouser (2026-09-30): 2,834 units, ships immediately.** Pricing at
  prototype quantities: $1.61 (qty 1), $1.18 (qty 10), $1.07 (qty 25), $1.00 (qty 100). TI's own
  site listing of $0.66 was stale/wrong — the real distributor price is 1.6–2.4x that, but still
  well under the AIC3254's $3.03. The 20-week figure on the listing is Mouser's *factory
  lead-time for restocking after current inventory runs out*, not a blocker — there's nowhere
  near enough demand from a handful of prototype boards to touch that. **This was the one open
  item and it's now closed: real, in-stock, cheap.**

## What this changes vs. the AIC3254 recommendation

The AIC3254 path had one specific, unresolved compromise: its lowest-latency ADC filter tier
(Filter C) supports 5 biquads, but its lowest-latency **DAC** filter tier only goes to 4 — the 5th
band would need the higher-group-delay Filter A. TAC5301-Q1 doesn't have that asymmetry in the
same way (3+3 split across two independent chains instead of one chain maxing out), though it
trades "5 on one side" for "has to split across both sides to reach 5," which needs confirming in
practice: I have not confirmed whether all 6 available biquad slots can independently take
arbitrary notch/peaking coefficients (vs. some being reserved for HPF-like fixed roles) or whether
splitting a single logical dampening band's coefficients across two different digital stages
(ADC-side vs. DAC-side, at potentially different internal sample domains) introduces any
combination artifact. This is a real open question, not assumed clean.

Two things this candidate does *not* need that the AIC3254 path was uncertain about: no miniDSP,
no PurePath Studio, no "is there a register-only path or do we need the DSP tool" question at all
— every biquad on both sides is plain register coefficients (`ADC_BQ1..12_*`, `DAC_BQ1..N_*`),
confirmed directly from the register map (§7.2.3 onward), not inferred.

## What's still unverified (do this before writing any schematic)

1. ~~Real distributor stock and price~~ **Resolved 2026-09-30**: 2,834 in stock at Mouser,
   $1.07–1.61/unit at prototype quantities, ships immediately. See TL;DR.
2. **Whether the 3+3 loopback split can actually implement 5 independent notch/peaking bands** —
   reasoned through on paper this tick, not bench-verified. The ADC loopback path to the DAC chain
   does **not** appear to pass through the DAC chain's sample-rate converter (Figure 6-61 shows the
   SRC block specifically in the *Aux ASI* input path, a separate branch from the "Tone Generator or
   ADC loopback" input into the adder) — so both biquad banks should be operating on the same
   signal at the same sample rate, with no resampling between them. Under that condition, cascading
   any 5 (of the available 6) independently-programmed biquad sections is a standard LTI cascade:
   the combined transfer function is just the product of each section's response, regardless of
   which physical bank each one lives in. **One real firmware requirement this implies**: each
   side's HPF (`ADC_DSP_HPF_SEL`/`DAC_DSP_HPF_SEL`, Tables 6-15/6-39) and digital volume control
   need to be left at their lowest-cutoff/unity settings, or they'd act as extra, unaccounted-for
   filter stages in the cascade — a straightforward init-sequence detail, not a redesign. This
   reasoning is solid enough to plan around but should still get a real bench check (a swept sine
   through both banks configured) before it's treated as settled, same as item 3 below.
3. The datasheet's own group delay numbers are worst-case-pairing arithmetic done by me in this
   doc, not a measured round-trip on real hardware. Same caveat the architecture memo already
   raised for the AIC3254: **read the real thing, but bench it before it's a safety claim.**

## Recommendation

**TAC5301-Q1 over TLV320AIC3254, pending the bench check both parts still need.** Reasoning:

| | TAC5301-Q1 | TLV320AIC3254 |
|---|---|---|
| Price (prototype qty) | $1.07–1.61 (confirmed, Mouser) | $3.03 (JLC catalog) |
| Stock | 2,834 @ Mouser, ships now | not independently re-confirmed this pass |
| Biquads for 5 bands | 3+3 across two banks, needs the paper-verified split (§ above) | 5 on ADC (Filter C), only 4 on DAC at the same latency tier — needs Filter A for the 5th, at a latency cost |
| Group delay (ultra-low-latency, 48kHz) | ~120–190µs combined, from real filter tables | not fully pinned down from public docs this pass |
| DSP tool dependency | none — pure register writes, confirmed from register map | none for fixed blocks; miniDSP only if going beyond them |
| Datasheet currency | Apr 2025, rev. Apr 2026 | Sept 2008, rev. Nov 2014 |
| Package | VQFN-24, 4×4mm | VQFN-32, 5×5mm |

TAC5301-Q1 wins on price, confirmed stock, and datasheet-sourced (not estimated) latency numbers.
Its one real asterisk — needing the 5 bands split 3+2 (or similar) across two independently-clocked
biquad banks instead of 5 in one bank — is reasoned through above as sound, not hand-waved, but
it's paper reasoning, not a bench measurement.

**Before any schematic work**: run the cheap experiment the architecture memo already proposed
(§7 there), but aimed at this part instead of the AIC3254 — a TAC5301-Q1 costs about $1.50 in
parts; TI doesn't appear to sell a dedicated EVM for it the way it does for the AIC3254 family, so
the practical version of that experiment is likely a small breakout/dead-bug prototype on a
breadboard-friendly adapter rather than an off-the-shelf eval board. Confirm real hear-through
latency and that the 3+2 (or 3+3) band split sounds and measures correctly before committing PCB
time to it.

---

*Sources: TAC5301-Q1 datasheet SLASFD9A (Apr 2025, rev. Apr 2026) — §6.3.7.1 ADC Signal-Chain
(Figure 6-23), §6.3.7.1.5 ADC biquads ("limited to 3/channel"), §6.3.7.1.7.2/6.3.7.1.7.3 ADC
low-/ultra-low-latency filter tables (6-27 through 6-36), §6.3.7.2 DAC Signal-Chain (Figure 6-61,
"Tone Generator or ADC loopback" mixer input), §6.3.7.2.4 DAC biquads, §6.3.7.2.5.2/6.3.7.2.5.3 DAC
low-/ultra-low-latency filter tables (6-51 through 6-60), §7.2.3 Page 10 register map ("ADC to DAC
loopback mixer"). `HARDWARE_ARCHITECTURE_DECISION.md` (2026-09-14, this repo) for the latency
threshold derivation and the AIC3254 comparison baseline.

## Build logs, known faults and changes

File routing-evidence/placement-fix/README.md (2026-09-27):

# Placement fix: crystals and decoupling back next to their chips

Fixes the finding in `HAVEN_HARDWARE_REVIEW.md` §0.7 / issue #4: the 5×
rescale left both crystals and every decoupling cap 8–50 mm from the part
they serve. Nine placement-only stages, each DRC-gated (zero new violation
identities by type+description, unconnected count not worse) before commit.

Tooling: KiCad **9.0.8** (`kicad-cli pcb drc --format json --severity-all
--all-track-errors`), pcbnew Python from the same install, the project's
`tools/route_lib.py` / `multilayer_route.py` / `placement_lib.py`, plus two
new tools written for this work: `tools/move_two_terminal.py` (generic
two-terminal relocation with DRC-clean routing) and `tools/stage.sh` (one
gated stage per run; restores the board unless the diff is clean).
`tools/measure_placement.py` produces the distance table.

## Result

`.kicad_pcb` header unchanged from master (`version 20241229`,
`generator_version "9.0"`).

### DRC, before and after (kicad-cli 9.0.8)

| | violations | by type | unconnected |
|---|---|---|---|
| master `1e7c6d2` (baseline.json) | 219 | clearance 99, lib_footprint_mismatch 78, solder_mask_bridge 33, track_dangling 9 | 2 |
| this branch (after_i.json) | **219** | **identical multiset** | **2** (the same two cosmetic U15 same-net pairs) |

`tools/drc_diff.py baseline.json after_i.json` → 0 new violation identities,
0 new unconnected. Per-stage reports `after_a.json` … `after_i.json` are in
this directory.

### Distances — footprint centres (`tools/measure_placement.py`)

| pair | master | this PR |
|---|---|---|
| X1 (32.768 kHz) ↔ MDBT531 | 30.4 mm | 8.9 mm (module centre; see pad table) |
| X1 ↔ C2 / C14 (9 pF) | 10.9 / 10.9 mm | 1.8 / 1.8 mm |
| CRYSTAL1 (24.576 MHz) ↔ U15 | 13.8 mm | 5.2 mm |
| CRYSTAL1 ↔ C45 / C46 (33 pF) | 8.1 / 9.7 mm | 1.7 / 2.1 mm |
| R28 (220 Ω, XTALO) ↔ U15 | 21.8 mm | 3.9 mm |
| U15 ↔ C33 (V_LS 10 µF) | 10.0 mm | 2.5 mm |
| U15 ↔ C31 (100 nF, `$1N151`) | 13.1 mm | 1.9 mm |
| MDBT531 ↔ C1 (+1.8V 1 µF) | 25.9 mm | 7.6 mm (module centre; see pad table) |
| U2 ↔ L2 (buck inductor) | 12.9 mm | 2.9 mm |
| U2 ↔ C16 / C18 / C22 | 13.3 / 12.7 / 10.7 mm | 2.4 / 1.8 / 1.5 mm |
| U6 ↔ C21 | 8.3 mm | 8.3 mm (not moved) |

### Distances — pad to pin (what actually matters electrically)

| connection | master | this PR |
|---|---|---|
| X1.1 (XL1) ↔ MDBT531 pin 34 | 23.8 mm | **2.4 mm** |
| X1.2 (XL2) ↔ MDBT531 pin 36 | 24.0 mm | **2.5 mm** |
| CRYSTAL1.1 (XTALI) ↔ U15 ball B7 | 13.6 mm | **6.0 mm** |
| R28.2 (XTALO) ↔ U15 ball B6 | 21.1 mm | **4.5 mm** |
| C33.2 (V_LS) ↔ nearest U15 V_LS ball | 8.8 mm | **1.5 mm** |
| C31.1 (`$1N151`) ↔ U15 ball A3 | 12.0 mm | **1.4 mm** |
| C1.2 (+1.8V) ↔ MDBT531 pin 38 | 23.5 mm | **1.0 mm** |
| C22.1 (VUSB) ↔ U2 ball A2 | 10.2 mm | **0.9 mm** |
| C16.2 (V_PMID) ↔ U2 ball A3 | 13.6 mm | **1.5 mm** |
| C18.1 (+1.8V) ↔ U2 ball B5 | 12.8 mm | **1.1 mm** |
| L2.1 (SW) ↔ U2 ball A4 | 11.7 mm | **2.2 mm** |

### Honest notes on what was and wasn't achieved

- **Codec crystal: 6.0 mm pad-to-ball, not ~3 mm.** The XTALI/XTALO escapes
  from the 0.35 mm BGA are the constraint: the two escape vias kept from the
  original routing sit in a B.Cu pocket walled off by the TDO / SDA1 / DOUT
  diagonals, so the crystal had to go just east of TDO, with each net hopping
  over TDO on F.Cu through one new via. Total XTALI path ≈ 6 mm, load caps
  1.7/2.1 mm from the crystal, GND returns on their own vias — a large
  improvement over 13.6 mm + 8–10 mm caps, and as close as the fan-out allows
  without re-doing the BGA escape itself. If the oscillator still misbehaves
  on hardware, the next lever is the crystal's load-cap values, not placement.
- **32.768 kHz crystal: 2.4 mm to the module pins**, caps 1.8 mm. Done.
- **C31 is a codec cap, not U14's.** The §0.7 table listed U14 ↔ C31; the
  netlist puts C31 on `$1N151` = U15 balls A3/B3. It is now 1.4 mm from A3.
  U14 (QSPI flash, V_LS balls D2/H4) — *correction (crystal-escape stage):*
  it **does** have a cap, **C27** (100 nF, V_LS/GND), drawn beside U14 on
  the schematic and left 9.8 mm away by the rescale; moved under the flash
  in `../crystal-escape/`. No BOM addition needed.
- **U15 has no +1.8V ball**; its supply is V_LS (C33). C1 is the *module's*
  +1.8V cap and now sits 1.0 mm from pin 38. The §0.7 row "U15 ↔ C1" was
  therefore the wrong pairing; it is left in the centre table for
  traceability (it got longer because C1 moved to where it belongs).
- **U6 ↔ C21 (fuel gauge, 8.3 mm) not moved** — lowest-risk item on the list
  and the U6 corner is dense; left for a later pass.
- All new copper is 0.09 mm track (the board's baseline width) and 0.20/0.10
  vias, the same as the rest of the board.

## Method (per stage)

1. `find_spot` for collision-free positions on the target layer (flipped for
   the test — see tooling fixes below), sorted by distance to the IC pins the
   part's nets land on.
2. Route each pad with `multilayer_astar_mixed` under the **net's own
   `.kicad_dru` per-pair clearance exceptions** (parsed from the rule file;
   never looser than the rules), 0.215 mm otherwise; the pad end is forced onto
   the part's layer; anchors are IC pads (on their own layer), through-vias,
   outer-layer track ends, or a **new via stitched onto the net's inner-layer
   run** outside the BGA escape field. GND pads get a 0.20/0.10 via into the
   planes.
3. Lay each route as found; on any failure reload the stage start board and
   try the next spot.
4. `kicad-cli pcb drc`; `tools/clean_dangling.sh` removes only *new*
   `track_dangling` items (the old feeds to the part's former position) inside
   a window; re-check every new via against the final board.
5. `tools/drc_diff.py prev after` must report zero new identities → commit.

## Tooling defects found and fixed along the way (each caught by the DRC gate)

- `find_spot` tested candidates un-flipped; `move()` flips the part when the
  layer changes, mirroring the pads — a cleared spot could put a pad 0.193 mm
  from a via. Now flips for the test.
- A track *end* on an inner layer was accepted as a routing anchor: the route
  looked complete and connected nothing. Anchors now carry their layer; inner
  runs are only usable via a stitched via.
- IC pads were anchors without a layer: F.Cu copper was laid from a B.Cu ball.
- The GND route constrained the via end instead of the pad end.
- Hole-to-hole was checked assuming every via drills 0.10 mm; the board also
  has 0.15 mm drills (0.1806 mm DRC miss). Checks now read each via's drill.
- A path's own vias were not checked against each other (two hops 0.28 mm
  apart). Rejected now, and the via penalty raised so decoupling routes stay
  single-layer where they can.
- `R28`'s placement search ignored the crystal's own pads (a GND/XTALO
  short). Exclusion lists removed.
- The XTALO escape via looked "blocked" at 0.20 mm because it legitimately
  hugs a TDO track at 0.11 mm under a rule exception; routing must use the
  same exceptions the rules grant.

## Files

- `baseline.json`, `after_a.json` … `after_i.json` — kicad-cli DRC reports per stage.
- `group_a_x1.py`, `group_b_crystal.py` — the two crystal-group scripts (run from `kicad/` with KiCad's python).
- `../../tools/move_two_terminal.py`, `../../tools/stage.sh`, `../../tools/measure_placement.py` — generic tools.

Regenerate fab outputs before ordering, per `FABRICATION_GUIDE.md`:
```
kicad-cli pcb export gerbers --output fab_output/gerbers/ kicad/haven_dev_board.kicad_pcb
kicad-cli pcb export drill   --output fab_output/gerbers/ kicad/haven_dev_board.kicad_pcb
kicad-cli pcb export pos --format csv --units mm --side both --output fab_output/haven_dev_board-pos.csv kicad/haven_dev_board.kicad_pcb
```
(`fab_output/` is not tracked in git.)

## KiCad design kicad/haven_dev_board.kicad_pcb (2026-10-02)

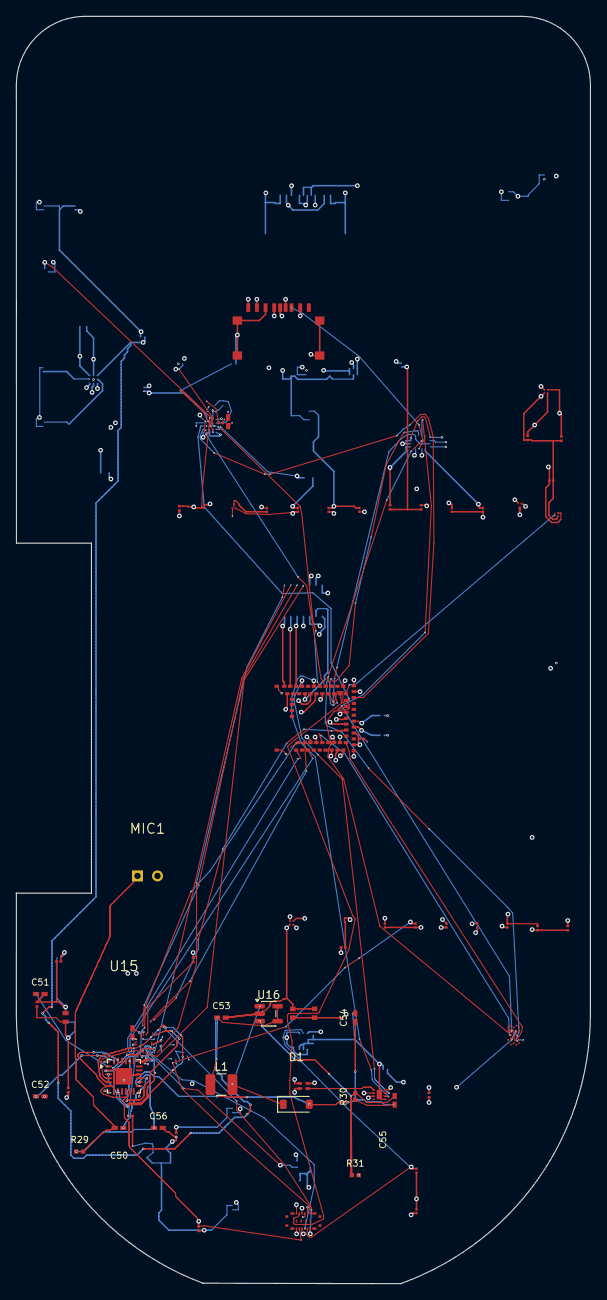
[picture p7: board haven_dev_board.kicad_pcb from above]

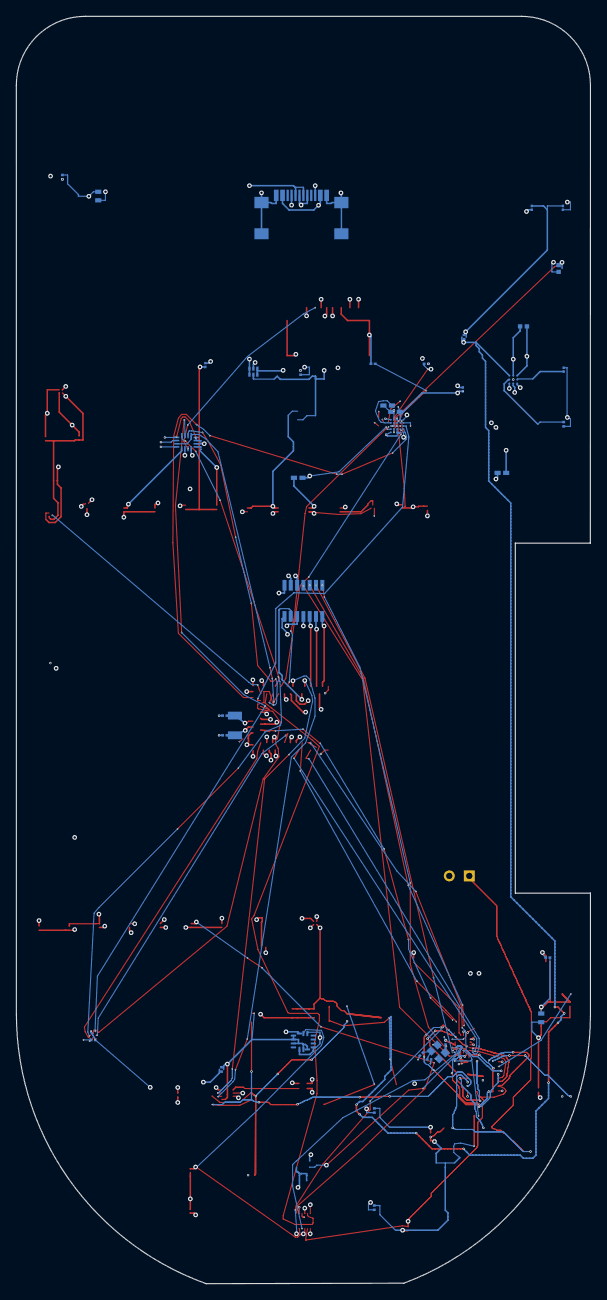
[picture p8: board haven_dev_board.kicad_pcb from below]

Board: 6 copper layers, 72.9 x 160.9 mm, 102 parts (38 on the bottom side), 81 nets.

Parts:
C1, C5, C7, C9, C10, C21, C28, C29, C32, C36, C47: 1uF.1; C0201
C2, C14: 9pF.1; C0201
C3, C4: 4.7uF.1; C0201
C6, C11, C12, C13, C26, C27, C31, C38, C40, C42, C43, C44, C48: 100nF.1; C0201
C8, C33, C34, C41: 10uF.1; C0402
C16, C20: 4.7uF, 10V.1; C0402
C17, C19, C22: 1uF >10V.1; C0201
C18: 10uF, >4V.1; C0402
C23: 2.2uF.1; C0201
C45, C46: GRM0335C1H330JA01D.1; b5c2858cad4e462ab76a8d0ccf4ade45
C49: C0402C103J3RACAUTO.1; cef4f92115b54348803d28f8706b0456
C50, C52, C54: 1uF; C0402
C51: 0.1uF; C0402
C53: 4.7uF; C0402
C55: 22pF; C0402
C56: 1uF 35V; C0402
CARD1: TF-06A.1; TF-SMD_TF-06A
CN1: BM46B-12DS-0.35V(51).1; FPC-SMD_12P-P0.35_BM46B-12DS-0.35V
CRYSTAL1: CN4024M57620001.1; 6684822644394e4eba542a27714dd8a6
D1: MBR0530T1G; D_SOD-123
D2: PRTR5V0U2F.1; SON-6_L1.5-W1.0-P0.50-BL
J1: CLE-107-01-G-DV.1; CLE-107-01-X-DV
L1: 10uH; L_1210_3225Metric
L2: 2.2uH.1; L0402
LED3: MHPA1010RGBDT.1; LED-ARRAY-SMD_4P-L1.0-W1.0-TR-RD
MDBT531: MDBT53.1; MDBT53
MIC1: CMA-4544PF-W
Q1: CSD23382F4.1; PICOSTAR-3_L1.0-W0.6-P0.35-TL
Q2, Q3: CSD13380F3T.1; PICOSTAR-3_L0.7-W0.6-P0.40-TL
R1, R2, R3, R15, R17, R19, R20: 10kΩ.1; R0201
R4: 510Ω.1; R0201
R5, R9, R10, R11: 2kΩ.1; R0201
R6: 51kΩ.1; R0201
R7, R8: 5.1kΩ.1; R0201
R13: 37.4kΩ, 1%.1; R0402
R21: 10mΩ, 1%.1; R0402
R23, R26: 27Ω.1; R0201
R27: 2.2Ω.1; R0201
R28: RC0201FR-07220RL.1; ea94e26560f84db4a6862024f5c3efa7
R29: 2.2k; R0402
R30: 1.0M; R0402
R31: 160k; R0402
SW1: TS2819A 230GF.1; SW-SMD_4P-L2.8-W1.9-P1.16-LS3.0
U1: BMX160.1; LGA-14_L3.0-W2.5-P0.50-BL
U2: BQ25120AYFPR.1; DSBGA-25_L2.5-W2.6-R5-C5-P0.40-BL
U3, U9: AP22916BCA4-7.1; X1-WLB0808-4_L0.8-W0.8-P0.40-TL
U4: XL-0201SURC.1; LED-SMD_L0.65-W0.35-P0.41_XL-0201SURC
U5: KTD2026.1; DFN-8_L1.5-W1.5-P0.40-BL-EP
U6: BQ27220YZFR.1; DSBGA-9_L1.7-W1.6-R3-C3-P0.50-BL
U8: 1MΩ.1; R0201
U10: SN74AXC4T774RSVR.1; UQFN-16_L2.6-W1.8-P0.40-BL
U12: GT-USB-9047A.1; USB-C-SMD_GT-USB-9047A
U14: MX25R6435FBFIL0.1; WLCSP-22_MX25R6435FBFIL0
U15: TAC5301QRGERQ1; TAC5301-Q1
U16: TPS61040DBVR; SOT-23-5
X1: Q13FC1350000200.1; FC-135R_L3.2-W1.5

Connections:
3V3: C5.2, C17.1, C29.2, C48.1, CN1.3, J1.10, LED3.1, U2.C5, U4.1, U5.5, U9.A2, U15.6, U15.11, U15.23
$1N36: CARD1.8, R19.1
$1N48: R7.2, U12.A5
$1N49: R8.2, U12.B5
$1N65: C10.1, U2.C4
$1N70: C23.2, U6.B3
$1N74: R17.1, U6.B1
$1N98: C3.1, MDBT531.44, R27.2
$1N117: Q2.3, R4.2
$1N119: R4.1, U4.2
$1N151: C31.1, C36.1
$1N16368: C45.1, CRYSTAL1.3, R28.1
+1.8V: C1.2, C4.2, C18.1, C20.2, J1.9, L2.2, MDBT531.38, MDBT531.41, Q1.2, R2.1, R3.1, U2.B5, U3.A2
BCLK: MDBT531.59, U15.2
CC_#CD: MDBT531.26, U2.E2
CC_#PG: MDBT531.16, U2.D4
DIN: MDBT531.60, U15.5
DOUT: MDBT531.56, U15.4
DREG_DECOUPLE: C51.1, U15.1
FB_NODE: C55.2, R30.2, R31.1, U16.3
FLASH_RESET: MDBT531.51, U14.F2
GND: C1.1, C2.1, C3.2, C4.1, C5.1, C6.2, C7.2, C8.1, C9.2, C10.2, C11.1, C12.1, C13.2, C14.1, C16.1, C17.2, C18.2, C19.2, C20.1, C21.1, C22.2, C23.1, C26.2, C27.1, C28.2, C29.1, C31.2, C32.2, C33.1, C34.2, C36.2, C38.1, C40.2, C41.2, C42.1, C43.2, C44.2, C45.2, C46.1, C47.2, C48.2, C49.1, C51.2, C52.2, C53.2, C54.2, C56.2, CARD1.6, CARD1.10, CARD1.11, CARD1.12, CARD1.13, CN1.10, CRYSTAL1.2, CRYSTAL1.4, D2.2, J1.7, MDBT531.1, MDBT531.24, MDBT531.42, MDBT531.61, MIC1.2, Q2.2, Q3.2, R1.2, R6.1, R7.1, R8.1, R17.2, R19.2, R31.2, SW1.3, SW1.4, U1.1, U1.2, U1.3, U1.6, U1.7, U2.A1, U2.A5, U2.C1, U2.C2, U2.D1, U2.D5, U3.B1, U5.8, U5.9, U6.B2, U8.2, U9.B1, U10.6, U10.8, U12.12, U12.13, U12.14, U12.15, U12.A1B12, U12.A12B1, U14.E3, U15.16, U15.25, U15.A1, U15.A2, U15.A3, U15.A4, U16.2
GPOUT: MDBT531.25, U6.A1
HVDD: C54.1, C55.1, D1.2, R30.1, U15.13
INT: MDBT531.14, U2.D2
IO1: J1.11, MDBT531.9
IO2: J1.12, MDBT531.11
IO3: J1.14, MDBT531.13
IO4: CN1.6, MDBT531.35
IO5: CN1.4, MDBT531.21
IO6: CN1.2, MDBT531.15
LED_ENABLE: MDBT531.3, Q2.1, U8.1
LRCLK: MDBT531.57, U15.3
LSCTRL: MDBT531.27, U2.E3
MIC_BIAS: C56.1, R29.1, U15.14
MIC_BIAS_NODE: C50.1, MIC1.1, R29.2
MIC_P: C50.2, U15.15
MR#: Q1.1, SW1.1, SW1.2, U2.E1
ON+BTN: MDBT531.22, Q1.3
RESETN: C49.2, J1.5, MDBT531.6, U2.D3
RGB_B: LED3.4, U5.2
RGB_G: LED3.3, U5.3
RGB_R: LED3.2, U5.4
SCL: MDBT531.8, R3.2, U2.E5, U5.6, U6.A3
SCL1: CN1.12, MDBT531.45, R9.2, U15.7
SCL2: CN1.9, MDBT531.33, R10.2, U1.13
SDA: MDBT531.12, R2.2, U2.E4, U5.7, U6.A2
SDA1: CN1.11, MDBT531.47, R5.2, U15.8
SDA2: CN1.1, MDBT531.31, R11.2, U1.14
SD_ENABLE: MDBT531.53, U9.B2
SD_STATE: MDBT531.23, Q3.3
SD_STATE_3V3: CARD1.G, Q3.1, R1.1
SENSORS_ENABLE: MDBT531.55, U3.B2
SPI_CLK: MDBT531.29, U10.3, U14.H2
SPI_CLK_SD: CARD1.5, U10.10
SPI_CS: MDBT531.17, U10.1, U10.7
SPI_CS_FLASH: MDBT531.43, U14.D4
SPI_CS_SD: CARD1.2, R20.1, U10.12
SPI_MISO: MDBT531.18, U10.4, U14.F4
SPI_MISO_SD: CARD1.7, R15.1, U10.9
SPI_MOSI: MDBT531.19, U10.2, U14.G3
SPI_MOSI_SD: CARD1.3, U10.11
SW: L2.1, U2.A4
SWCLK: J1.1, MDBT531.2
SWDIO: J1.3, MDBT531.4
SW_NODE: D1.1, L1.2, U16.1
TS: R6.2, R13.1, U2.C3
USB_D+: MDBT531.46, R23.2
USB_D-: MDBT531.48, R26.2
USB_DM: D2.1, D2.6, R26.1, U12.A7, U12.B7
USB_DP: D2.3, D2.4, R23.1, U12.A6, U12.B6
VCC: C19.1, R21.2, U2.B1, U2.B2, U6.C2
VREF_DECOUPLE: C52.1, U15.24
VUSB: C22.1, D2.5, R13.2, R27.1, U2.A2, U12.A4B9, U12.A9B4
V_BAT: C21.2, C53.1, L1.1, R21.1, U6.C1, U6.C3, U16.4, U16.5
V_LS: C7.1, C11.2, C12.2, C13.1, C27.2, C33.2, C34.1, C38.2, C40.1, C41.1, C42.2, C43.1, C44.1, C47.1, CN1.8, J1.13, R5.1, R9.1, R10.1, R11.1, U1.5, U1.8, U1.12, U3.A1, U10.5, U10.14, U10.15, U10.16, U14.D2, U14.H4
V_PMID: C9.1, C16.2, U2.A3, U2.B3, U2.B4
V_SD: C6.1, C8.2, C26.1, C28.1, CARD1.4, R15.2, R20.2, U9.A1, U10.13
XL1: C14.2, MDBT531.34, X1.1
XL2: C2.2, MDBT531.36, X1.2
XTALI: C46.2, CRYSTAL1.1

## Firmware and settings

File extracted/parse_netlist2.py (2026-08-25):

#!/usr/bin/env python3
"""
Simpler, more robust net reconstruction: group real-component pins by the
nearest net-label instance (within SNAP radius), then group all pins whose
nearest label shares the same text -- since net-label text IS the net
identity in this kind of schematic, we don't need to trace wire topology.
Calibrated against a known-correct case (MDBT53 pin 60 / P0.28 <-> "DIN"
label, ~5 units apart) -- SNAP=25 gives comfortable margin.
"""
import json, math, re, html
from collections import defaultdict
from parse_symbol import parse_esym

def base_name_of(name):
    # Strip only a trailing ".<digits>" variant suffix (e.g. "5.1kΩ.1" -> "5.1kΩ"),
    # not a naive split on the first dot which mangles decimal values.
    return re.sub(r"\.\d+$", "", name or "")

SNAP = 25.0

# nRF5340 (MDBT53) dedicated DC-DC regulator / decoupling pins. Per the
# nRF5340 datasheet these connect ONLY to a local decoupling capacitor next
# to the pin, never to a routed signal net -- so proximity-based label
# matching produces false positives here (confirmed: DECR(58) picked up the
# neighboring LRCLK label, DCCD(50)/DECD(52) picked up FLASH_RESET/
# SD_ENABLE). Exclude by symbol pin name, not by (designator, pin number),
# so this stays correct if the schematic renumbers pins.
RESERVED_PIN_NAMES = {"DECR", "DCC", "DECD", "DCCD", "DCCH"}
BASE = "stock_openearable"
ESCH = f"{BASE}/SHEET/f608cfd613e24ea7937ea7eb0aab41a1/1.esch"

bom = json.load(open("bom.json"))
proj = json.load(open(f"{BASE}/project.json"))
symbol_title_to_uuid = {info["title"]: uid for uid, info in proj["symbols"].items()}
symbol_title_to_uuid_unescaped = {html.unescape(t): uid for t, uid in symbol_title_to_uuid.items()}

def rotate(x, y, rot):
    rot = (rot or 0) % 360
    if rot == 0: return x, y
    if rot == 90: return -y, x
    if rot == 180: return -x, -y
    if rot == 270: return y, -x
    rad = math.radians(rot)
    return x * math.cos(rad) - y * math.sin(rad), x * math.sin(rad) + y * math.cos(rad)

# 1. absolute pin positions for every real component
symcache = {}
pin_points = []  # (x, y, des, pinnum, pinname)
for des, c in bom.items():
    base_name = base_name_of(c["name"])
    uid = symbol_title_to_uuid.get(base_name) or symbol_title_to_uuid_unescaped.get(base_name)
    if not uid:
        print(f"WARN: no symbol found for {des} ({base_name})")
        continue
    if uid not in symcache:
        try:
            symcache[uid] = parse_esym(f"{BASE}/SYMBOL/{uid}.esym")
        except FileNotFoundError:
            symcache[uid] = {"pins": []}
    for p in symcache[uid]["pins"]:
        if p["name"] in RESERVED_PIN_NAMES:
            continue
        lx, ly = rotate(p["x"], p["y"], c["rot"] or 0)
        pin_points.append((c["x"] + lx, c["y"] + ly, des, p["number"], p["name"]))

# 2. net label instances
attrs_by_comp = defaultdict(dict)
comp_pos = {}
with open(ESCH) as f:
    for line in f:
        line = line.strip()
        if not line:
            continue
        d = json.loads(line)
        if d[0] == "COMPONENT":
            comp_pos[d[1]] = (d[3], d[4])
        elif d[0] == "ATTR" and len(d) > 4:
            attrs_by_comp[d[2]][d[3]] = d[4]

labels = []  # (x, y, name)
for cid, a in attrs_by_comp.items():
    nm = a.get("Name")
    des = a.get("Designator", "")
    fp = a.get("Footprint", "")
    if nm and not des and not fp and cid in comp_pos and "={" not in nm and "Anonymous" not in nm:
        x, y = comp_pos[cid]
        labels.append((x, y, nm))

print(f"{len(pin_points)} pin instances, {len(labels)} net-label instances")

# 3. for each pin, find nearest label within SNAP
def dist2(ax, ay, bx, by):
    return (ax - bx) ** 2 + (ay - by) ** 2

nets = defaultdict(list)
unmatched = []
for px, py, des, pinnum, pinname in pin_points:
    best = None
    bestd = SNAP * SNAP
    for lx, ly, nm in labels:
        d = dist2(px, py, lx, ly)
        if d <= bestd:
            bestd = d
            best = nm
    if best:
        nets[best].append((des, pinnum, pinname))
    else:
        unmatched.append((des, pinnum, pinname, px, py))

print(f"Pins matched to a named net: {sum(len(v) for v in nets.values())}")
print(f"Pins with no nearby label (unlabeled/direct-wire only): {len(unmatched)}")
print(f"Distinct net names: {len(nets)}")

out = {name: sorted(set((d, p) for d, p, _ in members)) for name, members in nets.items()}
json.dump(out, open("netlist.json", "w"), indent=1)
json.dump(
    [{"designator": d, "pin": p, "pin_name": pn, "x": x, "y": y} for d, p, pn, x, y in unmatched],
    open("unmatched_pins.json", "w"), indent=1,
)

print("\n=== nets with >=2 pins ===")
for name, members in sorted(out.items()):
    if len(members) >= 2:
        print(f"{name}: {members}")

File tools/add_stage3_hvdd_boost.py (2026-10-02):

"""
Stage 3 of the TAC5301-Q1 codec swap: the HVDD boost converter.

Real reference design: TI TPS61040 datasheet (SLVS413L) Figure 7-1 "LCD
Bias Supply" -- an 18V-from-battery boost converter using exactly this
topology. Recomputed the feedback divider for Haven's actual 9V HVDD
target (mid-range of the datasheet's required 5.6-12V) instead of the
reference design's 18V, using the datasheet's own formula (Section
7.2.2.2, eq. 5): VOUT = 1.233V * (1 + R1/R2).

Kept R2 = 160kOhm (the reference design's own value, already inside the
datasheet's recommended <=200kOhm range) and solved for R1:
  9V / 1.233V = 7.299 = 1 + R1/160k  ->  R1 = 1.008 MOhm -> 1.0 MOhm (E96)
  Check: 1.233 * (1 + 1000/160) = 8.94V -- inside the 5.6-12V requirement
  with margin on both sides.

Every other component value (L1, D1, CFF, C1, C2) is the datasheet's own
reference design value, unmodified -- Haven's ~1.1mA HVDD load (per the
TAC5301-Q1 datasheet's own reference design) is far below the reference
design's 10mA target, so these are a safe, conservative choice, not
re-optimized for the lower current (deliberately -- no reason to shave
margin here).

BOM this stage:
  U_BOOST (TPS61040, SOT23-5)
  L1 (10uH, e.g. Sumida CR32-100 or equivalent)
  D1 (MBR0530 Schottky)
  R1 (1.0Mohm), R2 (160kOhm) -- feedback divider
  CFF (22pF) -- feedforward, across R1
  C1 (4.7uF) -- input cap
  C2 (1uF) -- output cap

NOT verified this stage (real open items, not silently skipped):
- Real inductor/diode part availability and JLC/LCSC stock
- PCB layout: this is a switching converter, loop area and SW-node
  copper matter a lot for EMI -- schematic-correct is not layout-correct
- EN tied directly to VIN (always-on) -- fine for this design's scope,
  but means HVDD boosts whenever the battery is connected, worth revisiting
  if standby power ever matters

Run from kicad/ directory, after stages 1 and 2.
"""
import uuid as uuidlib

from kiutils.schematic import Schematic
from kiutils.items.common import Position, Property, Effects, Font, Justify, Stroke, Fill
from kiutils.items.schitems import SchematicSymbol, LocalLabel, Rectangle
from kiutils.symbol import Symbol, SymbolPin

SCH_PATH = "haven_dev_board.kicad_sch"


def new_uuid():
    return str(uuidlib.uuid4())


def build_2pin_symbol(entry_name, value):
    top = Symbol(entryName=entry_name)
    top.properties = [
        Property(key="Reference", value=entry_name[0], position=Position(X=-2.54, Y=5.08, angle=0),
                  effects=Effects(font=Font(height=1.27, width=1.27))),
        Property(key="Value", value=value, position=Position(X=-2.54, Y=-5.08, angle=0),
                  effects=Effects(font=Font(height=1.27, width=1.27))),
    ]
    body = Symbol(entryName=entry_name, unitId=0, styleId=1)
    body.graphicItems = [Rectangle(
        start=Position(X=-2.54, Y=-2.54), end=Position(X=2.54, Y=2.54),
        stroke=Stroke(width=0.254, type="default"), fill=Fill(type="background"),
    )]
    pins_unit = Symbol(entryName=entry_name, unitId=1, styleId=1)
    pins_unit.pins = [
        SymbolPin(electricalType="passive", graphicalStyle="line",
                  position=Position(X=0, Y=5.08, angle=180), length=2.54,
                  name="1", number="1",
                  nameEffects=Effects(font=Font(height=1.27, width=1.27)),
                  numberEffects=Effects(font=Font(height=1.27, width=1.27)), hide=False),
        SymbolPin(electricalType="passive", graphicalStyle="line",
                  position=Position(X=0, Y=-5.08, angle=0), length=2.54,
                  name="2", number="2",
                  nameEffects=Effects(font=Font(height=1.27, width=1.27)),
                  numberEffects=Effects(font=Font(height=1.27, width=1.27)), hide=False),
    ]
    top.units = [body, pins_unit]
    return top


def place_2pin(sch, ref, entry_name, x, y, net1, net2):
    inst = SchematicSymbol(
        libraryNickname="haven_dev_board", entryName=entry_name,
        position=Position(X=x, Y=y, angle=0), unit=1, uuid=new_uuid(),
        properties=[
            Property(key="Reference", value=ref, position=Position(X=x - 2.54, Y=y + 5.08, angle=0),
                      effects=Effects(font=Font(height=1.27, width=1.27))),
            Property(key="Value", value=entry_name.split("_", 1)[1] if "_" in entry_name else "",
                      position=Position(X=x - 2.54, Y=y - 5.08, angle=0),
                      effects=Effects(font=Font(height=1.27, width=1.27))),
        ],
    )
    sch.schematicSymbols.append(inst)
    sch.labels.append(LocalLabel(text=net1, position=Position(X=x, Y=y + 5.08, angle=0),
                                  effects=Effects(font=Font(height=1.27, width=1.27), justify=Justify(horizontally="left")),
                                  uuid=new_uuid()))
    sch.labels.append(LocalLabel(text=net2, position=Position(X=x, Y=y - 5.08, angle=0),
                                  effects=Effects(font=Font(height=1.27, width=1.27), justify=Justify(horizontally="left")),
                                  uuid=new_uuid()))


def build_tps61040_symbol():
    top = Symbol(entryName="TPS61040")
    top.properties = [
        Property(key="Reference", value="U", position=Position(X=-7.62, Y=10.16, angle=0),
                  effects=Effects(font=Font(height=1.27, width=1.27))),
        Property(key="Value", value="TPS61040DBVR", position=Position(X=-7.62, Y=-10.16, angle=0),
                  effects=Effects(font=Font(height=1.27, width=1.27))),
    ]
    body = Symbol(entryName="TPS61040", unitId=0, styleId=1)
    body.graphicItems = [Rectangle(
        start=Position(X=-7.62, Y=7.62), end=Position(X=7.62, Y=-7.62),
        stroke=Stroke(width=0.254, type="default"), fill=Fill(type="background"),
    )]
    pins_unit = Symbol(entryName="TPS61040", unitId=1, styleId=1)
    # SOT23-5, DBV package (Figure 4-1): SW=1, GND=2, FB=3, EN=4, VIN=5
    pin_defs = [
        ("SW", "1", -10.16, 5.08, 0),
        ("GND", "2", -10.16, -5.08, 0),
        ("FB", "3", 10.16, -5.08, 180),
        ("EN", "4", 10.16, 0, 180),
        ("VIN", "5", 10.16, 5.08, 180),
    ]
    pins_unit.pins = [
        SymbolPin(electricalType="passive", graphicalStyle="line",
                  position=Position(X=x, Y=y, angle=angle), length=2.54,
                  name=name, number=num,
                  nameEffects=Effects(font=Font(height=1.27, width=1.27)),
                  numberEffects=Effects(font=Font(height=1.27, width=1.27)), hide=False)
        for name, num, x, y, angle in pin_defs
    ]
    top.units = [body, pins_unit]
    return top


def main():
    sch = Schematic.from_file(SCH_PATH)

    sch.libSymbols.append(build_tps61040_symbol())
    for entry_name, value in [
        ("L_10uH", "10uH"), ("D_MBR0530", "MBR0530"),
        ("R_1.0M", "1.0M"), ("R_160k", "160k"),
        ("C_22pF_ff", "22pF"), ("C_4.7uF_in", "4.7uF"), ("C_1uF_out", "1uF"),
    ]:
        sch.libSymbols.append(build_2pin_symbol(entry_name, value))

    ic_pos = Position(X=550.0, Y=140.0, angle=0)
    ic = SchematicSymbol(
        libraryNickname="haven_dev_board", entryName="TPS61040",
        position=ic_pos, unit=1, uuid=new_uuid(),
        properties=[
            Property(key="Reference", value="U16", position=Position(X=ic_pos.X, Y=ic_pos.Y - 12, angle=0),
                      effects=Effects(font=Font(height=1.27, width=1.27))),
            Property(key="Value", value="TPS61040DBVR", position=Position(X=ic_pos.X, Y=ic_pos.Y + 12, angle=0),
                      effects=Effects(font=Font(height=1.27, width=1.27))),
        ],
    )
    sch.schematicSymbols.append(ic)

    def lbl(text, x, y):
        sch.labels.append(LocalLabel(text=text, position=Position(X=x, Y=y, angle=0),
                                      effects=Effects(font=Font(height=1.27, width=1.27), justify=Justify(horizontally="left")),
                                      uuid=new_uuid()))

    # IC pins: SW(-10.16,5.08) GND(-10.16,-5.08) FB(10.16,-5.08) EN(10.16,0) VIN(10.16,5.08)
    lbl("SW_NODE", ic_pos.X - 10.16, ic_pos.Y + 5.08)
    lbl("GND", ic_pos.X - 10.16, ic_pos.Y - 5.08)
    lbl("FB_NODE", ic_pos.X + 10.16, ic_pos.Y - 5.08)
    lbl("V_BAT", ic_pos.X + 10.16, ic_pos.Y)       # EN tied to V_BAT: always enabled
    lbl("V_BAT", ic_pos.X + 10.16, ic_pos.Y + 5.08)  # VIN

    # L1: V_BAT -> SW_NODE
    place_2pin(sch, "L1", "L_10uH", 520.0, 110.0, "V_BAT", "SW_NODE")
    # D1: SW_NODE -> HVDD (anode at SW_NODE, cathode at HVDD -- polarity is a
    # real PCB-layout/footprint-orientation detail, not captured by this
    # generic 2-pin passive template; flagged for the layout stage)
    place_2pin(sch, "D1", "D_MBR0530", 560.0, 110.0, "SW_NODE", "HVDD")
    # C1: input cap, V_BAT -> GND, near the IC
    place_2pin(sch, "C53", "C_4.7uF_in", 535.0, 160.0, "V_BAT", "GND")
    # C2: output cap, HVDD -> GND
    place_2pin(sch, "C54", "C_1uF_out", 580.0, 140.0, "HVDD", "GND")
    # R1 (top of divider): HVDD -> FB_NODE
    place_2pin(sch, "R30", "R_1.0M", 580.0, 170.0, "HVDD", "FB_NODE")
    # R2 (bottom of divider): FB_NODE -> GND
    place_2pin(sch, "R31", "R_160k", 580.0, 200.0, "FB_NODE", "GND")
    # CFF: feedforward cap in parallel with R1, HVDD -> FB_NODE
    place_2pin(sch, "C55", "C_22pF_ff", 595.0, 170.0, "HVDD", "FB_NODE")

    # MICBIAS decoupling: 1uF/35V, value straight from the TAC5301-Q1
    # datasheet's own Figure 8-1 reference circuit (the ">25V rating"
    # layout guideline is for the chip's own full 3-10V MICBIAS range,
    # not specific to what we actually program it to -- using TI's own
    # cited value rather than re-deriving a lower rating for our case).
    sch.libSymbols.append(build_2pin_symbol("C_1uF_35V_micbias", "1uF 35V"))
    place_2pin(sch, "C56", "C_1uF_35V_micbias", 610.0, 140.0, "MIC_BIAS", "GND")

    sch.to_file(SCH_PATH)
    print("Wrote", SCH_PATH)


if __name__ == "__main__":
    main()

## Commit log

2026-08-25 Extract BOM + reconstruct netlist from stock OpenEarable EasyEDA export
    68 named nets, 290/452 pins matched via net-label proximity matching.
    Fixed symbol-lookup bug (decimal values truncated by naive dot-split;
    HTML-entity mismatch between BOM names and symbol titles) and a false-
    positive bug where nRF5340 reserved DC-DC/decoupling pins (DECR/DCC/
    DECD/DCCD/DCCH) were bleeding into neighboring signal nets via proximity
    matching.
    [parse_netlist2.py]
2026-08-25 Generate KiCad PCB: real footprints, placement, routing, board outline
    Discovered the .epcb PCB layer stores authoritative, already-resolved
    per-pad net assignments (PAD_NET records) and real component placement
    (COMPONENT records) -- ground truth, not a reconstruction, superseding
    the schematic-proximity netlist heuristic for PCB purposes. Also found
    genuine routed copper (LINE/VIA/POUR records) on a real 6-layer stackup
    (TOP / GND plane / Inner1 / Inner2 / POWER plane / BOTTOM), confirmed via
    LAYER_PHYS dielectric/copper thickness records.
    Extracted and validated:
    - 33 real footprints (RECT/ELLIPSE/OVAL/POLY pad shapes) from .efoo files
    into a project .pretty library.
    - PCB-space rotati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
    [haven_dev_board.kicad_pcb]
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2026-08-26 Hardware review: audit own KiCad output, cross-check firmware overlay
    Independent audit (extracted/sexp_parser.py, audit_schematic.py,
    audit_pcb.py -- parse the actual generated .kicad_sch/.kicad_pcb, not the
    generator's in-memory state) found and fixed two exact-duplicate net
    labels (coincidental same-coordinate pins, zero connectivity change).
    Logged 67 dangling pins and the placeholder-UUID scheme as reviewed but
    not touched (all dangling pins spot-checked as genuine NC/unused, not
    parsing bugs).
    Cross-checked the current firmware overlay's I2C1/I2S pin claims against
    the port's actual schematic: all 6 net-name/pin-number pairs match
    exactly. Direction/master-slave claims could NOT be ve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
    [haven_dev_board.kicad_sch]
2026-08-26 Generate HAVEN_BOM.csv from real sourced data (no fabricated MPNs)
    48 grouped lines covering all 89 components, sourced in priority order:
    1. OpenEarable's own official BOM spreadsheet
    (haven_workspace/hardware/openearable_base_pcb/OpenEarable-PCB-main-2.0,
    read-only) -- 7 lines, including 2 (J1, MDBT531) where even that BOM
    left Manufacturer/MPN blank.
    2. Per-designator Manufacturer/Manufacturer-Part attrs carried through the
    .epro export into the KiCad port's own bom.json -- 82 lines, matches
    the official BOM exactly wherever both exist.
    Every one of the 89 components resolved to a real, verifiable MPN --
    none needed the representative/example fallback or a 'needs sourcing'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
    [HAVEN_BOM.csv]
2026-08-26 Fix U1 part label: BMX160 -> BMI160 (no magnetometer on this board)
    The schematic's Value property said BMX160 (Bosch 9-axis IMU, has an
    on-die magnetometer) while the sourced Manufacturer Part in the BOM was
    BMI160 (6-axis, no magnetometer) -- a real mismatch flagged earlier as
    unresolved, since both packages/pinouts are identical and don't
    disambiguate on their own.
    Resolved by checking the actual wiring: U1 pins 2/3 (ASDX/ASCX, BMI160's
    external-magnetometer aux interface) are tied to GND, which is BMI160's
    own documented "aux interface unused" reference pattern. BMX160 has no
    equivalent external aux-mag pins to ground -- its magnetometer is on-die
    using that interface internally -- so t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
    [HAVEN_BOM.csv, haven_dev_board.kicad_sch]
2026-08-27 Fix via geometry and board outline defects (real KiCad 9 DRC, not guessed)
    Ran real DRC for the first time on this board (KiCad 6 -> 9 upgrade was
    needed just to get kicad-cli at all). Found 1746 violations. Two were
    systemic and now fully resolved:
    1. Every via on the board (260/260) had drill diameter > pad size
    (e.g. size=0.15mm, drill=0.25mm) -- physically invalid, negative
    annular ring, confirmed by DRC itself. Tried replacing with a uniform
    "safe" 0.45mm/0.2mm spec first; that made clearance/shorting
    violations WORSE (the layout's actual trace spacing assumes much
    smaller vias). Root cause is almost certainly that the size/drill
    fields were transposed during the orig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
    [haven_dev_board.kicad_pcb]
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2026-08-27 Fix overlapping same-footprint pads via rotation (LED3, U1/IMU)
    Found via visual inspection + a general same-footprint bbox-overlap
    check: LED3 (RGB LED) and U1 (IMU, LGA-14 0.5mm pitch) had adjacent pads
    of different nets physically overlapping -- a real short, not routing
    noise. Root cause: pads were generated with one uniform rectangle
    (matching the pitch correctly on one pair of edges) but never rotated
    90 degrees for the perpendicular edges, so e.g. U1's top/bottom-row pads
    had their long axis running the wrong way relative to their own pitch.
    Fix: for every same-footprint, different-net pad pair whose bounding
    boxes actually overlap, rotate both pads 90 degrees and verify the
    overlap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
    [haven_dev_board.kicad_pcb]
2026-08-28 Rescale board 5x and re-route with Freerouting (real autorouter)
    The board was cramped into the original wearable's 14.6x32.2mm footprint,
    which caused most of the ~930 remaining DRC violations (clearance/shorting
    issues from sheer density, not routing mistakes). Since this is a bench
    dev board, not the final wearable, there's no reason to keep that
    constraint.
    Tried three approaches to "just make it bigger" before finding one that
    works, documented here since the failures are informative:
    1. Pure uniform coordinate scaling of the whole board: mathematically
    guarantees no new trace crossings, but also scales each component's
    own internal pin pitch -- the IMU's real 0.5mm pitch would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
    [haven_dev_board.kicad_pcb]
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2026-08-29 Add MDBT53 antenna keepout: real ground copper cleared, per datasheet
    The #1 finding from the original hardware review: real GND copper sat
    directly under/around the BLE module's antenna, where Raytac's own
    datasheet requires a clear zone. This was flagged early but left
    unresolved since fixing it required either the datasheet's mechanical
    drawing (couldn't render PDFs in this environment until now, poppler-
    utils just got installed) or Raytac's paid review service.
    Downloaded the actual Raytac MDBT53 datasheet and read the real
    mechanical pages directly (section 2.3, "RF Layout Suggestion (aka
    Keep-Out Area)"): 3.7mm deep, along the module's full 9.3mm short edge
    where pins 1 and 61 (both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
    [haven_dev_board.kicad_pcb]
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2026-09-09 Close R8/U6 GND link via dual small through-vias into the existing plane
    Picked up from Codex's session6 handoff (first of three identified
    candidates: R8, C10, R28). U6.B2 is the center pad of a 3x3 BGA-style
    grid, fully enclosed -- not reachable by a routed trace, same class of
    problem as the harder BGA balls. Found a GND zone on In1.Cu/In2.Cu
    already covers both pad locations, so the fix is two through-vias
    dropping each pad into that plane rather than a point-to-point trace.
    R8's via is sized down to 0.20mm pad/0.10mm drill (vs. the usual
    0.30/0.15mm) since its own two pins are only ~0.48mm apart -- the
    standard size collided with R8's own pin 2.
    Real mistakes made and caught before co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
    [haven_dev_board.kicad_pcb]
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2026-09-10 Escape 14 MDBT531 pins + targeted Freerouting pass: 67->61 links, 43->41 nets
    Long writeup in CODEX_NOTES.md with three real mistakes made and fixed
    along the way (worth reading in full if picking this up next):
    Freerouting only writes .ses output at job completion, so killing a
    plateaued run loses the whole result, not just the extra passes;
    running kicad-cli pcb drc on a copy outside the real project directory
    silently loses footprint library resolution (89 false-positive
    "lib_footprint_issues" from this, not a real problem); and cleaning up
    router-introduced garbage stub tracks by net+length instead of exact
    UUID matched non-uniquely and deleted 16 legitimate tracks instead of
    the intende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
    [haven_dev_board.kicad_pcb]
2026-09-10 Close LSCTRL end to end via F.Cu->via->B.Cu route (61->60 links)
    MDBT531 pin27's F.Cu escape stub was in a pocket sealed by the module's
    own pad wall, the neighboring column, and an existing IO5 track -- no
    viable F.Cu path out. B.Cu was much more open at the same location, so
    the fix is a single through-via off the F.Cu stub onto B.Cu, then a
    ~39mm B.Cu run (A* pathfinder using real KiCad shape collision, not a
    circle approximation) to U2's existing B.Cu-side stub. U2 pad E3 also
    only has one clear escape angle (180 degrees) at its BGA pitch; swapped
    the previous 165-degree stub for that.
    DRC: 330 violations / 60 unconnected (was 330/61) -- LSCTRL fully
    connected, zero new violations of an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
    [haven_dev_board.kicad_pcb]
2026-09-10 Fix GND/\$1N70 short at C23 (real via-to-pad overlap, pre-existing)
    GND via near C23 physically overlapped pad 2 (\$1N70) -- not just a
    clearance shortfall, the via's copper circle extended past the pad
    boundary (confirmed by exact geometry, matches DRC's shorting_items
    classification rather than plain clearance). Moved the via 0.25mm to
    a position clear on all six layers, moved its three connected GND
    track endpoints to match.
    DRC: 330->326 violations (short + a solder-mask bridge + a hole-
    clearance violation at the same spot all resolved together), 0 new,
    unconnected count unchanged (this was never a connectivity issue).
    [haven_dev_board.kicad_pcb]
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2026-09-10 Add per-net clearance exceptions; route DIN, DOUT (55 unconnected)
    haven_dev_board.kicad_dru adds a scoped clearance override per net
    (not a global rule change) for pads that are geometrically enclosed
    at the board's default 0.20mm net-class clearance -- values chosen
    from an exhaustive escape-angle sweep at each pad, documented in
    CODEX_NOTES.md. DIN and DOUT both open at the board's own already-
    declared 0.15mm floor and route cleanly once the exception applies;
    routed both (F.Cu escape -> via -> B.Cu long run -> via -> F.Cu
    approach), each via the board's 0.09mm minimum trace width.
    Caught and fixed a same-batch mistake: DIN and DOUT were first routed
    independently and ended up shorting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
    [haven_dev_board.kicad_pcb]
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2026-09-10 Route SPI_MISO to U10.4 (51 unconnected, was 52)
    Built a proper multi-layer A* pathfinder (states are (x,y,layer), edges
    are same-layer moves or a via hop at any point where via placement is
    legal) instead of hand-picking bridge points net by net -- this is what
    SPI_CS and the first SPI_CLK attempts were missing: a bridge point good
    for one net isn't necessarily open once other nets have placed their
    own copper through the same pocket. Found a real 3-via path to U10.4
    in ~17s at the board's standard 0.20mm clearance (this net was never
    actually blocked -- both far-end pads had confirmed open escape lanes
    from the start, it just needed a router that could hop layers freely).
    Caught two mista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
    [haven_dev_board.kicad_pcb]
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2026-09-10 Route SPI_CS end to end (49 unconnected, was 51)
    Used the multi-layer pathfinder (see previous commit) to reach U10 pin
    1 -- found a real 3-segment B.Cu/F.Cu/B.Cu path at standard 0.20mm
    clearance, this net was never actually blocked, just needed a router
    that could hop layers freely instead of hand-picked bridge points.
    Then closed U10's own internal pin1<->pin7 link (a plain B.Cu net was
    never routed between them).
    Caught a genuine precision bug while landing the first segment: the
    existing MDBT531-side escape stub ends at y=67.91683mm, but every
    script this session referencing that stub's coordinates (going back to
    when it was first placed) used a truncated 67.9168 -- a 30nm gap at
    KiCad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
    [haven_dev_board.kicad_pcb]
2026-09-10 Route SPI_MOSI's U10.2 branch (48 unconnected, was 49)
    U10.2 had a real, confirmed escape lane at standard 0.20mm clearance
    (unlike its other target) -- multi-layer pathfinder found a 5-segment
    B.Cu/F.Cu route in ~15s. Added the junction via the stub needed to
    transition from the existing F.Cu escape stub onto the new route
    (same class of miss as SPI_CS's junction fix last commit -- checked
    for it explicitly this time before placing).
    U14.G3, SPI_MOSI's other required pin, is confirmed a genuine dead
    pocket: even at the board's most aggressive already-defined exception
    (0.05mm), the opening closes back up by 1.2mm out in every direction.
    No via-in-pad option either. This one stays on the bl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
    [haven_dev_board.kicad_pcb]
2026-09-10 Route TCK (JTAG); add TDI/TDO/TMS exceptions for follow-up (47 unconnected)
    Discovered this tick: the conversation's routing scope only ever
    covered the 14 MDBT531 signals plus 3 originally-flagged BGA pads, but
    the board has 32 distinct nets across its 48 remaining unconnected
    items -- a JTAG-looking group (TCK/TDI/TDO/TMS, U15 to J1), several
    power/ground links, an I2S/PDM audio group, and a few oddities
    ($1N151, #ERROR on Q2 -- the latter looks like a broken net reference
    from schematic sync, not routed, flagged for the user rather than
    guessed at).
    TCK, TDI, TDO, TMS all showed a real 1.2mm+ escape reach at 0.15mm
    clearance before anything was routed -- genuine through-paths, not
    dead p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
    [haven_dev_board.kicad_pcb]
2026-09-10 Connect GND to CRYSTAL1.2 (46 unconnected, was 47)
    Real escape lane, standard 0.20mm clearance -- via + short B.Cu run
    from an existing F.Cu stub to the crystal's ground pad.
    Caught a mistake before it landed: first attempt placed the track at
    0.15mm width without re-verifying clearance at that width (had only
    checked the standard 0.09mm probe) -- 4 new clearance violations at
    0.17-0.18mm actual against unrelated copper. Reverted, re-verified at
    the actual placed width, redid it at 0.09mm to match. Zero new
    violations on the second attempt.
    DRC: 284 violations (unchanged), 47->46 unconnected.
    [haven_dev_board.kicad_pcb]
2026-09-10 Bridge V_PMID's B.Cu stub to its In3.Cu plane track (45 unconnected)
    Two existing fragments of the same net needed joining, not a pad
    connection -- a via + short In3.Cu segment from the dangling B.Cu stub
    down onto the existing long In3.Cu plane run. Verified both the via
    placement and the connecting segment before placing.
    DRC: 284 violations (unchanged), 46->45 unconnected, 0 new violations.
    [haven_dev_board.kicad_pcb]
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2026-09-10 Connect GND to Q2 pin 2 (44 unconnected, was 45)
    Q2.2 (GND) was fully enclosed by Q2's own pin 3 ($1N117) at standard
    0.20mm clearance in every direction, but opens to a real 1.5mm-deep
    escape at 0.15mm. Since GND is a pervasive net, a blanket exception
    would loosen clearance everywhere GND runs near anything else on the
    board -- scoped the .kicad_dru rule to the exact pair instead
    (GND vs $1N117 only), so it can't affect GND's clearance anywhere
    else. Straight via + short F.Cu jog from the existing In1.Cu stub.
    DRC shows one violation relabeled (same Q2 pin-2/pin-3 pad-to-pad gap
    that already existed, now reported under the new named rule instead
    of the generic Default netclass rule since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
    [haven_dev_board.kicad_pcb]
2026-09-10 Connect 3V3 to U2.C5 (43 unconnected, was 44)
    Real escape lane confirmed at standard 0.20mm clearance -- multi-layer
    pathfinder found the F.Cu run instantly, but its endpoint landed on
    U2.C5's XY coordinate on the wrong layer (F.Cu, empty board there --
    the real pad is B.Cu only), same class of miss as earlier sessions.
    Fixed with a via + short B.Cu jog to the actual pad.
    DRC: 284 violations (unchanged), 44->43 unconnected, 0 new violations.
    [haven_dev_board.kicad_pcb]
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2026-09-10 Connect V_LS via to U14.D2 (42 unconnected, was 43)
    Real escape lane on B.Cu at standard 0.20mm clearance -- D2 is F.Cu
    only, so added the via + short F.Cu jog rather than trusting the
    B.Cu pathfind's "ok" result at D2's XY (same wrong-layer class of
    issue as before, checked for explicitly this time).
    U14.H4<->D2 (both V_LS, adjacent U14 pads) and the two U10-area B.Cu
    V_LS stubs remain unconnected -- H4's only real escape direction
    points away from D2, and the U10 stubs sit on the far side of the
    same tightly-packed SPI bus wall that's blocked several other nets
    this session. U15's three internal V_LS pairs (A2/B5, F3/G2, F3/F7)
    are confirmed unroutable -- pad center itself blocked at stan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
    [haven_dev_board.kicad_pcb]
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2026-09-10 Add the shared routing pathfinder tools to the repo (tools/)
    These have been the actual mechanism behind every routing fix this
    session (LSCTRL onward) but only ever existed in a scratchpad outside
    the repo -- invisible to Codex, Luna, or a future session picking this
    up. Committing them so the coordination pattern this project already
    uses (CODEX_NOTES.md, shared branch) actually includes the tools, not
    just the log of what they did.
    route_lib.py: single-layer A* pathfinding, escape-depth sweeps, via
    placement checks, and the mixed-clearance variants (collect_obstacles_
    mixed / astar_mixed / simplify_mixed) for routing past one specific
    tight neighbor net without loosening clearance agains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
    [route_lib.py]
2026-09-10 Route SCL, MDBT531 to U5 (41 unconnected, was 42)
    A 17th MDBT531 signal never in the original tracked list -- SCL and
    SDA both connect MDBT531 directly to U5, discovered only by scanning
    the DRC unconnected-items list broadly rather than trusting the
    session's earlier net list. Extensive existing routing already
    existed between the MDBT531 stub and other points (from earlier
    Codex/Luna work), but never actually reached U5 -- confirmed via real
    pathfinding, not assumed from the copper's presence.
    Real escape lanes on both ends at standard 0.20mm clearance; the long
    (~52mm) run needed the multi-layer pathfinder (single-layer attempts
    on both F.Cu and B.Cu exhausted without a path).
    Two real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
    [haven_dev_board.kicad_pcb]
2026-09-10 Close 3V3 end to end: CN1.3 branch routed (40 unconnected, was 41)
    Added the second exception this needed (3V3 vs SDA2, 0.10mm -- an
    existing SDA2 via sits 0.1022mm from the route's path, confirmed
    already, independently correct regardless of the route's fate) on
    top of the existing PDMCLK one. Both together still didn't let
    astar_mixed find a full path from the far stub straight through to
    the CN1.3 pad -- traced it to the same early-exit imprecision
    documented for SCL: the only real escape angle (80 degrees) is a
    single narrow lane, and pathfinding to the raw pad target kept
    missing it. Fixed the same way as SCL: pathfind to the confirmed
    escape point instead of the pad, verify a real conn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
    [haven_dev_board.kicad_pcb]
2026-09-10 Build a bus-aware router; confirms TDI/TDO/TMS are genuinely blocked
    Added tools/bus_router.py: routes a group of related nets together
    (hardest-first ordering, each member seen as a real obstacle by
    whichever routes after it) instead of one at a time, which is what
    TCK/TDI/TDO/TMS actually needed -- net-by-net routing let TCK claim
    the one shared escape lane and left the other three with nothing.
    Two real bugs caught and fixed while building it, before trusting any
    output: the endpoint-layer-fix helper computed a via position but
    never added the actual connecting jog track to reach it (would have
    silently disconnected the via from the true pad); and the single-layer
    fast path was skipped w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
    [haven_dev_board.kicad_pcb]
2026-09-10 Route SDA (MDBT531-U5): fix a real zone-clearance workflow gap
    The MDBT531-to-U5 SDA link was previously reported as walled off (a
    flood-fill from the MDBT531 side supposedly reached only a tiny 6x4mm
    pocket). Re-running a full-region flood-fill this session found that
    claim was stale/wrong -- the whole path between MDBT531 and U5 is
    reachable, and multilayer_astar finds a real route.
    Placing it first surfaced a genuine, previously-unknown gap: two of the
    board's four inner layers are near-full-board GND pours, and via_clear
    never checked vias against filled zone copper at all -- only pads and
    tracks. Adding a via near U5 triggered 8 new zone-clearance violations
    (23 instances) on the first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
    [haven_dev_board.kicad_pcb]
2026-09-10 Close SDA's second gap: U2.E4 to the existing In3.Cu run
    U2 is the same DSBGA-25 (0.4mm pitch) package as the previously
    catalogued TS/\$1N65/INT/CC_#PG dead pockets, but E4 sits on the
    package's edge column rather than fully interior -- an escape-angle
    sweep at standard 0.20mm clearance found a real, consistently open
    lane due west (165-195 degrees) out to 0.5mm, unlike those interior
    pads which close back up even at 0.05mm.
    Routed pad -> B.Cu escape -> via -> In3.Cu -> a T-junction landing
    directly on the existing SDA track KiCad already had connecting U6.A2
    to R2. Every connecting segment (including the two near-target hops
    introduced by the pathfinder's 1.5mm early-exit imprecision) ver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
    [haven_dev_board.kicad_pcb]
2026-09-10 Close V_LS's U14.H4-D2 gap; catch a real via_clear gap
    U14 is a WLCSP-22 (fine-pitch) flash chip -- H4 and D2 each have real
    but narrow escape lanes pointing away from each other, so this needed
    a via at each end bridging to a B.Cu backbone between them.
    First placement attempt created a new via 0.023mm from a pre-existing
    same-net V_LS via nearby (holes essentially overlapping) -- caught by
    real DRC (hole_to_hole, required 0.1995mm, actual 0.0000mm). via_clear
    only ever checked OTHER-net copper (correct for electrical clearance)
    but never checked mechanical hole-to-hole spacing against a same-net
    via it's fine to sit right next to electrically. Reverted immediately.
    D2's own escape cone t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
    [haven_dev_board.kicad_pcb]
2026-09-10 Add hole-to-hole spacing checks; document this session's sweep
    route_lib.hole_to_hole_ok() and find_clear_via_near() now check
    mechanical drill spacing against every existing via regardless of net,
    alongside via_clear()'s electrical (other-net) check -- neither one
    substitutes for the other, confirmed by the V_LS/U14 hole_to_hole
    violation this session. Same fix applied to multilayer_route.py's two
    inline via-hop checkers, which don't call route_lib's via_clear.
    Also documents the escape-sweep results for this session's remaining
    unconnected nets: six more confirmed genuinely blocked (LRCLK, BCLK,
    DAC_ENABLE, XTALI, SCL1, PDMCLK -- all U15 BGA-interior, matching the
    established dead-pocket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
    [route_lib.py]
2026-09-10 Route SCL2's CN1.9 side; fix a rule/route clearance mismatch
    CN1.9's escape was previously diagnosed as boxed in by 5 obstacles
    including 2 unexceptable NC pins -- re-swept fresh since other nets'
    copper (SDA1 especially) has since been routed where it wasn't before,
    and the picture is now simpler: 3 real named-net obstacles (SDA1,
    PDMDIN, PDMCLK), no NC pins at all. Added scoped .kicad_dru exceptions
    for each -- the SDA1 and PDMDIN ones each independently resolved a
    real pre-existing violation on their own (the connector's own 0.35mm
    pitch already put CN1.9 too close to its neighbors at standard
    clearance, regardless of routing).
    At 0.10mm these three still weren't enough for astar_mixed t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
    [haven_dev_board.kicad_pcb]
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
